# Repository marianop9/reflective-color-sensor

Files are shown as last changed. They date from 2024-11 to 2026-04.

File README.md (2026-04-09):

# Sensor de Colores por Reflexión

Este proyecto consiste en el diseño e implementación de un **sensor de color de bajo costo** capaz de estimar el color de una superficie y representarlo en formato RGB de 24 bits. El sistema utiliza una fotorresistencia (LDR) como transductor principal, compensando sus limitaciones mediante un proceso de caracterización empírica y un circuito de acondicionamiento activo.

## Características Principales
* **Hardware:** Basado en el microcontrolador **RP2040** (Raspberry Pi Pico).
* **Iluminantes:** LEDs RGB direccionables **WS2812**, controlados mediante el hardware PIO del RP2040 para máxima precisión.
* **Acondicionamiento:** Circuito de ganancia programable utilizando el switch bilateral **CD4066**, permitiendo medir un amplio rango de resistencias del LDR (1 k&Omega; a 1 M&Omega;) sin saturación.
* **Software:** Firmware desarrollado en C con **FreeRTOS** y **TinyUSB**. Aplicación de control en Python (CLI) para procesamiento de datos.



## Principio de Funcionamiento

El sensor opera utilizando la **reflexión secuencial**. El proceso se divide en los siguientes pasos:

1. **Aislamiento:** La carcasa diseñada bloquea la luz ambiente para evitar interferencias en la medición.
2. **Iluminación:** El dispositivo enciende secuencialmente los canales Rojo, Verde y Azul de los LEDs.
3. **Detección:** El LDR recibe la luz reflejada por la superficie. Su resistencia cambia según la intensidad recibida, y el circuito de acondicionamiento convierte este cambio en una tensión medible por el ADC.
4. **Procesamiento:** El microcontrolador envía los valores a una PC vía USB (CDC), donde se calcula el color final aplicando los parámetros de calibración.

## Caracterización y Calibración del LDR

Dado que los LDR presentan baja trazabilidad y una respuesta no lineal que varía según la longitud de onda , se implementó un procedimiento de **calibración por mínimos cuadrados**.

### El Modelo
Se modela la conductancia ($G$) del LDR en función de la intensidad de la luz ($c$) mediante la ecuación:
$$G = K_a c^{\gamma}$$
Donde $K_a$ y $\gamma$ son parámetros específicos para cada color y cada componente individual.

### Proceso de Calibración
1. Se realiza un **barrido logarítmico de intensidad** (de 0 a 255) para cada canal (R, G, B) sobre una superficie blanca de referencia.
2. Se recolectan las muestras de tensión y se ajusta automáticamente la ganancia ($R_f$) para mantener la señal en la zona lineal del ADC.
3. Mediante un script de Python, se aplica la técnica de **mínimos cuadrados** sobre los datos para hallar los coeficientes $K_a$ y $\gamma$ para cada color por separado.
4. Estos coeficientes se guardan en un archivo JSON que la aplicación CLI utiliza para convertir las mediciones posteriores en códigos de color precisos.

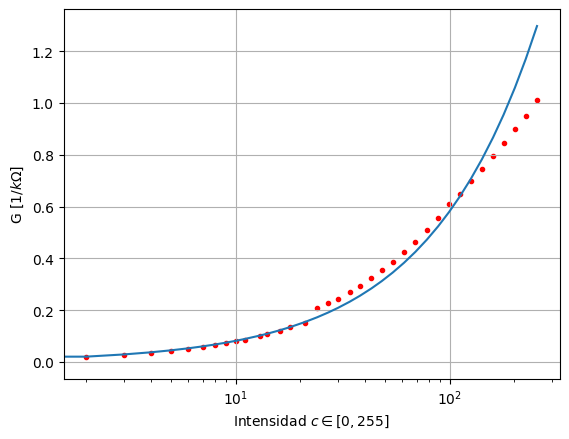
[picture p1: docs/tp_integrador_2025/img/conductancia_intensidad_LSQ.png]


## Estructura del Repositorio
* `/firmware`: Código fuente en C para el RP2040 (Pico-SDK).
* `/scripts`: Contiene la Aplicación CLI en Python y varios scripts de procesamiento de datos.
* `/hardware`: Modelado de las carcasas del dispositivo para impresión 3D.
* `/circuitos`: Esquemáticos del circuito de acondicionamiento y simulaciones en LTSpice.
* `/docs`: Informes técnicos detallados del proyecto.

## Resultados

Utilizando la siguiente hoja de prueba, se tomaron medidas de las superficies de color utilizando distintas aplicaciones móviles, bajo distintas condiciones de iluminación ambiente, y se compararon con las medidas obtenidas con el dispositivo.

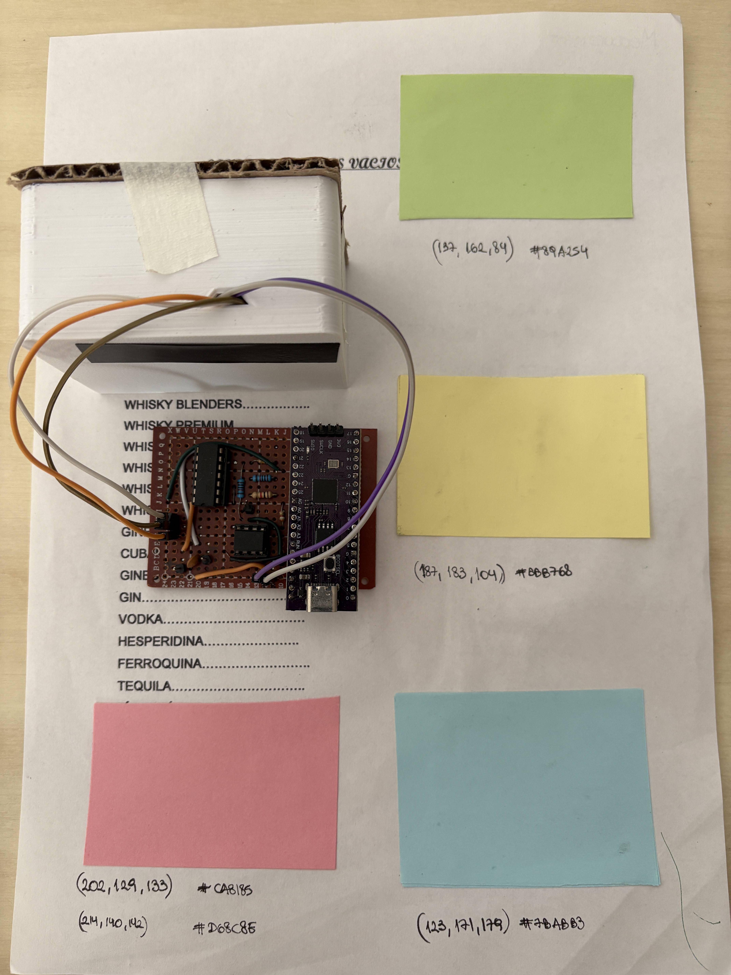
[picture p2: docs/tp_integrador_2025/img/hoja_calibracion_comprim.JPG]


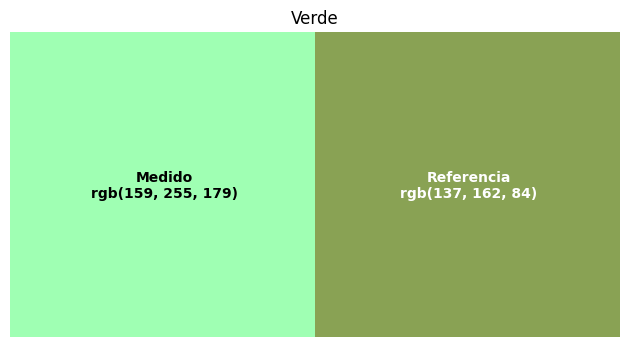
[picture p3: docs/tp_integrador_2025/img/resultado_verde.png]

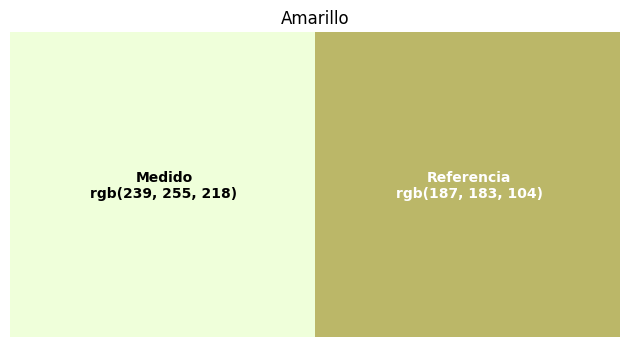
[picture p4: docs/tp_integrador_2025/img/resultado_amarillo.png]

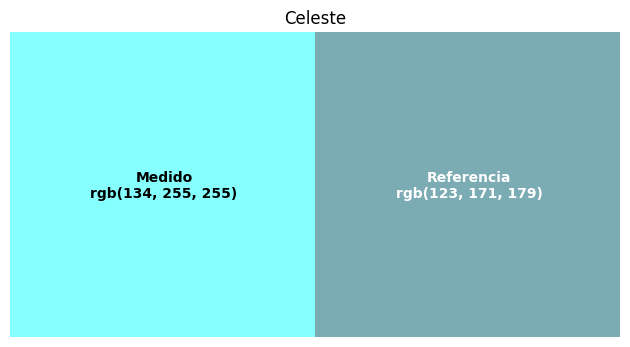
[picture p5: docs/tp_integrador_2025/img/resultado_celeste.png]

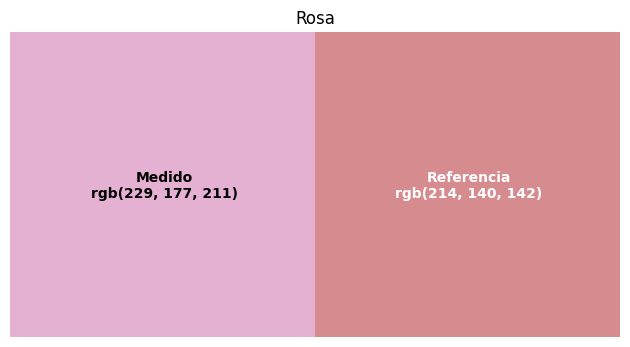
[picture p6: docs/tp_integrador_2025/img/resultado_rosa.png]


---

- **Autores:** Federico Beck & Mariano Perez 
- **Institución:** Universidad Tecnológica Nacional - Facultad Regional San Francisco.

Entregado como trabajo integrador de las materías Médidas Electrónicas II y Técnicas Digitales III.

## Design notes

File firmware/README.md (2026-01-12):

# Color Sensor Firmware

## Setup

Initialize FreeRTOS, pico-sdk submodules:

```sh
git submodule update --init
```

Configure CMake (run from root dir):

```sh
cmake -S . -B build
```

Build:

```sh
cmake --build .\build\
```

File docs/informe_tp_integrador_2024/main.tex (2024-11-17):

%Plantilla para informes desarrollados para la Universidad Tecnológica Nacional Regional San Francisco, para la carrera de Ingeniería Electrónica.

\documentclass[12pt,a4paper,twoside,fleqn]{article}
\usepackage{graphicx} % Required for inserting images
	\graphicspath{{./img}}
\usepackage{fancyhdr} % Requeried for header and footer
\usepackage{makecell} % Requeried for header image
\usepackage{indentfirst}
\usepackage[spanish]{babel} % Paquete de idioma
\usepackage[font=footnotesize]{caption}
\usepackage{subcaption}
	
\usepackage{hyperref} % Genera vínculos en referencias y citas 
\usepackage{amsmath}
\usepackage{siunitx}
	\sisetup{
		group-digits=false,
		output-complex-root=j
	}

\input{structure.tex}
    
\begin{document}
\renewcommand\refname {}
\renewcommand\headrulewidth{0pt} % no line between document and header
\fancyhead{} % clear header
\fancyfoot{} % clear footer
\pagestyle{fancy}
\setlength{\headheight}{24.0pt}

\fancyhead[L]{\footnotesize
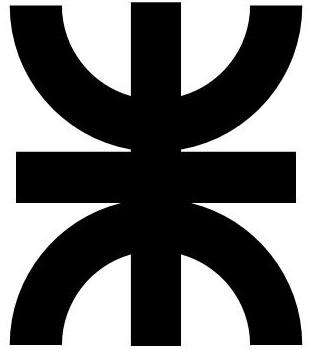
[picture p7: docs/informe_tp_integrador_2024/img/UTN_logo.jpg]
\mbox{\makecell[cl]{}}
\makecell[cl]{Universidad Tecnológica Nacional \\ 15 Noviembre Año 2024 %fecha 
}}

\fancyhead[R]{\footnotesize
\makecell[cr]{Trabajo Integrador $4^{\text{to}}$ año\\ Ing. Electrónica}}

\fancyfoot[L]{\thepage}

\vspace{\fill}
{\huge \noindent \textbf{Medición de colores por reflexión utilizando resistencias dependientes de la luz (LDR)}} % title 
\vspace{1.5cm}
\par
\noindent
\textbf{Beck, Federico (autor)}\\
Departamento de Ingeniería Electrónica,\\ Facultad Regional San Francisco, Córdoba, Argentina.\\
\href{mailto:federicobeck91@gmail.com}{federicobeck91@gmail.com}\par
\vspace{0.5cm}
\noindent
\textbf{Perez, Mariano (autor)}\\
Departamento de Ingeniería Electrónica,\\ Facultad Regional San Francisco, Córdoba, Argentina.\\
\href{mailto:perezmariano7401@gmail.com}{perezmariano7401@gmail.com}\par

\section*{RESUMEN}
Un sensor de colores por reflexión permite determinar con precisión el color de un objeto al iluminarlo con una fuente de luz y midiendo la luz reflejada en el mismo. Un sensor típico emite luz blanca hacia un objeto, y mide la reflexión de cada componente de la luz blanca utilizando un arreglo de fotodiodos con filtros RGB. 

El objetivo de este trabajo consiste en desarrollar un dispositivo que permita determinar el color de un objeto mediante la técnica de reflexión, pero utilizando resistencias dependientes de la luz (LDR) sin filtros de color. Para ello se utilizará un LED RGB y se medirá la reflexión para cada color por separado.
\par
\noindent\textbf{Palabras claves:} Medición, color, reflexión, LDR, RGB.

\section*{INTRODUCCIÓN}
El color es una percepción visual que surge debido a la detección de diferentes longitudes de onda que no son absorbidas por un objeto o superficie. El conjunto de señales de distintas frecuencias compone el color de dicho objeto. Éstas, dentro del espectro visible de la luz, abarcan una gama de colores que va desde el rojo, con frecuencias más bajas y longitudes de onda más largas, hasta el violeta, con frecuencias más altas y longitudes de onda más cortas.\cite{ARPN_RGB_COLOR_SENSING}

Uno de los métodos para medir el color es mediante un dispositivo de detección especializado. En este proyecto, se ha desarrollado dicho dispositivo junto con su procesamiento digital correspondiente.

%explicar primero como funciona un LDR
El sensor consta de dos etapas, la primera esta compuesta por el emisor, el detector y su circuito de acondicionamiento. El emisor es un LED RGB capaz de emitir luz roja, verde y azul por separado, la cual será reflejada sobre el objeto a medir e incidirá sobre el detector. El detector utilizado es una resistencia dependiente de la luz, la cual varía su resistencia dependiendo de la luz que incide sobre la misma. La variación de resistencia se debe convertir en una variación de tensión para que pueda ser procesada, para ello se utiliza una fuente de corriente constante. Luego, la caída de tensión en los terminales del LDR se inyecta en un amplificador de instrumentación con ganancia unitaria, el cual cuenta con un alto rechazo al modo común y entrega en su salida una tensión igual a la diferencia de tensión en el LDR, que será procesada por la segunda etapa.

La segunda etapa abarca la recolección de datos y su posterior procesamiento. Mediante el conversor analógico-digital (ADC) se toman muestras de la salida del amplificador de instrumentación cuando la superficie a medir se ilumina con los distintos colores del LED RGB. Las muestras recolectadas posteriormente se pasarán por un filtro digital, el cual permitirá eliminar el ruido de linea y estabilizar las muestras obtenidas por el ADC. Finalmente, los valores de tensión muestreados y filtrados se convierten en un valor entero de 8 bits, que representará la intensidad de luz reflejada de la componente roja, verde, o azul. Una vez que se obtienen los valores de 8 bits para los tres colores se muestra el resultado medido en una página web.

Cabe recalcar que todas las mediciones se deben realizar aisladas de la luz ambiente, esto se logra mediante una carcasa impresa en 3D 
% la referencia a la figura podemos dejarla para el desarrollo donde explicamos con mas detalle
(Fig. \ref{fig:vistas_carcasa}), ya que de no ser así el transductor estará percibiendo longitudes de ondas no solo del objeto al cual se desea medir su color, sino que también otras longitudes de ondas dispersas en el ambiente.

Por último, el sensor cuenta con un panel de control que permite solicitar una medición y visualizar el color medido. El mismo fue realizado en una página web, la  cual es servida por el microcontrolador encargado del muestreo y procesamiento de los datos del transductor.
% Por último los valores obtenidos son publicados en un servidor web, el cual entrega el código de color junto a un recuadro donde se puede observar que color se esta sensando. 

% explicar el principio de funcionamiento 
% mencionar que las mediciones se hacen aisladas de la luz ambiente

\section*{DESARROLLO}
\subsection*{Componentes del dispositivo}
Antes de comenzar con el desarrollo del dispositivo, se definieron las principales partes que lo componen. Diferenciando entre hardware y software se definieron los siguientes componentes:
\begin{itemize}
    \item Hardware
    \begin{itemize}
        \item LED RGB que actúa como iluminante.
        \item Transductor (LDR) con su respectivo circuito de acondicionamiento.
        \item Carcasa para aislar las mediciones de la luz ambiente.
        \item Microcontrolador Raspberry Pi Pico W para implementar las funcionalidades de software.
    \end{itemize}
    \item Software
    \begin{itemize}
        \item Lógica de control que coordine la actuación del iluminante con la medición del transductor mediante el conversor analógico-digital.
        \item Filtro digital para eliminar ruido de línea y estabilizar las mediciones del ADC.
        \item Procesamiento digital de las mediciones, transformando la tensión de entrada en el ADC a un valor de 8 bits correspondiente a cada color.
        \item Implementación de un servidor web que permita el control del sensor y visualizar los resultados.
        \item Funcionalidad adicional: transmisión de datos por puerto serie, etc.
    \end{itemize}
\end{itemize}
% componentes discretos: (hardware)
% - iluminante (led)
% - transductor - fuente de corriente - amplificación de instrumentacion
% - carcasa
% software (programado en un micro)
% - filtro digital
% - lógica de control que coordina los distintos elementos para realizar una medición
% - procesamiento de los valores obtenidos del ADC para determinar el color medido
% - funcionalidad web (servidor + página para visualizar las medidas)
% - funcionalidad extra (gráficos Python, comunicacion puerto serie)
A continuación se explicará el aporte de cada componente al dispositivo final, su funcionamiento y las consideraciones que se hicieron durante el diseño.

\subsubsection*{Carcasa, iluminante}
El módulo detector requiere de una fuente de luz capaz de emitir por separado luz roja, verde, y azul que será reflejada en la superficie objetivo y luego incidirá sobre el detector. Se utilizó un módulo LED RGB KY-016, el cuál integra resistencias de \qty{150}{\ohm}, simplificando el circuito de control y permitiendo que se pueda alimentar directamente de las salidas digitales del microcontrolador. 

Como se mencionó anteriormente, las mediciones deben realizarse aisladas de la luz ambiente. La única luz presente debe ser la reflejada en la superficie objetivo, por lo que inicialmente se realizó una carcasa prototipo en cartón. La carcasa debía contener el iluminante y el LDR, permitiendo que los mismos puedan ser conectados al resto del circuito minimizando el ingreso de luz externa que pueda afectar la respuesta del detector. Una vez determinadas las dimensiones óptimas, la carcasa se diseñó en FreeCAD y se imprimió utilizando una impresora 3D. En la Fig. \ref{fig:vistas_carcasa} se muestran vistas de la pieza final.

La carcasa es hueca en su interior, con una pared interna que la divide en dos compartimientos donde se colocan en el iluminante y el detector, tal como se observa en la Fig. \ref{fig:vista_inf_carcasa}. De esta manera se evita que el detector reciba luz directamente desde el iluminante, y asegura que la única luz que incide sobre el mismo es la que resulta de la reflexión de la luz sobre la superficie a medir.

\begin{figure}
    \centering
    \begin{subfigure}{.25\textwidth}
        \centering
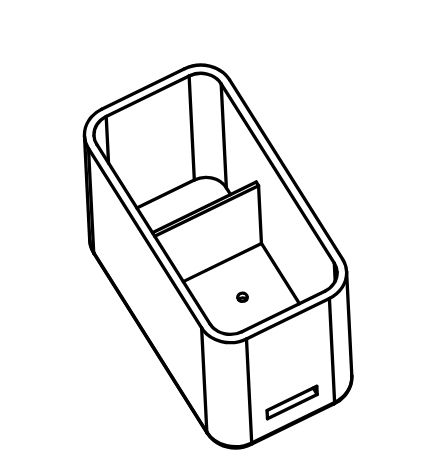
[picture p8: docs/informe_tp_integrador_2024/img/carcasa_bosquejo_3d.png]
        
        \caption{Vista en perspectiva.}
        \label{fig:bosquejo_carcasa}
    \end{subfigure}
    \begin{subfigure}{.25\textwidth}
        \centering
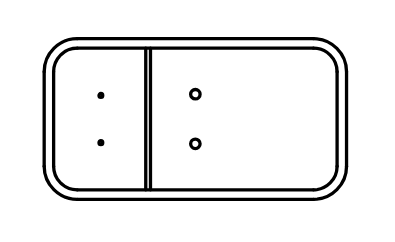
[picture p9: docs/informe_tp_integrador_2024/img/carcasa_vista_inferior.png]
        
        \caption{Vista inferior.}
        \label{fig:vista_inf_carcasa}     
    \end{subfigure}
    \caption{Vistas de la carcasa realizada.}
    \label{fig:vistas_carcasa}
\end{figure}

% ver si se puede juntar todo el circuito de acondicionamiento del LDR (LDR+fuente corriente+ampli instrumentacion) en una sola sección (salvo que quede demasiado largo)
\subsubsection*{Transductor}
El \textit{LDR} basa su funcionamiento en el principio de fotoconductividad, esto quiere decir que su resistencia variará en función de la cantidad de luz que recibe. En condiciones de poca luz presenta su máxima resistencia, esta irá disminuyendo a medida que la cantidad de luz que incida sobre el aumente.\par
En el caso especifico de la aplicación que este trabajo práctico tiene como objetivo, se tuvo que tener en cuenta algunas consideraciones en cuanto a este transductor. Una de ellas ya se ha mencionado anteriormente, la variación de la resistencia según la cantidad de luz recibida, pero otro detalle muy importante que se ha considerado es la respuesta del \textit{LDR} a las distintas longitudes de onda. Como ya sabemos, el \textit{LDR} responde a todo el espectro electromagnético tal como se ve en la Fig. \ref{fig:wave-ldr}, pero dentro de este espectro el transductor no producirá el mismo cambio de resistencia para el rojo, que para el verde o el azul. Esto se describirá de forma mas detallada dentro del apartado \textit{procesamiento digital}, donde se explicará el método de obtención y el cálculo para obtener el color que se este midiendo de la forma lo mas fiel a la realidad posible.

\begin{figure}
    \centering
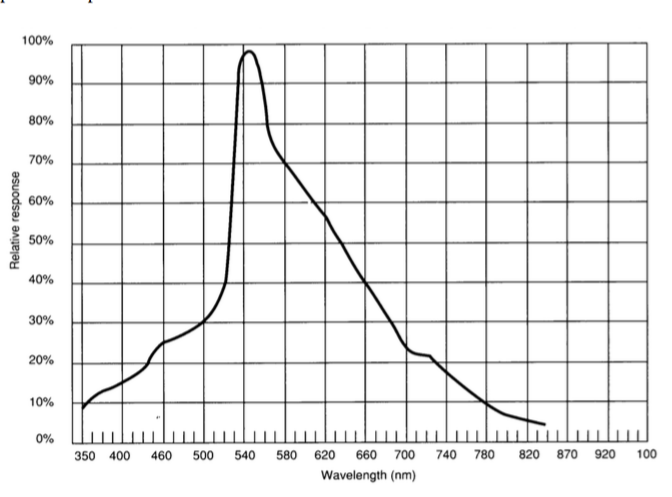
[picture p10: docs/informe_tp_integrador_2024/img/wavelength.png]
    
    \caption{Respuesta del transductor en base a la longitud de onda de la fuente de luz}
    \label{fig:wave-ldr}
\end{figure}

Se debe tener en cuenta que la luz reflejada depende no solo del color de la superficie, sino también de otras propiedades como su reflectividad\cite{avago_rgb_color_sensing}, por lo que se pueden obtener distintas mediciones para dos objetos del mismo color pero de distinta reflectividad, ya que la reflexión en el objeto menos reflectivo será menor y por lo tanto también la cantidad de luz incidente sobre el detector.
En el caso de tener una superficie rugosa, tendremos que tener en cuenta la fidelidad de la muestra, debido a que el haz de luz que incide sobre la superficie se dispersará de múltiples direcciones e incidirá menos luz en el detector, como en la Fig. \ref{fig:reflexión}.

\begin{figure}
    \centering
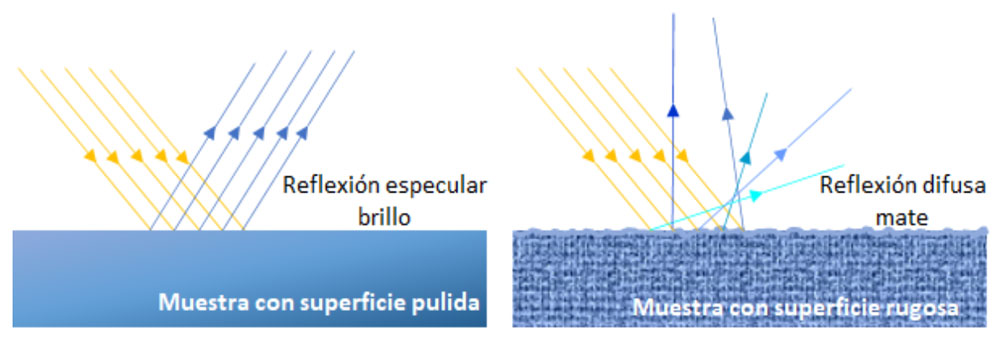
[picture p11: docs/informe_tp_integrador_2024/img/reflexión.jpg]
    
    \caption{Tipos de reflexiones}
    \label{fig:reflexión}
\end{figure}

\subsubsection*{Fuente de corriente constante}
Para poder cuantificar el valor de resistencia del transductor se ha utilizado una fuente de corriente constante, la cual cuenta con una tensión fija $V_r$ en el terminal no inversor del amplificador operacional mediante un divisor resistivo, como se puede observar en la Fig.\ref{fig:sensor}, mientras que la realimentación se hace a través del LDR al terminal inversor. La corriente a través del LDR va a depender del valor de la resistencia $R_{13}$.

Dado que el amplificador operacional se esta alimentando con $V_{CC}=\qty{5}{\V}$, utilizamos una tensión de referencia $V_r=\qty{2}{\V}$ para la fuente de corriente, de manera que la tensión en el LDR no pueda superar los \qty{3}{\V}. Esto se debe a que en la entrada del ADC del microcontrolador  no puede haber más de \qty{3.3}{\V}.
Por medio de pruebas físicas se ha asumido una resistencia máxima del LDR de \qty{1}{\Mohm}, por lo que la corriente a través del mismo será
\begin{equation*}
    I_{LDR} = \frac{V_r}{R_{max}} = \qty{3}{\uA}
\end{equation*}
Para lograr dicha corriente, el valor de la resistencia deberá ser
\begin{equation}
    R_{13} = \frac{V_r}{I_{LDR}} = \qty{667}{\kohm} \simeq \qty{680}{\kohm}
\end{equation}

Aplicando una corriente $I_{LDR}$ constante, la tensión en las terminales del LDR será siempre proporcional a la resistencia del mismo, por lo que la caída de tensión variará conforme varíe la resistencia del transductor Fig.(\ref{fig:variacion-ldr}).

La ecuación de la recta de color verde esta dada por la ecuación \ref{eq-V1}, la cual describe el aumento de la caída de tensión conforme aumenta la resistencia del LDR, es decir el mismo detecta menor cantidad de luz.

\begin{equation}
    V_1 = I_{LDR}\ R_{LDR}
    \label{eq-V1}
\end{equation}

\subsubsection*{Amplificador de instrumentación}
Para esta aplicación se ha implementado un amplificador de instrumentación con ganancia unitaria, al cual se le inyecta las tensiones de salida de la fuente de corriente constante, $V_2$ y $V_1$ Fig.(\ref{fig:sensor}).\par
Su implementación no fue estrictamente necesario, pero su uso ofrece diversas ventajas prácticas:

\begin{itemize}
    \item Aislamiento y protección de la señal.
    \item Reducción de ruido: cuenta con una alta capacidad de rechazo de modo común.
    \item Acondicionamiento del transductor junto con la fuente de corriente constante.
\end{itemize}

\begin{figure}
    \centering
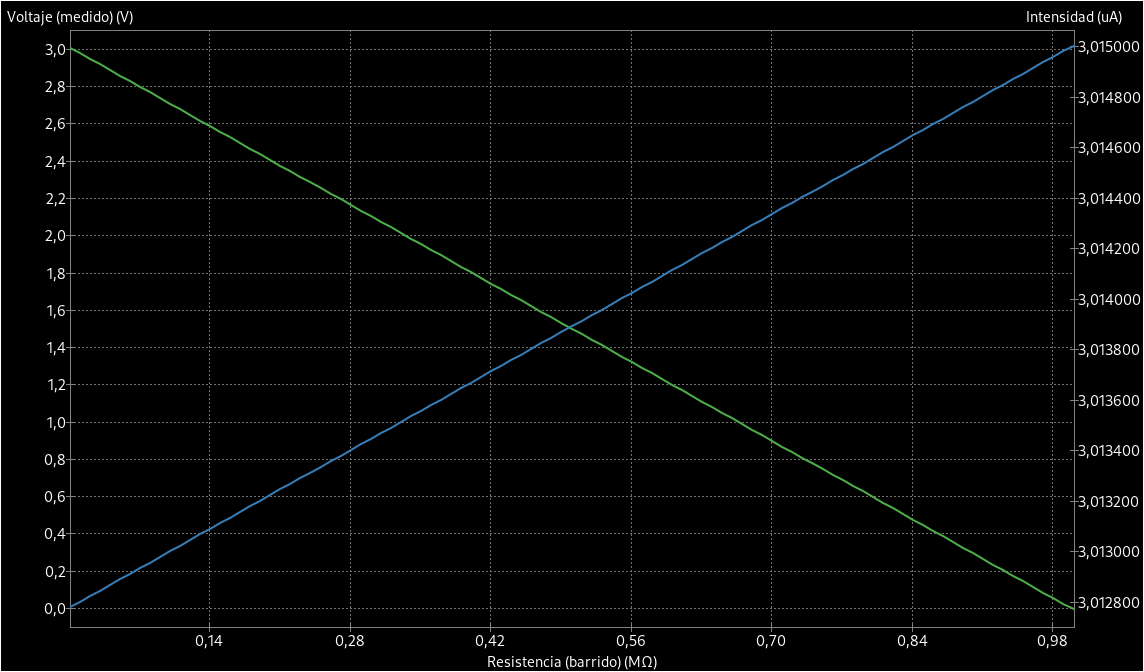
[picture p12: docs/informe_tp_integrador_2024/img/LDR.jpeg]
    
    \caption{Variación de tensión en base a la resistencia del LDR}
    \label{fig:variacion-ldr}
\end{figure}

\begin{figure}
    \centering
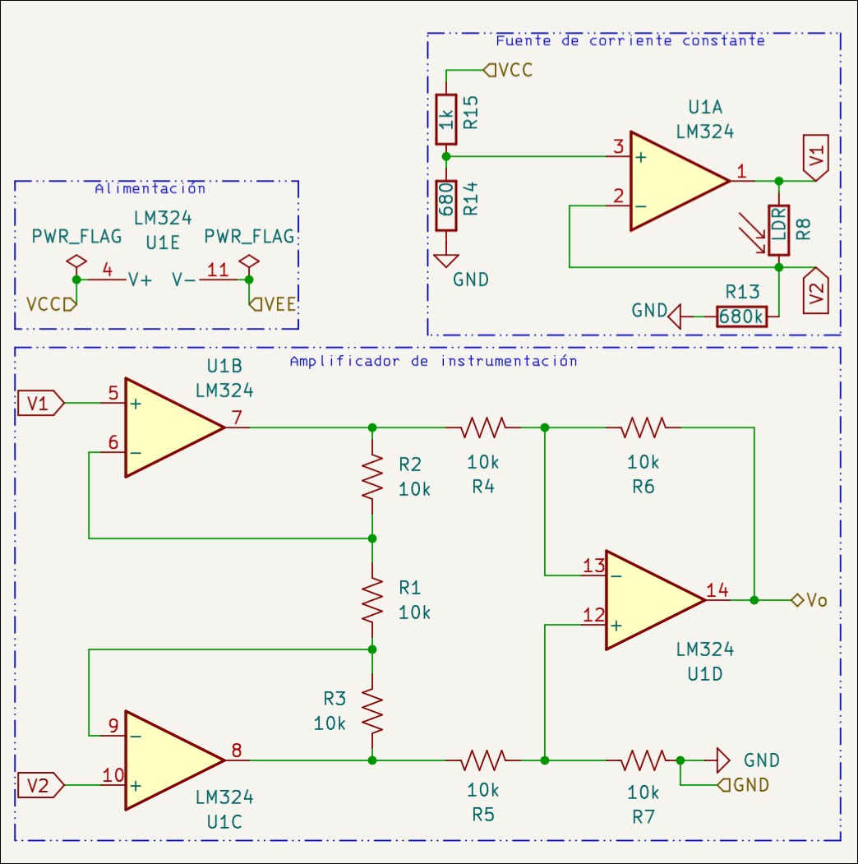
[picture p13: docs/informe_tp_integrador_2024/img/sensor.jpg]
    
    \caption{Conjunto transductor}
    \label{fig:sensor}
\end{figure}

\subsubsection*{Microcontrolador}
El microcontrolador elegido para este trabajo fue el Raspberry Pi Pico W. Entre sus principales características se destacan 3 ADC de 12 bits de aproximaciones sucesivas, 26 salidas digitales, capacidad Wi-Fi mediante una interfaz inalámbrica de \qty{2.4}{\GHz}, y un procesador de 2 núcleos Arm Cortex M0+. La capacidad de procesamiento del microcontrolador es más que suficiente para las tareas que requiere el sensor, las cuales incluyen el muestreo de la tensión resultante de iluminar el LDR, el filtrado digital y el procesamiento de los datos.

La capacidad Wi-Fi es útil ya que nos permite servir una página web mediante la cual se puede controlar el sensor e incluso mostrar los resultados de las mediciones. Aprovechando que los navegadores utilizan el estándar RGB para mostrar colores, a partir de la intensidad de luz reflejada de cada color podemos reconstruir el código RGB del color de la superficie medida y mostrarlo en la página web.

\subsubsection*{Lógica de control}
El sensor necesita coordinar múltiples componentes para realizar una medición. Una vez posicionada la carcasa sobre la superficie a medir se debe iluminar la superficie con uno de los tres colores del LED RGB, luego se espera un breve periodo de tiempo, entre \qtyrange{200}{500}{\ms}, a que el LDR se estabilice ya que estos elementos tienen una respuesta bastante lenta. 

Una vez estabilizada la respuesta del LDR, se inicia el muestreo del ADC del microcontrolador y se toman $n$ cantidad de muestras. Debido a que los valores muestreados por el ADC pasarán por un filtro, la cantidad $n$ de muestras se determina a partir de la respuesta del filtro y es la cantidad de muestras que se necesitan para que la salida del filtro se estabilice. Al alcanzar las $n$ muestras, se para el ADC, se comienzan a procesar las muestras recolectadas y en simultaneo, aprovechando las capacidades del microcontrolador se repite el mismo procedimiento para los dos colores restantes. 

Una vez terminado el muestreo y filtrado para los colores rojo, verde, y azul del LED RGB, se procede a transformar las lecturas del ADC en el valor de intensidad RGB correspondiente a cada color.

\subsubsection*{Filtro digital}
Pese a que el amplificador de instrumentación que forma parte del circuito acondicionador del LDR nos brinda un alto rechazo al modo común que es útil para eliminar en gran parte el ruido eléctrico presente en el circuito, las muestras tomadas por el conversor analógico digital del microcontrolador presentaban una leve variación. Concluimos que esta variación se debe principalmente al ruido eléctrico dentro del propio microcontrolador, que termina afectando las mediciones del ADC.

Con el fin de eliminar estas variaciones, se realizó un filtro digital pasa-bajos de respuesta al impulso infinita (IIR). El mismo se diseñó para una frecuencia de corte de \qty{10}{\Hz} y una atenuación de al menos \qty{20}{\dB} para \qty{50}{\Hz}, que debería ser más que suficiente para eliminar cualquier ruido eléctrico presente en la entrada del microcontrolador. Se eligió un filtro pasa-bajos de Butterworth de orden 2, que cumple con los requisitos de atenuación y nos brinda una respuesta plana en la banda de paso, ya que esperamos que la salida del filtro sea lo más constante posible.

La frecuencia de muestreo $f_s$ del ADC se fijó en \qty{500}{\Hz}, pese a que el ADC admite frecuencias de trabajo mucho mayores. Se eligió este valor luego de analizar la respuesta al escalón del filtro, y surge de un compromiso entre el tiempo que se necesita para tomar las muestras necesarias de cada color, y la cantidad de muestras que se deben tener en memoria al filtrar.

Antes de profundizar en la elección de la frecuencia $f_s$, es necesario considerar el momento en el que se comienza a tomar las muestras. El muestreo comienza una vez que la resistencia del LDR se estabiliza luego de que la superficie que se mide refleje más o menos luz sobre ella. Debido a que el LDR esta alimentado por una fuente de corriente constante la tensión en sus terminales, que luego pasa por el amplificador de instrumentación, es constante. Dicho esto, podemos afirmar que en la entrada del ADC tendremos una tensión constante durante todo el muestreo de un color. Dicho esto, al filtrar las muestras obtenidas estamos aplicando una señal de escalón sobre el filtro.

En la Fig. \ref{fig:step_resp} se comparan respuestas al escalón para distintas frecuencias de muestreo. Se probaron frecuencias desde \qtyrange{.1}{1}{\kHz} y se comparó el tiempo que tarda la salida en estabilizarse y la cantidad de muestras necesarias.
En la Fig. \ref{fig:step_resp_100} se observa que para $f_s=\qty{100}{\Hz}$ se necesitan apenas 20 muestras hasta que la salida se estabiliza, sin embargo, con un periodo de muestreo de \qty{.01}{\s} esto lleva un tiempo de \qty{20}{\ms}. Por otro lado, en la Fig. \ref{fig:step_resp_1000} vemos que la salida se estabiliza cerca de los \qty{.125}{\s}, pero requiere de 125 muestras. Optamos por tomar una frecuencia intermedia de \qty{500}{\Hz}, para la cual se requieren \qty{.15}{\s} y aproximadamente 75 muestras en lograr una salida estable, tal como se muestra en la Fig. \ref{fig:step_resp_500}.
\begin{figure}
    \centering
    \begin{subfigure}{.45\textwidth}
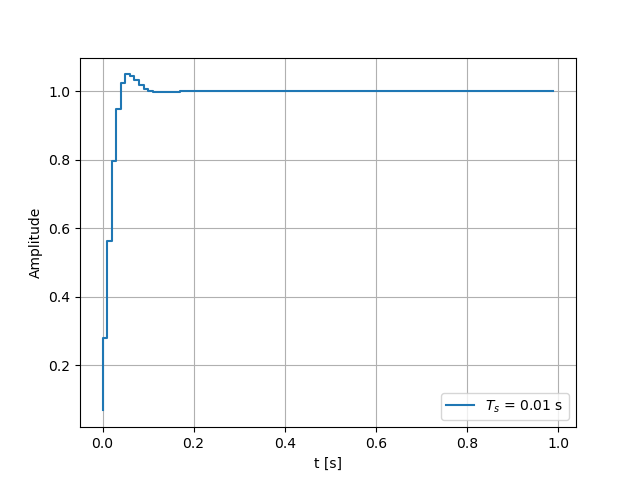
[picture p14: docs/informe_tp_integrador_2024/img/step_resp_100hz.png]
        
        \caption{Frecuencia de muestreo $f_s=\qty{100}{\Hz}$}
        \label{fig:step_resp_100}
    \end{subfigure}
    \begin{subfigure}{.45\textwidth}
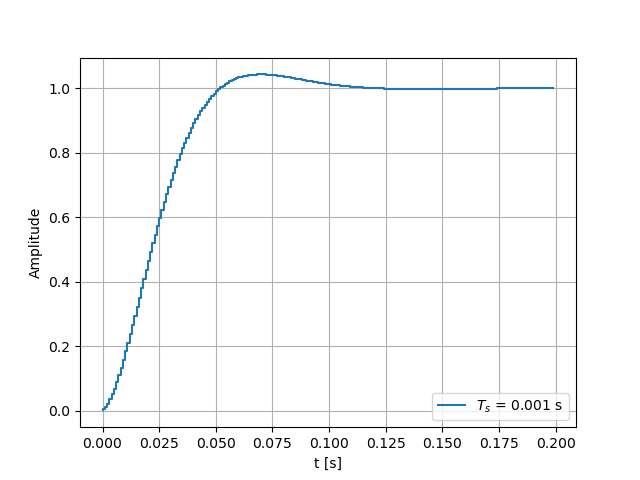
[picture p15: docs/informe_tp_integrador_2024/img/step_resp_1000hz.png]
        
        \caption{Frecuencia de muestreo $f_s=\qty{1}{\kHz}$}
        \label{fig:step_resp_1000}
    \end{subfigure}
    \begin{subfigure}{.45\textwidth}
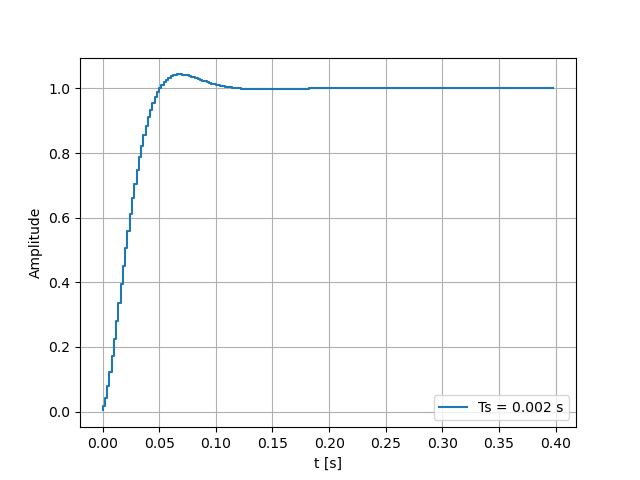
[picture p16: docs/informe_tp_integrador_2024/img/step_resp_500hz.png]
        
        \caption{Frecuencia de muestreo $f_s=\qty{500}{\Hz}$}
        \label{fig:step_resp_500}
    \end{subfigure}
    \caption{Respuestas al escalón para distintas frecuencias de muestreo.}
    \label{fig:step_resp}
\end{figure}

Una vez determinada la frecuencia de muestreo, se diseño un filtro antialiasing con el fin de suprimir cualquier componente de la señal cuya frecuencia sea mayor a la mitad de la frecuencia de muestreo $f_s$ para así evitar el efecto aliasing. El filtro es de tipo activo y analógico, con una frecuencia de corte $f_p$ menor a la frecuencia de Nyquist
\begin{equation*}
    f_p < \frac{f_s}{2} \longrightarrow f_p = \frac{f_s - \qty{10}{\Hz}}{2} = \qty{245}{\Hz}
\end{equation*}

\subsubsection*{Procesamiento digital}
La salida del amplificador de instrumentación, que es igual en magnitud a la tensión en el LDR, es inyectado en el ADC de 12 bits del microcontrolador. Con el fin de poder visualizar las mediciones, el valor de tensión presente en el ADC se debe convertir a un valor de 8 bits que represente la intensidad medida con cada color  y permita representar el color final como la combinación de las mediciones de rojo, verde y azul en formato RGB.

Sin embargo, la respuesta del LDR es inversamente proporcional a la cantidad de luz incidente: al aumentar la luz incidente sobre el mismo disminuye su resistencia, y por ende también la tensión muestreada por el ADC. Sumado a esto, se debe pasar del dato muestreado de 12 bits a un valor final de 8 bits.

Para convertir la tensión muestreada a un valor de color RGB, se realiza una transformación sobre el valor muestreado para cada color. Además, se debe tener en cuenta que el LDR no responde de igual manera a todas las longitudes de onda del espectro visible, por lo que podemos tener una respuesta distinta a las mismas intensidades pero de distintos colores. 

Para compensar la sensibilidad relativa a cada color, se midieron los valores presentes en el ADC para los tres colores del LED RGB por separado sobre superficies negras y blancas, y se tomaron estos valores como los límites del rango de posibles valores que puede haber en el ADC para cualquier medición. Esto significa que si el valor de una medición en el ADC es igual al valor calibrado para dicho color en superficies blancas, el valor para ese color es el máximo (0xFF), mientras que si el valor obtenido es igual al de superficies negras, el valor final correspondiente a ese color será el mínimo (0x00).

Una vez obtenidos los puntos límites como se visualiza en la Fig. \ref{fig:respuesta_ldr}, para cada color se determina la distancia relativa del valor medido a los límites de ese color. Luego, el resultado se multiplica por 255 para obtener el valor final de la intensidad del color. Dicho esto, la intensidad $H_{R,G,B}$ de cada color se puede obtener mediante la Ec. \eqref{eq:transformacion}, donde $ADC_K$ y $ADC_W$ son los valores límites, obtenidos para superficies negras y blancas, respectivamente.

\begin{equation}
    H_{R,G,B} = \frac{ADC_K - ADC_{R,G,B}}{ADC_K - ADC_W} \cdot 255
    \label{eq:transformacion}
\end{equation}

Para obtener los valores de $ADC_K$ y $ADC_W$ se utilizaron distintas superficies blancas y negras y se promediaron los valores muestreados y filtrados para obtener los valores límites para cada color. Sin embargo, luego fue necesario ajustar algunos valores manualmente hasta lograr mediciones aceptables. Los valores finales se muestran en la Tabla \ref{tab:calibracion_adc}.
\begin{table}
    \centering
    \begin{tabular}{c|c|c}
        Color & $ADC_W$ & $ADC_K$ \\
        \hline 
        R & 74 & 1015 \\
        G & 142 & 1067\\
        B & 94 & 807
    \end{tabular}
    \caption{Valores de ADC calibrados para cada color.}
    \label{tab:calibracion_adc}
\end{table}

La muestras recolectadas para cada color se filtran y pasan por la transformación de la Ec. \eqref{eq:transformacion}. Los valores obtenidos para cada color se combinan para formar el código del color medido por sensor, en la forma $rgb(H_R, H_G, H_B)$.

\begin{figure}
    \centering
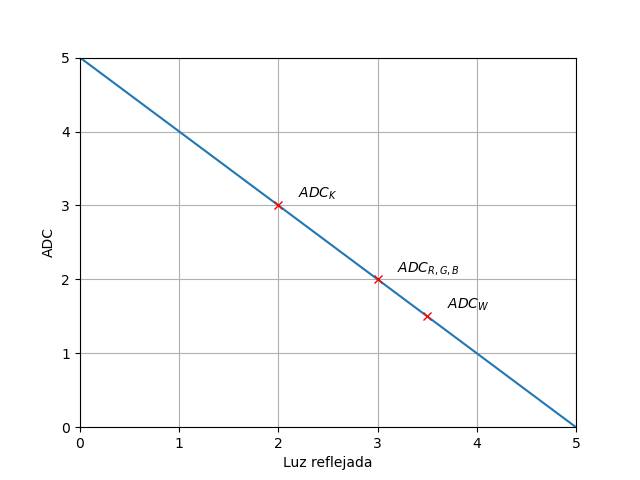
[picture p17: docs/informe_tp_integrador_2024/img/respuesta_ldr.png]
    
    \caption{Visualización de la respuesta del LDR entre sus puntos límites correspondientes a superficies blancas y negras.}
    \label{fig:respuesta_ldr}
\end{figure}

En base al procedimiento explicado, teóricamente cualquier color puede ser medido por el sensor y se puede obtener una buena aproximación, pero como se mencionó anteriormente también se debe tener en cuenta el tipo del material que se puede medir, ya que su reflectividad afectará inevitablemente a las mediciones. En cuanto a la resolución de la medición, el color medido se expresa utilizando el código de colores RGB, que es la misma que utilizan los navegadores web para mostrar colores. Este sistema utiliza tres valores de 8 bits para representar las intensidades de los colores rojo, verde y azul, los cuales conforman un color final. Si bien el muestreo y filtrado se hace utilizando datos de 12 bits para no perder información, al transformar al valor de intensidad en RGB, la medición final de cada color termina siendo un valor de 8 bits.

\subsubsection*{Servidor web}
Aprovechando las capacidades Wi-Fi del microcontrolador, se implementó un servidor web que permite acceder a una sitio web donde se puede accionar una medición y luego visualizar el color resultante. Se adjunta en el anexo una foto del circuito completo funcionando junto con la página donde se muestran las mediciones.

\section*{CONCLUSIONES}
En base a los resultados obtenidos midiendo superficies de distintos materiales y colores, concluimos que el dispositivo entrega resultados que consideramos aceptables para el alcance de este trabajo práctico. En el caso de objetos sólidos con superficie relativamente brillosa y de  color uniforme, las mediciones arrojaron colores similares al del objeto medido.

Durante el desarrollo del trabajo se notaron también las desventajas que trae el uso de la resistencia dependiente de la luz, ya que la sensibilidad de la misma varía según la longitud de onda de la luz incidente. Sumado a eso la respuesta un LDR no es constante incluso para otros LDR del mismo fabricante, por lo que los valores extremos utilizados para la linealizar la medición cambiarían al cambiar el LDR. Esto significa que cada LDR debe ser debidamente calibrado antes de ser utilizado en el sensor.

Pese a que las desventajas inherentes del LDR hacen este sensor inviable para mediciones de precisión, el sensor es capaz de identificar correctamente la intensidad relativa de cada componente del LED RGB (rojo, verde, o azul), y es capaz de determinar cual de estos colores son las principales componentes del color del objetivo. En la Fig. \ref{fig:resultados} del anexo se observa que el sensor arroja muy buenas aproximaciones del color de los objetos medidos. Dicho esto, se propone como una aplicación del sensor la identificación de colores. Para esta aplicación el sensor se podría configurar con los colores que se desea identificar, siempre y cuando haya una notable diferencia en sus componentes RGB, tal como en los objetos de la Fig. \ref{fig:resultados}, y luego el sensor podría aproximar cada medición a uno de los valores configurados. Sin embargo, el sensor siempre estará limitado por la baja velocidad de respuesta del detector LDR.

En cuanto a los objetivos prácticos, se logró diseñar un amplificador de instrumentación que se adapte a los requisitos del sensor, así como un filtro digital que elimine el ruido eléctrico y permita realizar una buena medición. Además, se analizaron cualitativamente los resultados de las mediciones y resultaron aceptables, sin embargo, no se pudo cuantificar la exactitud del sensor debido a que al momento del desarrollo no se contaba con un instrumento patrón con el cuál comparar la medición de colores.

\section*{REFERENCIAS}
\bibliographystyle{ieeetr}
\bibliography{Bibliography}

\newpage
\section*{ANEXO}
A continuación se muestran los resultados obtenidos de una serie de mediciones utilizando objetos plásticos de distintos colores.
\begin{figure}
    \centering
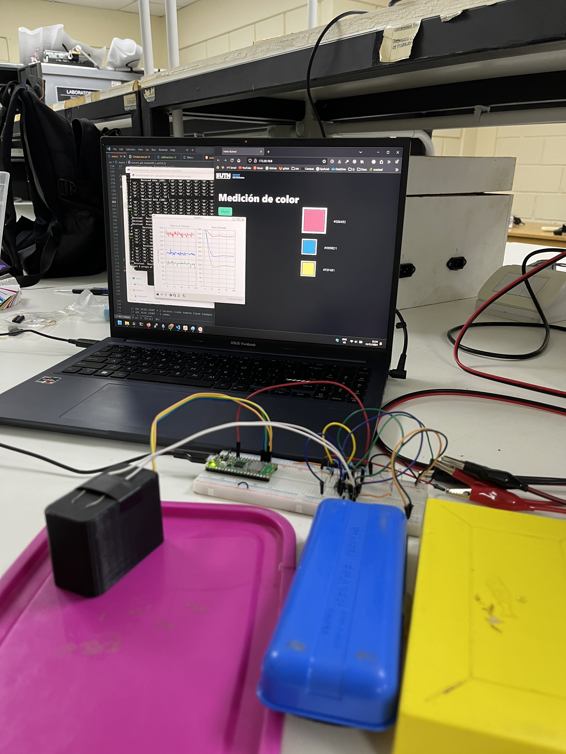
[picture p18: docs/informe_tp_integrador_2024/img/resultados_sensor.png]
    
    \caption{Mediciones del sensor.}
    \label{fig:resultados}
\end{figure}
\end{document}

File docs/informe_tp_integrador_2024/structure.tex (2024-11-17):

\usepackage{titlesec}

\DeclareCaptionFormat{label}{\fontsize{10}{10}\selectfont#1#2#3}

%\titleformat{\Comando de Estructura}[Tipo]{Formato}{Etiqueta}{Separación}{Código anterior}[Código posterior]

\titleformat{\section}[hang]
{\fontsize{14}{14}\bfseries}{\thesection.}{0.1cm}
{}

\titleformat{\subsection}[hang]
{\fontsize{12}{12}\bfseries}{\thesubsection.}{0.1cm}
{}

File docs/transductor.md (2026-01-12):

# transductor

Para un LDR:
$$R \approx k E^{-\gamma} = \frac{k}{E^\gamma}$$
donde,
- $E$ -> [[light units#Illuminance|illuminance]]
- $0.6 \le \gamma \le 0.9$ 

## desventajas

- es una aproximación en el mejor de los casos
- $\gamma$ varia mucho entre LDRs
    - requiere calibración
- la iluminancia depende de cuanta luz incide sobre el LDR, que a su vez depende de las propiedades reflectivas de la superficie que se mide
- no responde igual a todas las longitudes de onda del espectro visible

## objetivo

1. Desarrollar un sensor económico que pueda dar una buena aproximación del color de una superficie.
2. Que el mismo pueda ser calibrado contra una paleta de colores especifica y pueda determinar con precisión el color de un objeto cuyo color es uno de los calibrados.

## circuito de acondicionamiento

Amplificador operacional inversor con tensión de referencia.

![[circuito_acondicionador.png]]

Transforma la conductancia $G$ del LDR en una tensión $V_o$:

- $V_s = VCC = 5 \text{ V}$
- $V_+ = 3.3 \text{ V}$

$$
V_o = V_{+} + (V_+ - V_s) \frac{R_f}{R_{LDR}} = V_{+} + (V_+ - V_s) R_f G
$$

- $R_{LDR} \ll R_f \,:\quad V_o \to -\infty \,(0\,\text V)$  
- $R_{LDR} = R_f \,:\quad V_o =V_{+} + (V_+ - V_s) = 3.3 + (5-3.3) = 1.6\,\text V$
- $R_{LDR} \gg R_f \,:\quad V_o \to 3.3\,\text V$

Utiliza múltiples resistencias $R_f$ mediante un mux analógico para evitar la saturación debido al gran rango de resistencia del LDR.

![[acondicionamiento.png]]

La tensión de salida es:
$$
V_o = 3.3 + (3.3 - 5) R_f G
$$

$$
V_o = b + a R_f G
$$

$V_o$ es función de $G$, $V_o(G)$.
## lectura ADC

Suponiendo ADC 12 bits, a 3.3 V:
$$
D = \frac{4095}{3.3\text V} V_o(G)
$$
$$
D = \frac{4095}{3.3\text V} (a+bR_f G)
$$

La resistencia $R_f$ se elige mediante el mux, por lo que es conocida y se puede dividir para quitarla la medición. Se obtiene un valor *"normalizado"* $D^*$:

$$
D^* = D/R_f = \frac{4095}{3.3\text V} (\frac{a}{R_f}+bG)
$$

En cada medición hay que quitar el offset propio del LDR, ya que el $V_o$ medido en ausencia de iluminación (con los LEDs apagados) no necesariamente es 0. El valor *normalizado y compensado* $D'$ es:
$$
D' = D^* - D^*_{\text{dark}}
$$

$D'$ también es  función de $G$: $D'(V_o(G))$.

## interpretación

Cada medición $D'$ se transforma la conductancia $G$ equivalente.

De la ec. del LDR:
$$
G \approx {\alpha}{E^\gamma}
$$

Nos interesa $E$. La iluminancia, o la cantidad de luz que incide sobre la superficie del LDR. Esto nos dará una idea del color de la superficie.

No se conoce ni $\alpha$ ni $\gamma$, son las variables que deseamos calcular.

> En realidad, la luz que incide sobre el LDR depende también de las propiedades de la superficie que se mide. Una superficie mas brillante reflejará mas luz que una superficie opaca. Es por esto que se ajustó el ángulo al que se colocan los LEDs para minimizar la reflexión especular. En este caso se busca medir solo la *reflexión difusa*.

## parametrización del LDR

Se tomarán mediciones con el sensor sobre una superficie blanca arbitraria. Se tomaran medidas para cada canal $[R, G, B]$ por separado, a distintos niveles de intensidad $I$ (ej. $(10,20,\dots,100\%)$).

Para un WS2812, la intensidad de cada canal se codifica en un valor de 8 bits: $I \in [0-255]$

Dado que es imposible conocer la iluminancia $E$ exacta producida por los LEDs en cada nivel de intensidad $I$, lo mejor que podemos hacer es estimar la cantidad de luz que incide sobre su superficie modulando la *intensidad* $I$ (el brillo) de los LEDs. 

Al reducir la intensidad de los LEDs, disminuye la cantidad de fotones emitidos, por lo tanto disminuye la cantidad de luz que recibe el LDR, por lo tanto:

$$
E \approx I
$$

Recolectando las mediciones tenemos un mapa de conductancia-intensidad: $G \leftrightarrow I$

Dado que la lectura del ADC $D'$ es una función lineal de G, podemos expresar:

$$
D' = \frac{4095}{3.3\text V} (\frac{a}{R_f}+b \alpha I^\gamma)
$$

$$
D' = A + BI^\gamma
$$
$A$ es conocida, por lo tanto
$$
D' - A = BI^\gamma
$$
- variables: $B, \gamma$

Aplicando mínimos cuadrados podemos obtener las variables desconocidas:

$$
\ln(D'-A) = \ln(B)+\gamma \ln(I)
$$

$$
\begin{bmatrix}
1 & \ln(I_1) \\
1 & \ln(I_2) \\
\vdots &  \vdots \\
1 & \ln(I_N) & \\
\end{bmatrix}
\begin{bmatrix}
\ln B \\
\gamma 
\end{bmatrix}
\approx 
\begin{bmatrix}
\ln(D'_1-A) \\
\ln(D'_2-A) \\
\vdots \\
\ln(D'_N-A) \\
\end{bmatrix}
$$

Aplicando este proceso para cada canal, se obtienen las variables 
$$
(B_x, \gamma_x) \qquad,\, x \in [R, G, B]
$$

A esta altura, deberíamos tener una buena aproximación de la respuesta LDR para distintas cantidades de luz incidente sobre su superficie.

> Una vez conocidos todos los valores para cada canal, se puede generar una LUT entre los valores del ADC y la intensidad resultante para disminuir el procesamiento requerido en cada medición.

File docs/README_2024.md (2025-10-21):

# Sensor de Colores por Reflexión

Este proyecto fue desarrollado como parte del trabajo práctico integrador de las materias Electrónica Aplicada II, Teoría de Circuitos II y Medidas Electrónicas I. Explora el uso de un sensor LDR (Resistor Dependiente de la Luz) en combinación con fuentes de luz controladas para detectar e interpretar colores de manera experimental. Aunque los LDR no son sensores de color por sí mismos, este proyecto demuestra cómo se pueden utilizar técnicas creativas y económicas para aproximarse a esta funcionalidad.

## Descripción
El sistema utiliza un sensor LDR para medir la intensidad de la luz reflejada por un objeto bajo la iluminación de LEDs de colores (rojo, verde y azul). Al analizar las variaciones en las lecturas del LDR según el color de la luz emitida, el dispositivo realiza una estimación del color del objeto utilizando el código de colores HEX. Este enfoque es ideal para aplicaciones educativas y de bajo costo.

## Características
- Uso de un sensor LDR como alternativa económica a sensores de color dedicados.
- Implementación de un servidor web para realizar las mediciones y visualizar los resutlados.
- Utiliza un filtro digital para estabilizar las mediciones.
- Carcasa impresa en 3D para aislar las mediciones de la luz ambiente.
- Diseño modular que permite experimentar con diferentes configuraciones de iluminación.
- Código abierto y documentado para fines educativos.

funcionamiento del sensor

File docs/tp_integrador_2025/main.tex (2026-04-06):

\documentclass[12pt,a4paper,fleqn]{article}
\usepackage{graphicx}
	\graphicspath{{./img}}
\usepackage{fancyhdr}
\usepackage{makecell}
\usepackage{indentfirst}
\usepackage[spanish]{babel}
\usepackage{csquotes}
\usepackage[font=footnotesize]{caption}
\usepackage{subcaption}
\usepackage{biblatex}
\addbibresource{Bibliography.bib}

\usepackage{amsmath}
\usepackage{siunitx}
	\sisetup{
		group-digits=false,
		output-complex-root=j
	}
\usepackage{hyperref}
\usepackage[spanish,capitalise]{cleveref}

\usepackage{listings}
\renewcommand\lstlistingname{Listado}

\begin{document}
\renewcommand\refname{}
\renewcommand\headrulewidth{0pt} % no line between document and header
\fancyhead{} % clear header
\fancyfoot{} % clear footer
\pagestyle{fancy}
\setlength{\headheight}{24.0pt}

\fancyhead[L]{\footnotesize
    \mbox{\makecell[cl]{}}
    \makecell[cl]{
        Universidad Tecnológica Nacional \\
        8 Abril Año 2026
    }}

\fancyhead[R]{\footnotesize
    \makecell[cr]{
        Técnicas Digitales III, Medidas Electrónicas II \\
        Ing. Daniele, Fernando --- Ing. Bossio, Jorge
    }}

\fancyfoot[L]{\thepage}

\vspace{\fill}
{\huge \noindent \raggedright \textbf{Desarrollo de un Sensor de Colores por Reflexión} \par} % title 

\vspace{1.5cm}
\noindent
\textbf{Beck, Federico}\\
Departamento de Ingeniería Electrónica,\\ Facultad Regional San Francisco, Córdoba, Argentina.\\
\href{mailto:federicobeck91@gmail.com}{federicobeck91@gmail.com}\par
\vspace{0.5cm}
\noindent
\textbf{Perez, Mariano}\\
Departamento de Ingeniería Electrónica,\\ Facultad Regional San Francisco, Córdoba, Argentina.\\
\href{mailto:perezmariano7401@gmail.com}{perezmariano7401@gmail.com}\par

\newpage
\tableofcontents
\newpage

\section{Resumen}
Se diseñó e implementó un sensor de colores por reflexión de bajo costo, capaz de estimar el color de una superficie y expresarlo como un código de color de 24 bits en formato RGB. El dispositivo emplea una resistencia dependiente de la luz como sensor, iluminando la superficie objetivo de forma secuencial con diodos emisores de luz de cada color, y midiendo la intensidad de la luz reflejada en cada caso.

Dado que los LDR suelen tener baja trazabilidad y amplia variación en su respuesta espectral, se desarrolló un procedimiento de caracterización basado en mínimos cuadrados para modelar su comportamiento ante cada longitud de onda. Se diseñó un circuito de acondicionamiento y se utiliza un microcontrolador para comunicarse con una computadora mediante puerto serie virtual.

Se validó el funcionamiento del dispositivo y del proceso de calibración comparando los resultados obtenidos sobre superficies de distintos colores con los de una aplicación móvil de referencia. 

\noindent\textbf{Palabras clave:} Sensor de color, fotorresistencia, LDR, reflexión, calibración.

\section{Introducción}

El color es una percepción visual que surge debido a la detección de diferentes longitudes de onda que no son absorbidas por un objeto o superficie. El conjunto de señales de distintas frecuencias compone el color de dicho objeto. Éstas, dentro del espectro visible de la luz, abarcan una gama de colores que va desde el rojo, con frecuencias más bajas y longitudes de onda más largas, hasta el violeta, con frecuencias más altas y longitudes de onda más cortas.

Durante el desarrollo de este trabajo, se diseñó e implementó un dispositivo que permite obtener un estimado del color de una superficie mediante la reflexión de luz. Este utiliza una resistencia dependiente de la luz (LDR) para la detección de la luz reflejada desde la superficie objetivo.

El principio de funcionamiento consiste en colocar el dispositivo sobre la superficie que se desea medir, y los iluminantes del sensor iluminan la superficie utilizando luz roja, verde, y azul por separado. Una vez iluminada la superficie, se mide la resistencia del LDR, y se estima la intensidad de la luz reflejada. El proceso se repite para cada color, y al final se obtiene una estimación del color de la superficie mediante un código RGB de 24 bits, el cual es un formato común y ampliamente utilizado para representar color, en especial de forma digital.

Debido a la baja trazabilidad de los LDR en general y su amplio rango de respuesta (generalmente desde unos cuantos kilo-ohmios hasta el orden de los mega-ohmios), que además varía según la longitud de onda de la luz incidente, se implementó un procedimiento para caracterizar la respuesta del LDR. El objetivo es determinar la respuesta del LDR a las distintas longitudes de onda para mejorar las mediciones obtenidas.

Para tomar las mediciones se desarrolló un circuito de acondicionamiento para el LDR y la placa de desarrollo Raspberry Pi Pico, que utiliza el microcontrolador RP2040. El microcontrolador a su vez implementa un protocolo de comunicación simple mediante USB (utilizando la clase de comunicación puerto serie virtual), que le permite funcionar como dispositivo USB e intercambiar mensajes con una PC u otro host USB\@.

Por último, se desarrolló una aplicación CLI (interfaz de línea de comandos), que permite la comunicación con el dispositivo a través de USB\@. La principal motivación fue para facilitar el análisis de datos y la caracterización del LDR utilizando lenguajes de programación de alto nivel, tales como Python.

\subsection{Antecedentes}

Las opciones comerciales de este tipo de dispositivos suelen medir color al incidir sobre la superficie objetivo, rayos provenientes de una fuente de luz blanca. El color se determina mediante un arreglo de foto-detectores, que generalmente consisten de foto-diodos con filtros RGB; cada foto-diodo detecta la intensidad de luz reflejada para una longitud de onda especifica, y se determina el color de la superficie en base a las intensidades relativas de luz captadas por cada uno. Este trabajo busca explorar la posibilidad de cumplir la misma función utilizando componentes más fácilmente accesibles y económicos, compensando las desventajas evidentes del LDR mediante una secuencia de calibración que permita obtener resultados repetibles.

\subsection{Objetivos}

El objetivo de este trabajo consiste en desarrollar un dispositivo de bajo costo que permita determinar el color de un objeto con un grado de precisión aceptable mediante la reflexión de luz sobre su superficie. A su vez, se implementará un procedimiento de calibración para conocer la respuesta del LDR utilizado en el dispositivo. Para facilitar la operación y el procesamiento de las mediciones, se desarrollará además una aplicación de escritorio que permita interactuar con el dispositivo y visualizar los resultados obtenidos.

\section{Desarrollo}
A continuación se describen en detalle los distintos aspectos del dispositivo, incluyendo el hardware utilizado y el circuito de acondicionamiento del LDR, asi como la implementación del firmware del microcontrolador y la aplicación CLI\@.

Todo el contenido desarrollado en el presente informe, incluyendo el código de fuente del microcontrolador, aplicación de escritorio y esquemáticos y simulaciones de los circuitos se pueden encontrar en el repositorio de GitHub \href{https://github.com/marianop9/reflective-color-sensor}{github.com/marianop9/reflective-color-sensor}.

\subsection{Descripción del Dispositivo}
% - componentes: 
%     - carcasa ✔️
%     - uC ✔️
%     - LED ✔️
%     - LDR ✔️

El dispositivo en su forma más simple consiste de un LDR que actúa como transductor, y un iluminante que hace incidir luz de color rojo, verde y azul sobre la superficie objetivo. Dado que el LDR varía su resistencia en base a la cantidad de luz que incide sobre su superficie, es necesario convertir este cambio de resistencia en una tensión que pueda ser muestreada por un conversor analógico-digital (ADC). Para ello se diseño un circuito de adaptación, descrito en detalle en el \cref{sec:circ_acond}, que convierte la resistencia del LDR en tensión, y es capaz de funcionar sobre un amplio rango de valores de resistencia.

% carcasa
Para poder tomar mediciones es necesario aislar el dispositivo de la luz ambiente, ya que esta interferiría con los iluminantes propios del dispositivo y distorsionaría las mediciones. Por ello, se diseñó una carcasa especializada donde los iluminantes y el LDR pueden funcionar sin interferencia de la luz externa. Las vistas frontal e inferior se muestran en la \cref{fig:vistas_carcasa}.

La misma cuenta con dos compartimientos internos. El compartimiento inferior se apoya sobre la superficie objetivo y es iluminado por los LEDs; en la vista inferior de la \cref{fig:vistas_carcasa} se observa las ranuras donde van colocados los dos LEDs utilizados. El LDR se coloca en el compartimiento central, que se conecta con el compartimiento inferior mediante una pequeña apertura, lo que permite que la luz reflejada incida directamente sobre la superficie del LDR. Por último, el compartimiento superior se utiliza para las conexiones eléctricas de todos los componentes, y cuenta con una salida al exterior de la carcasa donde estos se conectan al circuito de acondicionamiento y microcontrolador.

% TODO! foto de carcasa

\begin{figure}
    \centering
    
    \caption{Vistas de la carcasa diseñada para el dispositivo.}
    \label{fig:vistas_carcasa}
\end{figure}

% micro
Como se mencionó anteriormente, el dispositivo está basado en la placa de desarrollo Raspberry Pi Pico, que utiliza el microcontrolador RP2040~\cite{RP2040_datasheet}. Este cuenta con dos núcleos ARM Cortex-M0+, ADC de 12 bits, e implementa la capa física del protocolo USB, que permite su funcionamiento como dispositivo USB. El microcontrolador cuenta con más que suficiente poder de procesamiento para esta aplicación, pero su elección se basa principalmente en su disponibilidad y bajo costo, la facilidad de programación, y la capacidad de implementar interfaces de hardware específicos, cuya utilidad se discute a continuación.

% LEDs
El sensor utiliza LEDs RGB WS2812 como emisores, ya que cuentan con un factor de forma compacto, intensidad regulable, y un protocolo de comunicación sencillo. Este protocolo se basa en una señal cuadrada, donde la longitud de los pulsos altos y bajos definen un 0 lógico o 1 lógico. De esta forma se envía un código RGB de 24 bits que define el color de luz emitido por cada LED.

Pese a la simpleza del protocolo de comunicación, este funciona a una frecuencia elevada, de alrededor de \qty{800}{\kHz}. Las implementaciones típicas de drivers para estos dispositivos suelen consistir de procedimientos de `bit-banging' altamente optimizados, normalmente escritos directamente en lenguaje ensamblador. Sin embargo, el microcontrolador RP2040 incluye hardware especializado para desarrollar interfaces de hardware especializados, denominado I/O programable (PIO)~\cite{RP2040_datasheet}.

Las capacidades PIO del RP2040 permiten crear sub-programas que no requieren tiempo de procesador y pueden controlar los puertos GPIO del microcontrolador de manera precisa y confiable, lo que lo hace ideal para la implementación de un driver para los LEDs WS2812.

% LDR
Durante el desarrollo se probaron varios LDR de sulfuro de cadmio (CdS) en distintas condiciones de iluminación y se comprobó que todos tienen respuestas distintas ante los mismos estímulos de luz. Sin embargo, se pudo establecer que toman valores de resistencia en el rango de \qtyrange{1}{1000}{\kohm}. Además, tal como lo indica la hoja de datos del LDR GL5528~\cite{LDR_datasheet} utilizada como referencia, y la \cref{fig:LDR_respuesta_espectral}, un LDR típico tiene distintas sensibilidades según la longitud de onda de la luz incidente.

Por estos motivos, se decidió desarrollar un procedimiento de calibración, que se debe realizar antes de tomar mediciones. Otros aspecto a mencionar de los LDR es que su respuesta no es lineal, sino que su resistencia disminuye exponencialmente con la luminancia, es decir, con la cantidad de luz que incide sobre la superficie sensible del LDR. La respuesta típica del LDR puede aproximar con la \cref{eq:respuesta_LDR_R}.

\begin{equation} \label{eq:respuesta_LDR_R}
    R = K_a E^{-\gamma}
\end{equation}

\begin{figure}
    \centering
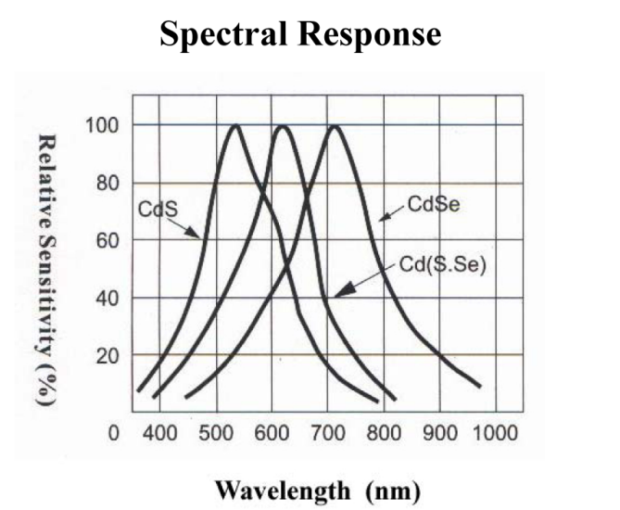
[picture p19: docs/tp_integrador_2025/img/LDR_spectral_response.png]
    
    \caption{Respuesta espectral del LDR GL5528 según su hoja de datos.}
    \label{fig:LDR_respuesta_espectral}
\end{figure}

\subsection{Circuito de Acondicionamiento}\label{sec:circ_acond}

% - op amp
% - cd4066
% - ecuacion G->Vo
% - grafico de respuesta ideal

\begin{figure}[h]
    \centering
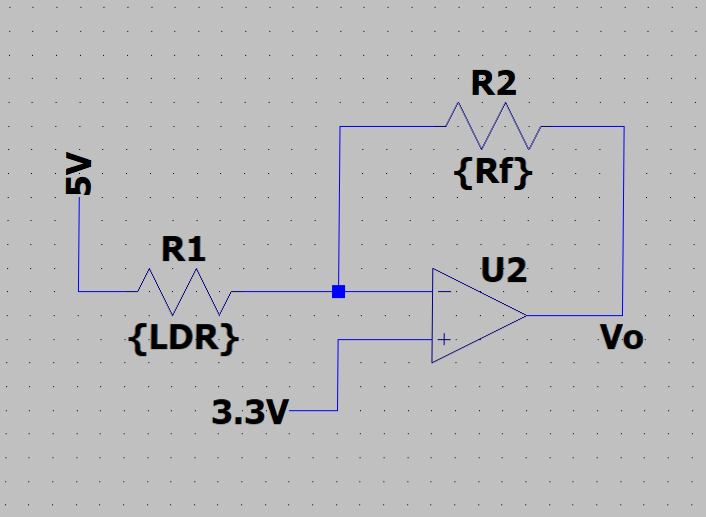
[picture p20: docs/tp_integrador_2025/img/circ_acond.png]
    
    \caption{Esquemático del circuito de acondicionamiento.}
    \label{fig:circ_acond}
\end{figure}

Un LDR disminuye su resistencia conforme aumenta la cantidad de luz que incide sobre su superficie sensible, es decir, la iluminancia. Para poder medir estos cambios de resistencia y poder determinar cuanta luz se refleja desde la superficie objetivo al LDR, se construyó el circuito de la \cref{fig:circ_acond}. Este consiste de un amplificador inversor con una tensión de offset fija en su terminal no inversor.

La tensión $V_o$ a la salida del amplificador operacional de la \cref{fig:circ_acond} se puede expresar como:

\begin{equation} \label{eq:circ_acond_R}
    V_o = V_{+} + (V_{+} - V_{s}) \frac{R_f}{R_{LDR}}
\end{equation}

, donde $V_{+}$ es la tensión de referencia en la entrada no inversora (\qty{3.3}{\V}), $V_s$ es la tensión a la que se conecta una de las terminales del LDR (\qty{5}{\V}), y $R_f$ y $R_{LDR}$ corresponden a la resistencia de realimentación y el LDR, respectivamente.

La tensión de referencia $V_+$ se eligió de manera tal que coincida con la tensión de referencia del ADC, que en el caso del RP2040 es de \qty{3.3}{\V}\cite{RP2040_datasheet}. De esta forma, se protege al ADC ya que la tensión de salida del circuito de acondicionamiento nunca superará este valor, y a la vez, permite a todo el dispositivo funcionar con una única fuente de alimentación de \qty{5}{\V}.

Además, debido al amplio rango de valores de resistencia que puede tomar el LDR, se utilizaron distintos valores de resistencia $R_f$ que permiten ajustar la ganancia del circuito de acondicionamiento. De lo contrario, utilizando una resistencia $R_f$ fija, el circuito solo funcionaría dentro de un rango limitado de la respuesta del LDR, y quedaría saturado para valores de resistencia fuera de este rango.

Por este motivo, el circuito de adaptación utiliza tres valores de resistencia $R_f$ discretos, \qtylist{1;10;100}{\kohm}, que aseguran que la respuesta del circuito no se sature en el rango de funcionamiento del LDR previamente establecido (\qtyrange{1}{1000}{\kohm}). La \cref{fig:respuesta_circuito} muestra la respuesta del circuito para los distintos valores de resistencia $R_f$.

\begin{figure}[h]
    \centering
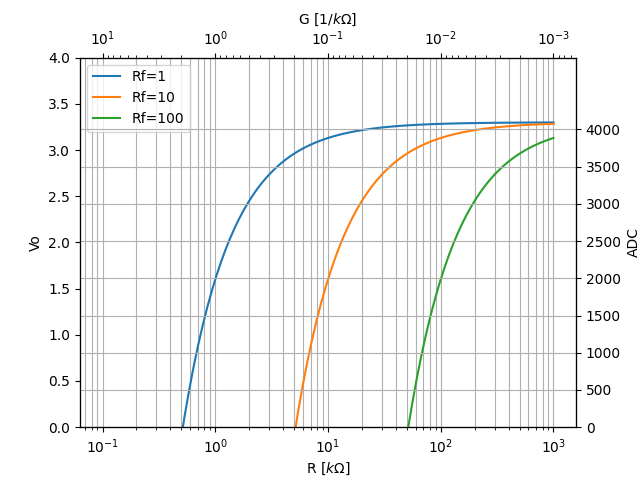
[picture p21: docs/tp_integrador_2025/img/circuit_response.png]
    
    \caption{Tensión de salida del circuito de acondicionamiento en función de la resistencia del LDR.}
    \label{fig:respuesta_circuito}
\end{figure}

Se utilizó el switch bilateral cuádruple CD4066~\cite{cd4066_datasheet} para permitir el control programable de la resistencia $R_f$. Este circuito cuenta con cuatro canales independientes y está ampliamente disponible.

\subsection{Caracterización del LDR}\label{sec:caracterizacion_LDR}

Para poder tomar mediciones confiables y repetibles utilizando un LDR, resulta necesario un proceso de calibración, ya que no todos se comportan de la misma forma. Además, de la \cref{fig:LDR_respuesta_espectral} se puede concluir que cada LDR se exhibirá respuestas distintas según la longitud de onda de la luz incidente.

Por estos motivos, en el desarrollo de este trabajo se buscó poder caracterizar el LDR del dispositivo, calculando los parámetros $K_a$ y $\gamma$ de la \cref{eq:respuesta_LDR_R} de manera empírica.

Otro detalle a mencionar es que en el presente trabajo se decidió trabajar en términos de la conductancia $G$ del LDR, en lugar de su resistencia $R$. Esto se debe principalmente a que de esta manera, la conductancia aumenta al aumentar la cantidad de luz que incide sobre el LDR. Por lo tanto, las \cref{eq:respuesta_LDR_R,eq:circ_acond_R} se pueden expresar en términos de la conductancia como:

\begin{align}
    G   & = K_a E^{\gamma} \label{eq:respuesta_LDR_G}             \\
    V_o & = V_{+} + (V_{+} - V_{s}) R_f G \label{eq:circ_acond_G}
\end{align}

De la \cref{eq:respuesta_LDR_G} se puede despejar fácilmente una ecuación para la conductancia del LDR en función de la tensión de salida del circuito de acondicionamiento:

\begin{equation} \label{eq:conductancia_Vo}
    G = \frac{V_+ - V_o}{R_f * (V_s-V_+)}
\end{equation}
% 
, donde $V_+$ es la tensión de referencia del ADC (\qty{3.3}{\V}), $V_s$ es la tensión de alimentación del circuito (\qty{5}{\V}), y $R_f$ es la resistencia de realimentación.

El procedimiento de caracterización consiste en colocar el dispositivo sobre una superficie de calibración y configurar los LED para iluminar la superficie a distintas intensidades, tomando muestras de la tensión en la salida del circuito de acondicionamiento para cada una.

Una vez que se recolectan suficientes muestras, se aplica la técnica de mínimos cuadrados para encontrar los parámetros de \cref{eq:respuesta_LDR_G} que mejor se aproximen a los resultados obtenidos.

La superficie de calibración se eligió de manera arbitraria, priorizando superficies de color blanco y opacas, tal que se minimice la reflexión especular en favor de la reflexión difusa.

Como se mencionó previamente, y en base a lo observado en la \cref{fig:LDR_respuesta_espectral}, el LDR no responde de la misma manera a todas las longitudes de onda. Por lo tanto, este barrido de intensidades de los LED se realizó una vez para cada color utilizado por el sensor: rojo, verde y azul.

Además, debido a que no se cuentan con los elementos necesarios para medir la cantidad de luz que incide sobre la superficie sensible del LDR, es decir, la iluminancia $E$, para este proceso de caracterización se aproximó la iluminancia $E$ como la intensidad $c$ configurada para los LEDs del dispositivo.

La intensidad $c$ de cada LED del dispositivo se puede configurar mediante un código RGB de \qty{24}{bits}, utilizando \qty{8}{bits} para cada canal. Esto significa que cada LED se puede configurar para estar apagado, o en uno de 255 niveles de intensidad.

Reemplazando la aproximación $E \approx c$ en la \cref{eq:respuesta_LDR_G}, se obtiene:

\begin{equation} \label{eq:respuesta_LDR_aprox}
    G = K_a c^{\gamma}
\end{equation}

Para la secuencia de barrido, se eligieron valores de intensidad desde \numrange{0}{255} con espaciado logarítmico. Se realizaron pruebas utilizando 30 y 40 valores, y se obtuvieron resultados similares. Para cada paso del barrido se registró la intensidad configurada para los LED, la tensión muestreada por el ADC \qty{400}{\ms} luego de ser configurado el valor de intensidad, y el valor de la resistencia $R_f$.

Además, se definió una región de funcionamiento donde el dispositivo no se considera saturado. Los límites de esta región se eligieron en base a un análisis de la tensión muestreada en el ADC de \qty{12}{bits} del RP2040. Se encontró que para muestras del ADC con códigos por debajo de 850, no se registraban cambios al variar la intensidad de los LED. Lo mismo ocurrió para muestras con códigos por encima de 3800. Por lo tanto, cuando una muestra se encuentra fuera de este rango, se ajusta la resistencia $R_f$ para cambiar la ganancia del circuito, aumentando o reduciendo la tensión de salida según sea necesario, y se repite la medición.

El barrido siempre comienza utilizando el valor de resistencia más grande, $R_f=\qty{100}{\kohm}$. Esto se debe a que para intensidades de luz bajas, la conductancia del LDR es muy pequeña, por lo tanto, según la \cref{eq:respuesta_LDR_G} se necesita una resistencia $R_f$ grande para obtener un valor de tensión que se encuentre dentro del rango de funcionamiento del sensor.

\begin{figure}[htbp]
    \centering
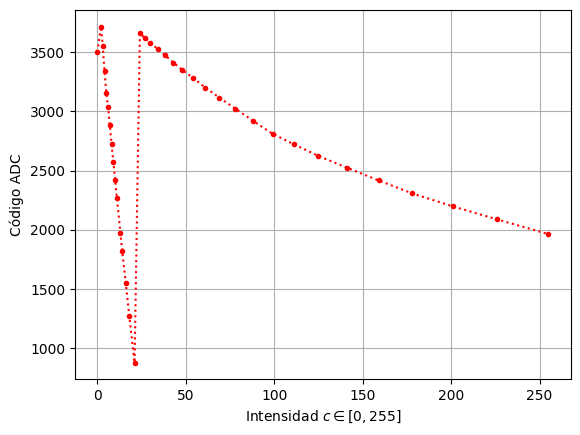
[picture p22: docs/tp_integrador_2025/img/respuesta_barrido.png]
    
    \caption{Muestras recolectadas en un barrido de 40 valores de intensidad para el canal rojo.}
    \label{fig:ADC_intensidad}
\end{figure}

En la \cref{fig:ADC_intensidad} se observa las muestras obtenidas para un barrido del canal rojo. Las discontinuidades corresponden a los cambios de la resistencia $R_f$. Se observa además que las muestras se encuentran siempre dentro de la región de funcionamiento definida anteriormente (850 a 3800 cuentas del ADC).

\begin{figure}[htbp]
    \centering
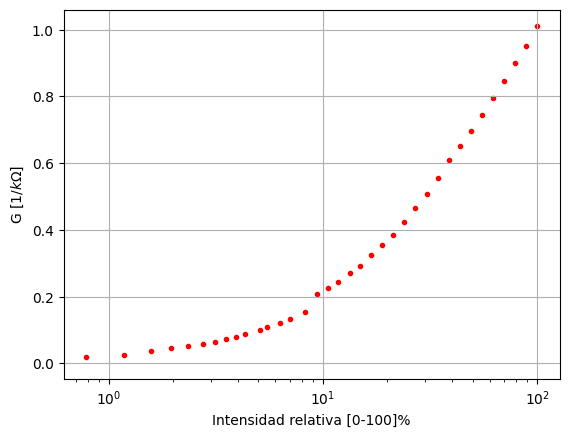
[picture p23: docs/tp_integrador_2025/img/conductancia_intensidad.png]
    
    \caption{Conductancia calculada a partir del barrido de intensidad para el canal rojo.}
    \label{fig:conductancia_intensidad}
\end{figure}

En la \cref{fig:conductancia_intensidad} se muestra el resultado de aplicar la \cref{eq:conductancia_Vo} a las muestras de la \cref{fig:ADC_intensidad}. Se utiliza una escala logarítmica para la intensidad, mostrada en el eje $x$, ya que la respuesta del LDR no es lineal, tal como lo demuestra la \cref{eq:respuesta_LDR_aprox}.

Una vez recolectadas las muestras y calculada la conductancia del LDR para cada una, se procedió aplicando la técnica de mínimos cuadrados para obtener una aproximación de la respuesta del dispositivo. La $i$-ésima muestra recolectada se expresa como:
\begin{equation*}
    G_i = K_a c_i^\gamma
\end{equation*}

Dado que se quieren encontrar los valores de $K_a$ y $\gamma$, se aplica la función logaritmo de ambos lados y se obtiene:
\begin{equation}
    \ln G_i = \ln K_a + \gamma \ln c
\end{equation}

Considerando $N$ muestras distintas, se arma un sistema de ecuaciones y se expresa en forma de matrices:

\begin{equation}
    \begin{bmatrix}
        \ln G_1    \\
        \ln G_2    \\
        \vdots \\
        \ln G_N
    \end{bmatrix}
    =
    \begin{bmatrix}
        1      & \ln c_1 \\
        1      & \ln c_2 \\
        \vdots & \vdots  \\
        1      & \ln c_N
    \end{bmatrix}
    \begin{bmatrix}
        \ln K_a \\
        \gamma
    \end{bmatrix}
\end{equation}

El valor de la matriz de las variables desconocidas se puede obtener a partir de la \cref{eq:LSQ_formula}, donde $Y$ es la matriz de las conductancias, $A$ es la matriz de los coeficientes ($1$ y $\ln c_i$), y $x$ la matriz de las variables que se quieren calcular.

\begin{equation} \label{eq:LSQ_formula}
    x = {(A^T A)}^{-1} A^T Y
\end{equation}

La aplicación de escritorio que se utilizó para interactuar con el dispositivo cuenta con funcionalidad para exportar las muestras recolectadas en formato JSON, lo cual se detalla a fondo en la \cref{sec:aplicacion_CLI}. Por lo tanto, se utilizaron las librerías de Python \textit{pandas} y \textit{numpy} para analizar los datos recolectados. 

En la \cref{fig:conductancia_intensidad_LSQ} se muestra la curva de la \cref{eq:respuesta_LDR_aprox} obtenida con los parámetros $K_a$ y $\gamma$ calculados en base a los resultados obtenidos para el color rojo. Se observa que la aproximación obtenida es muy buena para valores de intensidad bajos, pero se vuelve menos precisa para valores mas altos.

\begin{figure}[htbp]
    \centering
    
    \caption{Comparación de la conductancia calculada del barrido de intensidad para el canal rojo, y la aproximación encontrada para la \cref{eq:respuesta_LDR_aprox}.}
    \label{fig:conductancia_intensidad_LSQ}
\end{figure}

% - sensibilidad a $\lambda$
% - barrido por canal (variando intensidad)
% - no se conoce la iluminancia real -> se aproxima con intensidad de LEDs
% - se intenta rearmar la curva de respuesta del LDR para encontrar Ka y gamma

\subsection{Proceso de Medición}

% requiere los parametros del LDR
% se enciende cada canal a la max intensidad
% se mide la respuesta del LDR por separado
% se calcula la intensidad reflejada en base a los parametros del LDR
% se arma el codigo rgb

Una vez que se calibró el dispositivo y se encontraron los valores de $K_a$ y $\gamma$ para cada color, ya es posible realizar mediciones. El proceso de medición comienza colocando el dispositivo sobre la superficie que se desea medir. Luego, el dispositivo enciende sus LED a la máxima intensidad utilizando los colores rojo, verde y azul por separado. Se toman muestras de la tensión a la salida del circuito de acondicionamiento para cada color, y se calcula la conductancia $G$ del LDR que se obtuvo para cada uno.

Luego, se utilizan los parámetros obtenidos durante la calibración para determinar el color de la superficie. Debido a que la intensidad $c$ de la \cref{eq:respuesta_LDR_aprox} se mide en el rango de \numrange{0}{255}, los resultados para cada color se pueden combinar y representar directamente utilizando el código de colores RGB.

Además, al igual que durante el proceso de calibración, se evita tomar resultados saturados asegurando que el dispositivo trabaje dentro de la región de funcionamiento previamente definida. En caso de que una muestra arroje un resultado fuera de esta zona, se ajusta el valor de la resistencia $R_f$ (si es posible), y se repite la medición.

\subsection{Implementación en Microcontrolador}
% - stack USB
% - freeRTOS
% - main()
%     - inicializar perifericos: ADC, LEDs, cd4066
%     - crear primitivas de sync
%     - inicializar tusb
% - tareas
%     - usb_task: 
%         - ejecuta el stack usb (tud_task)
%         - procesar y enviar mensajes de respuesta (dev->host)
%         - los comandos se reciben mediante callback y se pasan a worker_task por queue
%     - worker_task:
%         - procesa los comandos y prepara las respuestas
%         - funciona de manera sincrona, puede procesar un solo comando a la vez
%         - bloquea la ejecución cuando ejecuta tareas asincronas como el muestreo del ADC.
%         - una vez terminado arma un mensaje de respuesta para comunicar el resultado de la operación.
%     - led_task:
%         - controla el LED del microcontrolador
%             - USB conectado ? titila : fijo
% - driver LEDs WS2812
% - ADC+DMA

El microcontrolador RP2040 es el encargado de controlar los periféricos y coordinar todas las operaciones del dispositivo, y actúa como dispositivo USB que permite al dispositivo conectarse a una PC y comunicarse mediante un protocolo de comunicación por puerto serie simple.

La implementación del firmware en el microcontrolador se realizó en el lenguaje de programación C, utilizando la capa de abstracción de hardware \textit{Pico-SDK}~\cite{pico_sdk_doc} provista por el fabricante.

Para funcionar como dispositivo USB, se utilizó la librería \textit{TinyUSB}~\cite{tinyusb_doc}, la cuál ofrece una implementación del stack USB para dispositivos embebidos. 

Además, se utilizó el sistema operativo de tiempo real \textit{FreeRTOS}. La principal motivación es que este brinda herramientas para logar la sincronización de las distintas tareas que lleva a cabo el dispositivo, lo cuál es útil debido a la naturaleza asíncrona de la comunicación serial.

El microcontrolador a su vez es el encargado de manejar todos los periféricos del dispositivo, los cuales incluyen:
\begin{itemize}
    \item Conversor analógico-digital (ADC)
    \item LED WS2812
    \item Switch bilateral cuádruple CD4066
    \item LED indicador de estado
\end{itemize}
%
Se implementó un driver para cada uno de estos, permitiendo a la aplicación principal utilizarlos sin conocer sus detalles de implementación. 

\subsubsection{Protocolo de Comunicación}

Se implementó un protocolo de comunicación simple para la comunicación dispositivo-PC. El mismo se basa en una versión modificada de la librería  \href{https://github.com/esadigov/ascii-communication-protocol}{esadigov/ascii-communication-protocol}, disponible en GitHub. 

El protocolo implementado envía mensajes de texto plano, denominados comandos, desde la PC al dispositivo. Estos comandos son interpretados por el dispositivo para ejecutar alguna de sus funciones. Todos los comandos siguen el siguiente formato:
%
\begin{verbatim}
    &<nombre-comando>,[argumento1],[argumento2]*
\end{verbatim}

Cada comando tiene un nombre único, y opcionalmente puede enviar hasta dos argumentos adicionales. Por ejemplo, el comando para encender ambos LED del dispositivo con color verde se envía como:
%
\begin{verbatim}
    &SET_LED,0,0x00ff00*
\end{verbatim}

Una vez que el dispositivo termina de ejecutar la operación, el mismo arma un mensaje de respuesta para enviar de vuelta a la PC. Debido a que la respuesta muchas veces consiste de valores numéricos, como pueden ser una serie de muestras del ADC, esta respuesta se puede enviar utilizando una combinación de texto plano y datos binarios, utilizando el siguiente formato:
%
\begin{verbatim}
    &<tipo-respuesta>,<cantidad-bytes>;<bytes-mensaje>
\end{verbatim}

A diferencia del formato de un comando, el mensaje de respuesta no puede utilizar un terminador ASCII como \verb|*|, ya que el mensaje de respuesta podría incluir este mismo carácter. Además, si la respuesta contiene datos binarios, existe la posibilidad de que alguno de los bytes de la respuesta tenga el mismo valor ASCII que el carácter terminador. Por este motivo, el formato de respuesta especifica primero el numero de bytes del mensaje enviado, permitiendo que la aplicación de PC pueda leer el mensaje completo.

\subsubsection{Conversor Analógico-Digital}

Además de un ADC de \qty{12}{bits}, el RP2040 cuenta además con un controlador DMA que puede configurarse para trabajar junto al ADC. Esto permite al microcontrolador tomar una gran cantidad de muestras y guardarlas en memoria sin requerir de la intervención del procesador. 

Pese a que el dispositivo no supone una carga importante para el procesador del RP2040, y que no se toma un número significativo de muestras del ADC, se decidió utilizarlo de todas formas ya que es muy fácil de configurar y reduce y simplifica el código al no tener que escribir lógica para tomar y guardar muestras individuales.

El ADC se configuró con una frecuencia de muestreo de \qty{500}{Hz}, ya que el transductor LDR se caracteriza por tener una respuesta lenta. Sin embargo, se probaron distintos valores de frecuencia y se obtuvieron resultados similares. 

Al iniciar el dispositivo, se inicializa el ADC por código y se conecta a un canal DMA libre. El DMA se configura para leer desde el registro de muestras del ADC (\verb|adc_hw->fifo|)~\cite{RP2040_datasheet}, y escribir cada muestra en un arreglo en memoria. El tamaño del arreglo utilizado fue de 40 muestras.

Debido a que la frecuencia de DMA es mucho mayor que la frecuencia de muestreo del ADC, se conecta la señal de solicitud de datos (\verb|DREQ|) del ADC al canal DMA, de manera que el DMA solo realice una transferencia cada vez que el ADC toma una nueva muestra.

Finalmente, dado que la toma de muestras se realiza de manera asíncrona mediante DMA, es necesario sincronizar el final de la transferencia para que el programa pueda continuar. Por lo tanto, se configuró una interrupción para indicar el final de la transferencia por parte del DMA.

\subsubsection{División de Tareas}

Las tareas que realiza el microcontrolador se pueden separar en dos partes clave: la comunicación USB por medio de la cual se reciben los comandos que debe ejecutar, y la ejecución de dichos comandos. Debido a que cada una tiene lógica especifica, ya sea la decodificación de comandos y codificación de respuestas, la lógica propia del stack USB, o la lógica individual que requiere la ejecución de cada comando, se definieron dos tareas: \verb|usb_task()| y \verb|worker_task()|.

La estructura de la tarea \verb|usb_task()| se muestra en el Listado~\ref{lst:usb_task}. La misma debe cumplir tres tareas especificas:
\begin{enumerate}
    \item Ejecutar el stack USB mediante la función \verb|tud_task()| de TinyUSB.
    \item Recibir mensajes de respuesta a enviar por USB hacia el host.
    \item Enviar las respuestas al host.
\end{enumerate}

Un aspecto crítico de la librería TinyUSB es que la misma no se ejecuta automáticamente como un proceso adicional de la aplicación, sino que se debe asegurar su ejecución llamando a la función \verb|tud_task()| de manera regular. De lo contrario, no se procesarían los eventos del stack USB y el sensor dejaría de ser detectado como dispositivo USB.

\lstset{basicstyle=\small}
\begin{lstlisting}[language=c, caption={Estructura de la tarea encargada de la comunicación por USB.}, label={lst:usb_task}]
void usb_task(void *arg) {
    while (1) {
        tud_task();

        if (!msg_in_buffer) {
            size_t n = xMessageBufferReceive(tx_msg_buffer, ...);
            ...
        }

        if (msg_in_buffer) {
            ...
            tud_cdc_write(...);
            ...
        }
    }
}
\end{lstlisting}

A su vez, la tarea \verb|usb_task()| también es la encargada de recibir los mensajes provenientes desde el host, e interpretarlos como comandos. Esto se logra utilizando la función callback provista por TinyUSB: \verb|tud_cdc_rx_cb()|, cuya lógica de decodificación se muestra en el Listado~\ref{lst:usb_callback}. Cuando se reciben datos, esta función es ejecutada por el stack USB cuando corre \verb|tud_task()|. Cada mensaje recibido se interpreta como comando y envía por medio de una cola a la tarea \verb|worker_task()|.

\begin{lstlisting}[language=c,caption={Callback para recibir e interpretar comandos recibidos desde el host.}, label={lst:usb_callback}]
void tud_cdc_rx_cb(uint8_t itf) {
    uint8_t rx_buf[ACP_CMD_MAX_SIZE + 1];

    uint32_t n = tud_cdc_read(rx_buf, ACP_CMD_MAX_SIZE);
    if (n == 0)
        return;

    acp_command_t cmd;
    bool result = acp_parse_command(&cmd, rx_buf, n);
    if (result) {
        xQueueSend(cmd_queue, &cmd, 0);
    } else {
        // error...
    }
}
\end{lstlisting}

Por otro lado, la segunda tarea \verb|worker_task()| es responsable de recibir y ejecutar los comandos, y devolver las respuestas a la tarea \verb|usb_task()| para enviarlas al host. Su estructura general se muestra en el Listado~\ref{lst:worker_task}.

Esto se logra recibiendo los comandos a través de una cola de FreeRTOS. La tarea bloquea hasta recibir un nuevo comando, y luego ejecuta su correspondiente acción según el tipo de comando recibido. Una vez terminado, cada comando arma su mensaje de respuesta, y lo envía a la \verb|usb_task()| mediante un buffer de mensajes. 

La estructura general de la tarea \verb|usb_task()| se muestra a continuación:

\begin{lstlisting}[language=c, caption={Estructura de la tarea procesadora.}, label={lst:worker_task}]
void worker_task(void *arg) {
    acp_command_t cmd;
    while (1) {
        xQueueReceive(cmd_queue, &cmd, ...);
        switch (cmd.type) {
        case CMD_XYZ:
            ...
            xMessageBufferSend(tx_msg_buffer, ...);
            break;
        }
        ...
    }
}
\end{lstlisting}

\subsection{Aplicación de Linea de Comandos} \label{sec:aplicacion_CLI}
Para facilitar la interacción con el dispositivo y el procesamiento de las mediciones se desarrolló una aplicación de línea de comandos (CLI) en Python. La aplicación se comunica con el dispositivo a través de USB utilizando la librería \textit{pyserial}, que encapsula el acceso al puerto serie. 
La misma se organiza en tres módulos principales:
\begin{itemize}
    \item \verb|serialpal.py|
    \item \verb|cli.py|
    \item \verb|json_exporter.py|
\end{itemize}

Adicionalmente, se desarrollaron scripts auxiliares para el procesamiento y visualización de datos.

\subsubsection{Módulo \texttt{serialpal.py}}
Este módulo actúa como capa de adaptación entre la interfaz de usuario y el dispositivo físico,
encapsulando toda la lógica de comunicación serial. Para acceder al puerto serie del sistema operativo, se utilizó la librería \textit{pyserial}, que provee una interfaz uniforme independientemente del sistema operativo del host.

La clase principal \verb|SerialPal| provee métodos para listar los puertos disponibles del sistema,
conectarse a uno de ellos, y enviar y recibir mensajes siguiendo el protocolo de comunicación descrito en la sección anterior.

El método \verb|send()| construye y envía un comando con el formato \\ \verb|&<cmd>,<arg1>,<arg2>*|, mientras que \verb|receive()| lee la respuesta del dispositivo
interpretando primero el encabezado para determinar el tipo y la longitud del payload, y luego
leyendo dicho payload de manera completa.
Las respuestas recibidas se encapsulan en objetos de la clase \verb|Response|, que almacena el
tipo de respuesta (\verb|TEXT| o \verb|DATA|), el payload en formato binario, y su longitud en
bytes. 

El método \verb|decode()| convierte el payload al tipo de dato correspondiente: en el caso
de respuestas de texto, se decodifica como una cadena ASCII; en el caso de datos binarios, se
desempaquetan como una tupla de enteros sin signo de 8 o 16 bits, según se indique.

\subsubsection{Módulo \texttt{cli.py}}

Este módulo implementa la interfaz interactiva con el usuario, extendiendo la clase \verb|cmd.Cmd|
de la biblioteca estándar de Python. Esto permite ofrecer un intérprete de comandos con
funcionalidades como autocompletado y un sistema de ayuda integrado.

Cada comando disponible en la interfaz se implementa como un método con el prefijo \verb|do_|.
Los comandos más relevantes son los siguientes:

\begin{itemize}
    \item \verb|ports|: lista los puertos serie disponibles en el sistema.
    \item \verb|conn <puerto>|: establece la conexión con el dispositivo en el puerto indicado.
    \item \verb|ping|: envía un comando de prueba al dispositivo para verificar la comunicación.
    \item \verb|adc|: solicita al dispositivo una serie de muestras del ADC y calcula su media y
          desviación estándar.
    \item \verb|set_led <índice> <rgb>|: configura el color de un LED del dispositivo mediante un
          código RGB de \qty{24}{bits}.
    \item \verb|sweep <canal>|: ejecuta el procedimiento de calibración para el canal de color indicado (R, G o B), descrito en la \cref{sec:caracterizacion_LDR}.
    \item \verb|measure|: realiza una medición de color completa utilizando los parámetros del
          modelo LDR previamente calculados, y muestra el resultado como código RGB.
\end{itemize}

El comando \verb|sweep| recorre un conjunto de intensidades con espaciado logarítmico en el rango
\numrange{0}{255}, configurando el LED correspondiente en cada paso y registrando la respuesta del
ADC. Durante el barrido se controla automáticamente la saturación del circuito de acondicionamiento,
ajustando el valor de $R_f$ cuando una muestra se encuentra fuera de la región de funcionamiento
definida. Al finalizar, las mediciones se exportan a un archivo JSON mediante el módulo
\verb|json_exporter.py|.

El comando \verb|measure| carga los parámetros $K_a$ y $\gamma$ del archivo \verb|LDR_params|
\verb|.json| generado durante la calibración, enciende cada canal del LED a su máxima intensidad de manera secuencial, y determina el valor de color para cada canal a partir de la \cref{eq:respuesta_LDR_aprox}. Al finalizar, se muestra el resultado como un código RGB de \qty{24}{bits}, junto con una representación visual del color obtenido en la terminal.

\subsubsection{Scripts Auxiliares}

El script \verb|fit_LDR_curves.py| implementa el procedimiento de mínimos cuadrados descripto en
la \cref{sec:caracterizacion_LDR}, utilizando las librerías \textit{pandas} y \textit{numpy}.
Para cada canal de color, lee el archivo JSON correspondiente, calcula la conductancia $G$ a partir
de las muestras del ADC mediante la \cref{eq:conductancia_Vo}, y aplica la \cref{eq:LSQ_formula}
para obtener los parámetros $K_a$ y $\gamma$ de la \cref{eq:respuesta_LDR_aprox}. Los resultados
se almacenan en el archivo \verb|LDR_params.json|, que luego es utilizado por la aplicación CLI
para realizar las mediciones.

Por su parte, el script \verb|plot_LDR_response.py| permite visualizar la respuesta teórica del
circuito de acondicionamiento para los distintos valores de $R_f$ disponibles, graficando la
tensión de salida $V_o$ en función de la resistencia del LDR. Esto resulta útil para verificar
el rango de funcionamiento del circuito antes de realizar mediciones.

% - cli.py
%     - frontend interactivo
% - serialpal.py
%     - capa de adaptación CLI/USB
%     - provee una interfaz para enviar y recibir mensajes desde/al dispositivo mediante USB/CDC
%     - codifica entrada de usuarios -> comandos
%     - decodificación de respuestas
% - pyserial
%     - libreria de Python que encapsula el acceso al puerto serie.

% - scripts/fit_LDR_curves.py
%     - calcula los parámetros K_a y gamma a partir de los resultados de la calibración.
%     - como se menciono en la sec. "Caracterización del LDR"
%     - da como resultado un archivo con los parametros resultantes para cada canal. Luego estos son utilizados para realizar las mediciones
%     - 

\section{Resultados}

Se comprobó el funcionamiento del dispositivo y del proceso de calibración. Durante las pruebas, se calibró el dispositivo sobre papel de impresora, cuya superficie blanca y opaca asegura una reflexión mayormente difusa, lo cual es ideal para el funcionamiento correcto del dispositivo. Tal como se describió en los apartados anteriores, se ejecutó el comando \verb|measure| para cada canal, y luego el script \verb|fit_LDR_curves.py| para obtener los parámetros del LDR. Los resultados obtenidos se muestran en el Listado~\ref{lst:ldr_params}.

\begin{lstlisting}[caption={Parametros obtenidos de la caracterización del LDR.}, label={lst:ldr_params}]
{
    "R": {
        "Ka": 0.011508412425650682,
        "gamma": 0.8527065806062964
    },
    "G": {
        "Ka": 0.0032507832523976554,
        "gamma": 0.8597395131749697
    },
    "B": {
        "Ka": 0.0030240133142661603,
        "gamma": 0.8283233614433873
    }
}
\end{lstlisting}

Como se puede observar, el parámetro $\gamma$ es prácticamente idéntico para los tres colores. Además, se concluye que los resultados obtenidos son coherentes con la \cref{fig:LDR_respuesta_espectral}, ya que el LDR presenta distintas sensibilidades para cada color, ya que cada canal presenta distintos valores de $K_a$.

Por último, se tomaron medidas sobre superficies de distintos colores y se compararon los resultados con los de una aplicación móvil para medir colores. La aplicación elegida fue \textit{Color Picker - Pixel Color}, disponible en el App Store de iOS. El dispositivo utilizado fue un iPhone 16.

Se utilizó la hoja de calibración mostrada en la \cref{fig:hoja_calibracion}, la cuál cuenta con parches de color verde, amarillo, celeste y rosado. Se utilizó la aplicación móvil para obtener un color de referencia, y se comparó con los resultados obtenidos con el dispositivo. Las \crefrange{fig:resultado_verde}{fig:resultado_rosa} muestran una comparación de los resultados obtenidos para cada parche de color.

En base a los resultados obtenidos se concluye que se lograron los objetivos propuestos para este trabajo. Se logró diseñar e implementar un dispositivo de bajo costo que permite estimar el color de una superficie, cuyos resultados son comparables con los obtenidos utilizando una cámara de buena calidad de un dispositivo móvil. Además, gracias al procedimiento de calibración, se logró obtener una curva de respuesta aproximada del LDR, y en teoría permitiría obtener resultados similares con otros LDR.

\begin{figure}
    \centering
    
    \caption{Hoja de calibración utilizada.}
    \label{fig:hoja_calibracion}
\end{figure}

\begin{figure}
    \centering
    
    \caption{Comparación de resultados para la superficie verde.}
    \label{fig:resultado_verde}
\end{figure}

\begin{figure}
    \centering
    
    \caption{Comparación de resultados para la superficie amarilla.}
    \label{fig:resultado_amarillo}
\end{figure}

\begin{figure}
    \centering
    
    \caption{Comparación de resultados para la superficie celeste.}
    \label{fig:resultado_celeste}
\end{figure}

\begin{figure}
    \centering
    
    \caption{Comparación de resultados para la superficie rosa.}
    \label{fig:resultado_rosa}
\end{figure}

\printbibliography[title={Referencias}]
\end{document}

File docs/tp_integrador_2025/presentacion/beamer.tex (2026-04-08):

\documentclass[10pt]{beamer}

% --- Configuración de Tema ---
\usetheme{Madrid}
\usecolortheme{default}
\setbeamertemplate{navigqation symbols}{} % Quitar iconos de navegación

% --- Paquetes ---
\usepackage[spanish]{babel}
\usepackage[utf8]{inputenc}
\usepackage{graphicx}
	\graphicspath{{../img}}
\usepackage{amsmath}
\usepackage{siunitx}
\usepackage{listings}
\usepackage{booktabs}
\usepackage{listings}

% Configuración de listings para código C
\lstset{
    language=C,
    basicstyle=\ttfamily\tiny,
    keywordstyle=\color{blue},
    commentstyle=\color{green!60!black},
    stringstyle=\color{orange},
    breaklines=true,
    frame=single
}

% --- Información del Proyecto ---
\title[Sensor de Colores]{Desarrollo de un Sensor de Colores por Reflexión}
\subtitle{Técnicas Digitales III}
\author[Beck, Perez]{Federico Beck \and Mariano Perez}
\institute[UTN FRSF]{
    Departamento de Ingeniería Electrónica\\
    Facultad Regional San Francisco --- UTN
}
\date{8 de Abril, 2026}

% Logo en la esquina (opcional)
\titlegraphic{}

\begin{document}

% --- Diapositiva de Título ---
\begin{frame}
    \titlepage{}
\end{frame}

% --- Índice ---
\begin{frame}{Contenidos}
    \tableofcontents
\end{frame}

% --- Introducción ---
\section{Introducción}
\begin{frame}{Introducción y Motivación}
    \begin{columns}
        \begin{column}{0.5\textwidth}
            \begin{itemize}
                \item \textbf{Objetivo:} Dispositivo de bajo costo para determinación de color.
                \item \textbf{Principio:} Reflexión de luz roja, verde y azul sobre una superficie.
                \item \textbf{Sensor:} Resistencia dependiente de la luz (LDR).
            \end{itemize}
        \end{column}
        \begin{column}{0.5\textwidth}
            \centering
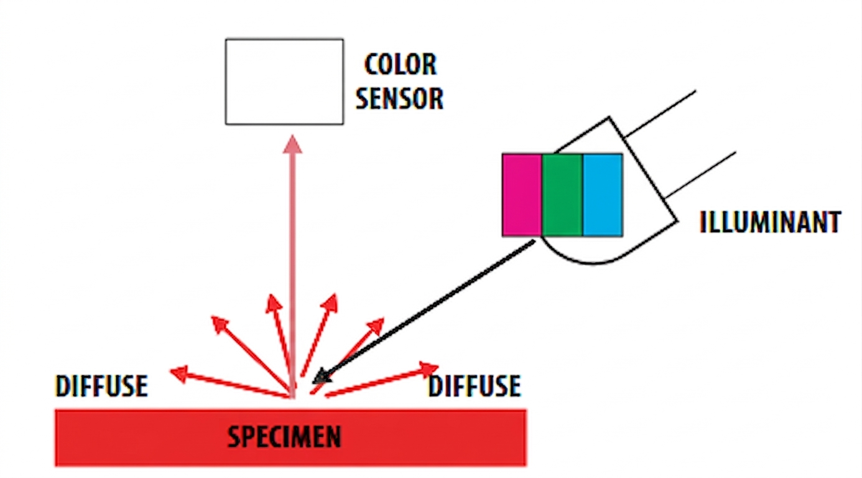
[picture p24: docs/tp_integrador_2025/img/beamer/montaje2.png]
            
            % cambiar x diagrama general
        \end{column}
    \end{columns}
\end{frame}

\begin{frame}{Opciones Comerciales}
    Sensor Adafruit TCS34725: utiliza luz blanca, filtros, y un fotodiodo.
    \vfill
    \begin{columns}
        \begin{column}{0.5\textwidth}
        \begin{figure}
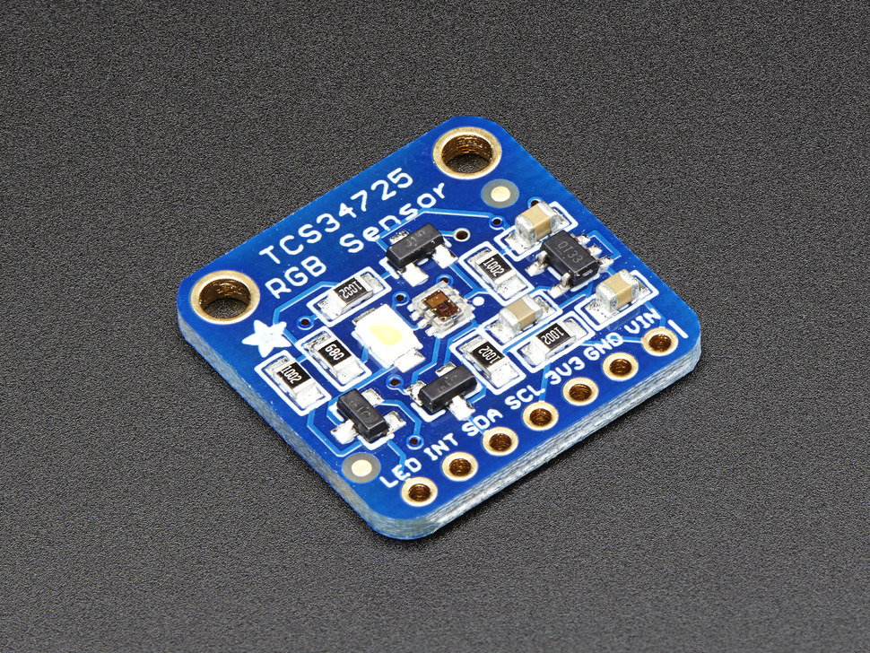
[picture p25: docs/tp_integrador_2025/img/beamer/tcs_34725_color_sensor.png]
            
            \caption{Sensor Adafruit TCS34725.}
        \end{figure}
    \end{column}
        \begin{column}{0.5\textwidth}
            \centering
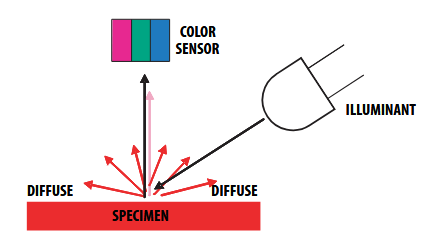
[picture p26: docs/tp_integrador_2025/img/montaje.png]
            
            % cambiar x diagrama general
        \end{column}
    \end{columns}
\end{frame}

\begin{frame}[label=arquitectura]
    \frametitle{Arquitectura del Dispositivo}
    \centering
    
\end{frame}

% --- Hardware y Diseño ---
\section{Hardware y Diseño}
\begin{frame}{Diseño Físico y Carcasa}
    \begin{itemize}
        \item Aislamiento de luz ambiente para evitar distorsión en mediciones.
        \item Compartimientos separados para LEDs, LDR y conexiones.
    \end{itemize}
    \centering
    
\end{frame}

\begin{frame}{Componentes Electrónicos: LDR}
    \begin{columns}
        \begin{column}{0.5\textwidth}
            \begin{itemize}
                \item Respuesta no lineal
                \item Distintas sensibilidades a distintas longitudes de onda.
                \item Baja trazabilidad
                \item Respuesta variable
            \end{itemize}
            La respuesta se puede aproximar como:
            \[
                R = K_a E^{-\gamma}
            \]
        \end{column}
        \begin{column}{0.5\textwidth}
            \begin{figure}
                
            \end{figure}
        \end{column}
    \end{columns}
\end{frame}

\begin{frame}{Componentes Electrónicos}
    \begin{columns}
        \begin{column}{0.6\textwidth}
            \textbf{Unidad de Control --- Raspberry Pi Pico:}
            \begin{itemize}
                \item Microcontrolador RP2040
                \item DMA para muestreo de ADC
                \item Stack USB
                \item I/O programable
            \end{itemize}
            \textbf{Iluminantes:}
            \begin{itemize}
                \item LEDs WS2812 (RGB)
                \item Múltiples LEDs conectados en cascada
            \end{itemize}
            \textbf{Circuito de Acondicionamiento:}
            \begin{itemize}
                \item Amplificador operacional LM358
                \item Switch cuádruple CD4066
                \item Resistencias de \qtylist{1;10;100}{\kohm}
            \end{itemize}
        \end{column}
        \begin{column}{0.4\textwidth}
            \centering
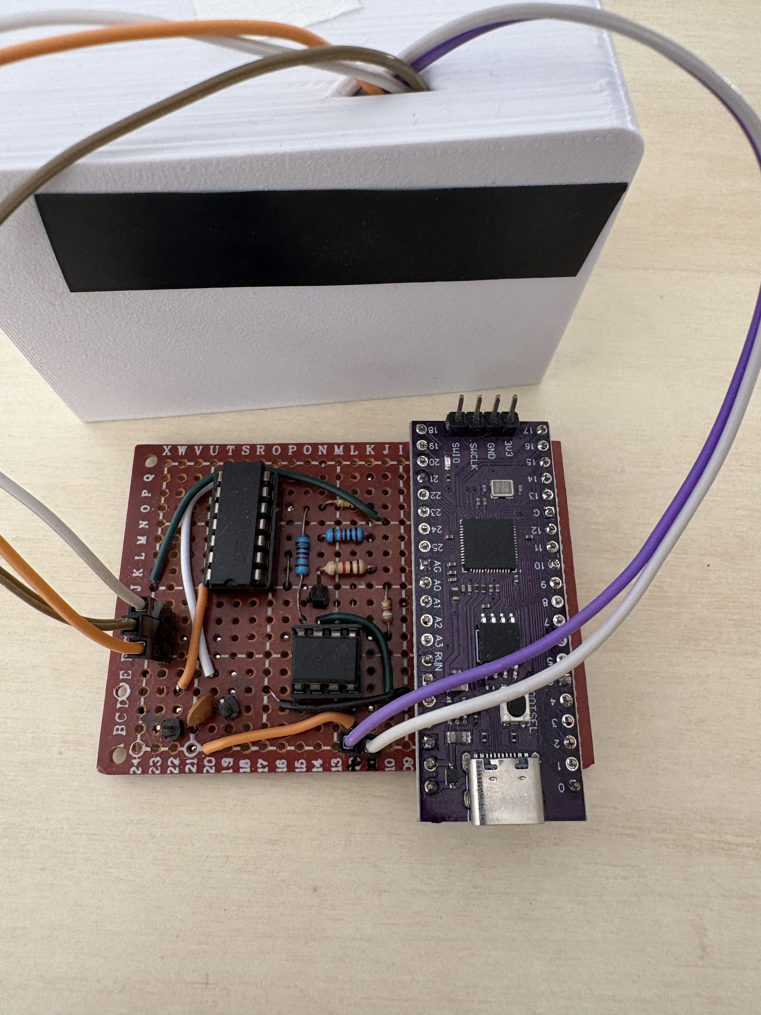
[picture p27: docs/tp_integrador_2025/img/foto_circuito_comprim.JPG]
            
        \end{column}
    \end{columns}
\end{frame}

% --- Circuito de Acondicionamiento ---
\section{Circuito de Acondicionamiento}
\begin{frame}{Acondicionamiento de Señal}
    \begin{figure}
        \centering
        
    \end{figure}
    
    \begin{align*}
        V_o &= V_{+} + (V_{+} - V_{s}) \frac{R_f}{R_{LDR}} \\
        V_o &= V_{+} + (V_{+} - V_{s}) R_f G
    \end{align*}

    Mediante el CD4066, $R_f$ puede tomar distintos valores discretos para evitar la saturación ante el amplio rango del LDR (\qtyrange{1}{1000}{\kohm}). 
\end{frame}

\begin{frame}{Respuesta del Circuito}
    \begin{equation*}
        G = \frac{V_+ - V_o}{R_f * (V_s-V_+)}
    \end{equation*}

    \begin{figure}
        
        \caption{Tensión de salida vs Resistencia del LDR para distintas $R_f$.}
    \end{figure}
\end{frame}

% --- Caracterización ---
\section{Caracterización del LDR}
\begin{frame}{Modelo Matemático del LDR}
    La respuesta del LDR no es lineal:
    \begin{equation*}
        R = K E^{-\gamma}
    \end{equation*}
    \begin{itemize}
        \item $E$: \alert{Iluminancia}
        \item $Ka, \gamma$: Parámetros desconocidos.
    \end{itemize}
    \pause
    \vfill
    Expresado en terminos de conductancia:
    \begin{equation*}
        G = K_a E^{\gamma}
    \end{equation*}
\end{frame}

\begin{frame}{Iluminancia}
    \begin{block}{Definición}
        La iluminancia es la cantidad de flujo luminoso que incide sobre una superficie por unidad de área.
        
        \begin{itemize}
            \item Define qué tan iluminada está una superficie
            \item Medida en lux ($\qty{1}{lux} = \qty{1}{\lumen\per\meter^2}$)
            \item Disminuye con el cuadrado de la distancia a la fuente
            \item Se mide con un \alert{luxómetro}
        \end{itemize}
    \end{block}
\end{frame}

\begin{frame}{Modelo Matemático Aproximado del LDR}
    \begin{columns}
        \begin{column}{0.5\textwidth}
            Es imposible determinar la \alert{iluminancia}, por lo que se utiliza una aproximación.
            
            \begin{equation*}
                E \approx c ,\quad c \in [0,255]
            \end{equation*}
            \begin{equation*}
                G = K_a c^{\gamma}
            \end{equation*}
        \end{column}
        \begin{column}{0.5\textwidth}
            \centering
            
        \end{column}
    \end{columns}
\end{frame}

\begin{frame}{Región de Funcionamiento}
    Se define una región de funcionamiento del dispositivo.

    Para muestras del ADC con códigos por debajo de \alert{850} y por encima de \alert{3800}, la respuesta del circuito no variaba al cambiar la intensidad de los LED.
    \begin{figure}
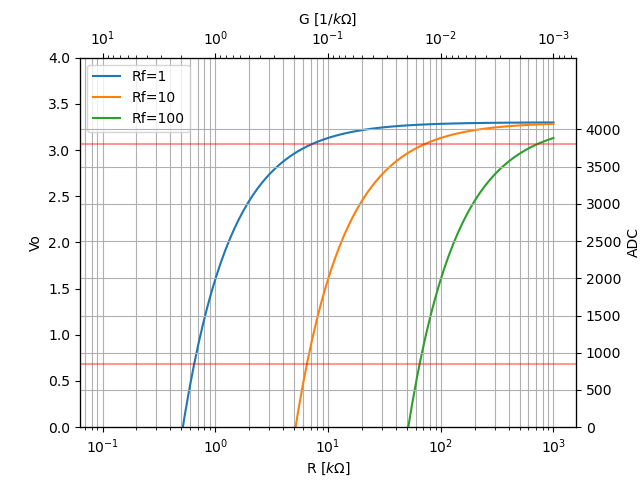
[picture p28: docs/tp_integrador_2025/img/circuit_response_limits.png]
        
    \end{figure}
\end{frame}

\begin{frame}{Proceso de Calibración}
    \begin{columns}
        \begin{column}{0.5\textwidth}
            \begin{itemize}
                \item Cada color por separado
                \item Barrido de intensidad 
                \item 40 valores de intensidad 
                \item Espaciado logarítmico
            \end{itemize}
            \vfill
            Si la medición no se encuentra dentro de la región de funcionamiento, se ajusta la resistencia de ganancia y se repite.
        \end{column}
        \begin{column}{0.5\textwidth}
            \begin{figure}
                \centering
                
            \end{figure}
        \end{column}
    \end{columns}
\end{frame}

\begin{frame}{Proceso de Calibración}
    \centering
    \includegraphics<1>[height=0.9\textheight]{beamer/resultados_barrido}
    \includegraphics<2>[width=0.7\textwidth]{conductancia_intensidad}
\end{frame}

\begin{frame}{Cálculo de los Parametros del LDR}
Una vez recolectadas las muestras para cada color, se aplica la técnica de mínimos cuadrados (LSQ) para aproximar la respuesta.

La $i$-ésima muestra recolectada se expresa como:
\begin{equation*}
    G_i = K_a c_i^\gamma
\end{equation*}

\pause
\begin{equation}    
    \ln G_i = \ln K_a + \gamma \ln c
\end{equation}

\pause
Considerando $N$ muestras distintas, se arma un sistema de ecuaciones y se expresa en forma de matrices:

\begin{equation}
    \begin{bmatrix}
        \ln G_1    \\
        \ln G_2    \\
        \vdots \\
        \ln G_N
    \end{bmatrix}
    =
    \begin{bmatrix}
        1      & \ln c_1 \\
        1      & \ln c_2 \\
        \vdots & \vdots  \\
        1      & \ln c_N
    \end{bmatrix}
    \begin{bmatrix}
        \ln K_a \\
        \gamma
    \end{bmatrix}
\end{equation}

\end{frame}

\begin{frame}{Cálculo de los Parámetros del LDR}
Considerando $N$ muestras distintas, se arma un sistema de ecuaciones y se expresa en forma de matrices:

\begin{align*}
    \begin{bmatrix}
        \ln G_1    \\
        \ln G_2    \\
        \vdots \\
        \ln G_N
    \end{bmatrix}
    &=
    \begin{bmatrix}
        1      & \ln c_1 \\
        1      & \ln c_2 \\
        \vdots & \vdots  \\
        1      & \ln c_N
    \end{bmatrix}
    \begin{bmatrix}
        \ln K_a \\
        \gamma
    \end{bmatrix}
    \\
    Y &= A x
\end{align*}

Los valores de la matriz $x$ que mejor se ajustan a las muestras obtenidas se puede calcular como:
\begin{equation} \label{eq:LSQ_formula}
    x = {(A^T A)}^{-1} A^T Y
\end{equation}

\end{frame}

\begin{frame}[fragile]{Parámetros del LDR}
\begin{lstlisting}
{
    "R": {
        "Ka": 0.011508412425650682,
        "gamma": 0.8527065806062964
    },
    "G": {
        "Ka": 0.0032507832523976554,
        "gamma": 0.8597395131749697
    },
    "B": {
        "Ka": 0.0030240133142661603,
        "gamma": 0.8283233614433873
    }
}
\end{lstlisting}
\end{frame}

\section{Proceso de Medición}
\begin{frame}{Proceso de Medición}
    Una vez determinados los parámetros del LDR, se pueden tomar mediciones.

    Para cada color R-G-B:
    \begin{enumerate}
        \item Se coloca el dispositivo sobre la superficie a medir.
        \item Iluminación a máxima intensidad.
        \item Muestreo de tensión y cálculo de $G$.
    \end{enumerate}
    
    \[
        G \approx K_a c^\gamma
    \]

    \begin{itemize}
        \item $G$ se mide
        \item $K_a ,\, \gamma$ se conocen de la calibración
    \end{itemize}
\end{frame}

\section{Resultados}
\begin{frame}{Resultados}
    \begin{columns}
        \begin{column}{0.5\textwidth}
            \begin{figure}
                \centering
                
            \end{figure}
        \end{column}
        \begin{column}{0.5\textwidth}
            \begin{figure}
                \centering
                
            \end{figure}
        \end{column}
    \end{columns}
\end{frame}

\begin{frame}{Resultados}
    \begin{columns}
        \begin{column}{0.5\textwidth}
            \begin{figure}
                \centering
                
            \end{figure}
        \end{column}
        \begin{column}{0.5\textwidth}
            \begin{figure}
                \centering
                
            \end{figure}
        \end{column}
    \end{columns}
\end{frame}

% --- Firmware ---
\section{Firmware}

\begin{frame}
    \frametitle{Implementación en Firmware}

    \begin{figure}
        \centering
        
    \end{figure}    

\end{frame}

\begin{frame}{Arquitectura del Firmware}
    \begin{itemize}
        \item Implementación en C
        \item Abstracción de hardware: \textbf{Pico-SDK}
        \item Implementación del stack USB: \textbf{TinyUSB}
        \item SO de tiempo real: \textbf{FreeRTOS}
    \end{itemize}
\end{frame}

\begin{frame}{Arquitectura del Firmware}
    \begin{itemize}
        \item \texttt{usb\_task()} 
            \begin{itemize}
                \item Ejecuta del stack USB 
                \item Recibe/envía de mensajes desde/hacía el host
            \end{itemize}
        \item \texttt{worker\_task()} 
            \begin{itemize}
                \item Ejecuta de comandos
                \item Interactúa con periféricos a través de \textbf{drivers}
                \item Arma de mensajes de respuesta
            \end{itemize} 
        \item Librería \texttt{ascii-communication-protocol} (ACP) 
            \begin{itemize}
                \item Interpreta mensajes recibidos como comandos
                \item Codifica mensajes a enviar en el formato de respuesta
            \end{itemize}          
    \end{itemize}
\end{frame}

\begin{frame}
    \frametitle{Arquitectura del Firmware}

    \begin{columns}
        \begin{column}{0.3\textwidth}
            \begin{itemize}
                \item \texttt{usb\_task()} 
                \item \texttt{worker\_task()} 
                \item Librería ACP 
            \end{itemize}
        \end{column}
        \begin{column}{0.7\textwidth}
            \begin{figure}
                \centering
                        
            \end{figure}
        \end{column}
    \end{columns}

\end{frame}

\begin{frame}{Aplicación CLI}
    \begin{figure}
        \centering
        
    \end{figure}
\end{frame}

\begin{frame}{Compración con la Versión Inicial}
    \begin{figure}
        \centering
        
    \end{figure}
\end{frame}

\begin{frame}{Compración con la Versión Inicial}
    \begin{columns}
        \begin{column}{0.5\textwidth}
            \begin{figure}
                \centering
                
                \caption{Versión 2024}
            \end{figure}            
        \end{column}
        \begin{column}{0.5\textwidth}
            \begin{figure}
                \centering
                
                \caption{Versión 2025}
            \end{figure}
        \end{column}
    \end{columns}
\end{frame}

% --- Conclusión ---
\section{Comparación y Conclusiones}
\begin{frame}
    \begin{block}{Conclusión}
        Se logró un dispositivo económico capaz de distinguir y medir de colores de forma aceptable mediante la caracterización empírica del sensor LDR.
    \end{block}
    
    \begin{figure}
        \centering
                
    \end{figure}
\end{frame}

\end{document}

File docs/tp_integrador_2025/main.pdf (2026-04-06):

Universidad Tecnológica Nacional 8 Abril Año 2026

Técnicas Digitales III, Medidas Electrónicas II Ing. Daniele, Fernando — Ing. Bossio, Jorge

# Desarrollo de un Sensor de Colores por Reflexión

Beck, Federico
Departamento de Ingeniería Electrónica,
Facultad Regional San Francisco, Córdoba, Argentina. federicobeck91@gmail.com

Perez, Mariano
Departamento de Ingeniería Electrónica,
Facultad Regional San Francisco, Córdoba, Argentina. perezmariano7401@gmail.com

1

Universidad Tecnológica Nacional 8 Abril Año 2026

Técnicas Digitales III, Medidas Electrónicas II Ing. Daniele, Fernando — Ing. Bossio, Jorge

## Índice

1. Resumen | 3
2. Introducción | 3
3. Desarrollo | 5
4. Resultados | 21

2

Universidad Tecnológica Nacional 8 Abril Año 2026

Técnicas Digitales III, Medidas Electrónicas II Ing. Daniele, Fernando — Ing. Bossio, Jorge

## 1. Resumen

Se diseñó e implementó un sensor de colores por reflexión de bajo costo, capaz de estimar el color de una superficie y expresarlo como un código de color de 24 bits en formato RGB. El dispositivo emplea una resistencia dependiente de la luz como sensor, iluminando la superficie objetivo de forma secuencial con diodos emisores de luz de cada color, y midiendo la intensidad de la luz reflejada en cada caso.
Dado que los LDR suelen tener baja trazabilidad y amplia variación en su respuesta espectral, se desarrolló un procedimiento de caracterización basado en mínimos cuadrados para modelar su comportamiento ante cada longitud de onda. Se diseñó un circuito de acondicionamiento y se utiliza un microcontrolador para comunicarse con una computadora mediante puerto serie virtual.
Se validó el funcionamiento del dispositivo y del proceso de calibración comparando los resultados obtenidos sobre superficies de distintos colores con los de una aplicación móvil de referencia.
Palabras clave: Sensor de color, fotorresistencia, LDR, reflexión, calibración.

## 2. Introducción

El color es una percepción visual que surge debido a la detección de diferentes longitudes de onda que no son absorbidas por un objeto o superficie. El conjunto de señales de distintas frecuencias compone el color de dicho objeto. Estas, dentro del espectro visible de la luz, abarcan una gama de ´ colores que va desde el rojo, con frecuencias más bajas y longitudes de onda más largas, hasta el violeta, con frecuencias más altas y longitudes de onda más cortas.
Durante el desarrollo de este trabajo, se diseñó e implementó un dispositivo que permite obtener un estimado del color de una superficie mediante la reflexión de luz. Este utiliza una resistencia dependiente de la luz (LDR) para la detección de la luz reflejada desde la superficie objetivo.
El principio de funcionamiento consiste en colocar el dispositivo sobre la superficie que se desea medir, y los iluminantes del sensor iluminan la superficie utilizando luz roja, verde, y azul por separado. Una vez iluminada la superficie, se mide la resistencia del LDR, y se estima la intensidad de la luz reflejada. El proceso se repite para cada color, y al final se obtiene una estimación del color de la superficie mediante un código RGB de 24 bits, el cual es un formato común y ampliamente utilizado para representar color,

3

Universidad Tecnológica Nacional 8 Abril Año 2026

Técnicas Digitales III, Medidas Electrónicas II Ing. Daniele, Fernando — Ing. Bossio, Jorge

en especial de forma digital.
Debido a la baja trazabilidad de los LDR en general y su amplio rango de respuesta (generalmente desde unos cuantos kilo-ohmios hasta el orden de los mega-ohmios), que además varía según la longitud de onda de la luz incidente, se implementó un procedimiento para caracterizar la respuesta del LDR. El objetivo es determinar la respuesta del LDR a las distintas longitudes de onda para mejorar las mediciones obtenidas.
Para tomar las mediciones se desarrolló un circuito de acondicionamiento para el LDR y la placa de desarrollo Raspberry Pi Pico, que utiliza el microcontrolador RP2040. El microcontrolador a su vez implementa un protocolo de comunicación simple mediante USB (utilizando la clase de comunicación puerto serie virtual), que le permite funcionar como dispositivo USB e intercambiar mensajes con una PC u otro host USB.
Por último, se desarrolló una aplicación CLI (interfaz de línea de comandos), que permite la comunicación con el dispositivo a través de USB. La principal motivación fue para facilitar el análisis de datos y la caracterización del LDR utilizando lenguajes de programación de alto nivel, tales como Python.

### 2.1. Antecedentes

Las opciones comerciales de este tipo de dispositivos suelen medir color al incidir sobre la superficie objetivo, rayos provenientes de una fuente de luz blanca. El color se determina mediante un arreglo de foto-detectores, que generalmente consisten de foto-diodos con filtros RGB; cada foto-diodo detecta la intensidad de luz reflejada para una longitud de onda especifica, y se determina el color de la superficie en base a las intensidades relativas de luz captadas por cada uno. Este trabajo busca explorar la posibilidad de cumplir la misma función utilizando componentes más fácilmente accesibles y económicos, compensando las desventajas evidentes del LDR mediante una secuencia de calibración que permita obtener resultados repetibles.

### 2.2. Objetivos

El objetivo de este trabajo consiste en desarrollar un dispositivo de bajo costo que permita determinar el color de un objeto con un grado de precisión aceptable mediante la reflexión de luz sobre su superficie. A su vez, se implementará un procedimiento de calibración para conocer la respuesta del LDR utilizado en el dispositivo. Para facilitar la operación y el procesamiento de las mediciones, se desarrollará además una aplicación de escritorio que permita interactuar con el dispositivo y visualizar los resultados obtenidos.

4

Universidad Tecnológica Nacional 8 Abril Año 2026

Técnicas Digitales III, Medidas Electrónicas II Ing. Daniele, Fernando — Ing. Bossio, Jorge
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

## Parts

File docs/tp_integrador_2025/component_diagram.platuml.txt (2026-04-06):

@startuml
interface "USB/CDC" as usb

package "Host" {
  [pyserial] as pyserial
  [CLI] <-> [Serialpal]
  [Serialpal] <-> pyserial
}

package "Device" {
  component "ACP protocol" as acp {
  }

  frame "USB Task" {
    component "TinyUSB" as tusb {
      [rx_fifo] <-> [tud_task]
      [tud_task] <--> [tx_fifo]
      
    }
    [Message Buffer] -> [tx_fifo]
    [rx_fifo] --> [RX Callback]
    
  }

  frame "Worker Task" {
    [Command Queue] -> [Action]
  }

  [Action] --> acp : msg_out
  [Command Queue] <-- acp : cmd_in

  [RX Callback] --> acp : msg_in
  [Message Buffer] <-- acp : resp_out

}

pyserial <--> usb
usb <--> [tud_task]

@enduml

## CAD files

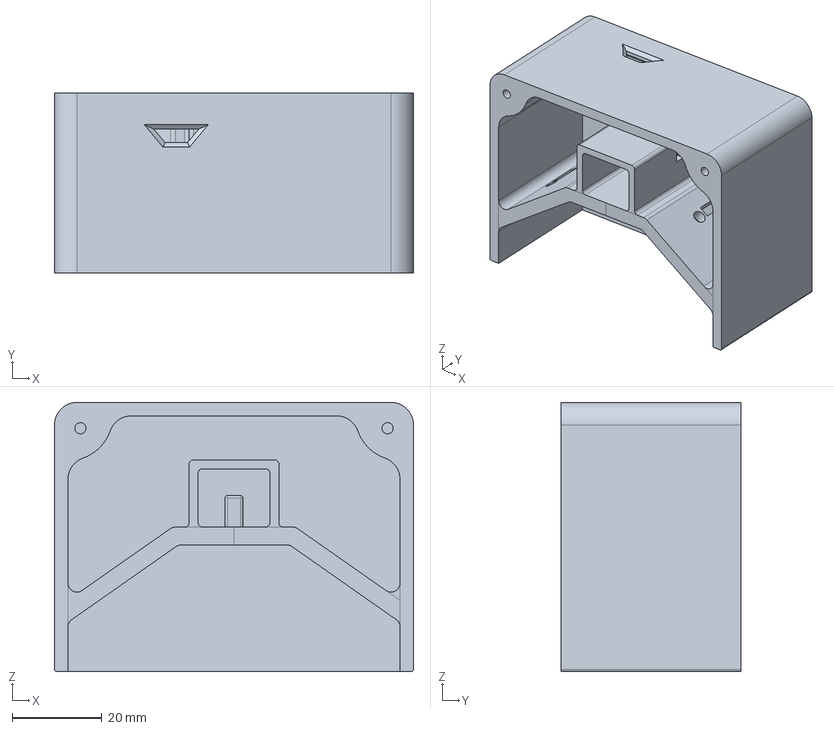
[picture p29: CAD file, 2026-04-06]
hardware/enclosure_v1.FCStd
80.0 x 40.0 x 60.0 mm

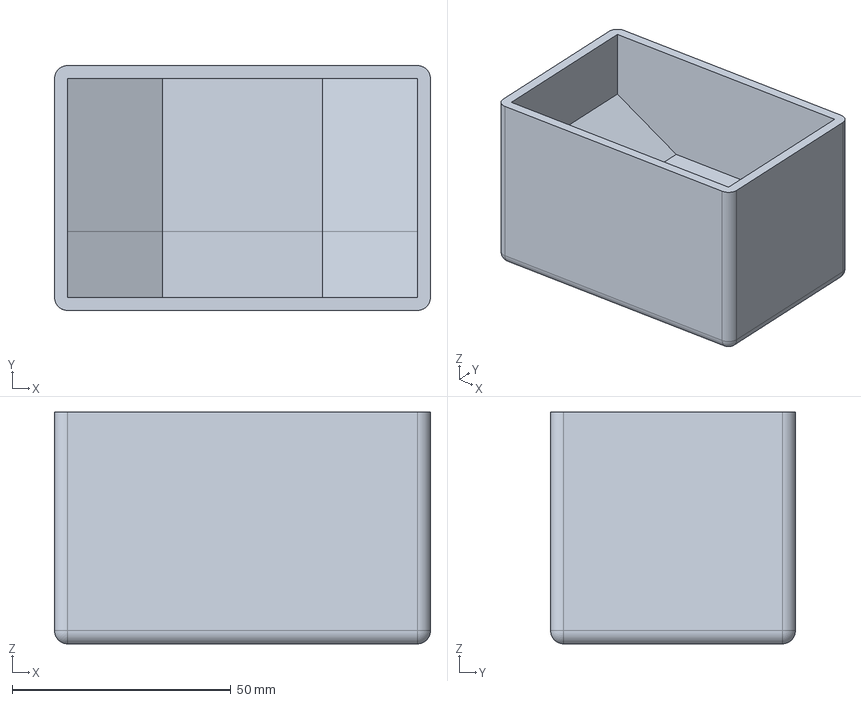
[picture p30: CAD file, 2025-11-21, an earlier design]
hardware/enclosure_v0.FCStd
86.0 x 56.0 x 53.0 mm

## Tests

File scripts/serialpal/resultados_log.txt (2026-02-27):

(serialpal) measure
b'&SET_RES,,*'
OK (11)
b'&SET_LED,0,0xff0000*'
OK (20)
b'&SET_RES,+,*'
OK (12)
b'&SET_RES,+,*'
OK (12)
b'&ADC,,*'
OK (7)
chan R: adc=124.125
b'&SET_RES,-,*'
OK (12)
b'&ADC,,*'
OK (7)
chan R: adc=810.925
b'&SET_RES,-,*'
OK (12)
b'&ADC,,*'
OK (7)
chan R: adc=2259.725
chan R: color=159
b'&SET_LED,0,0xff00*'
OK (18)
b'&SET_RES,+,*'
OK (12)
b'&SET_RES,+,*'
OK (12)
b'&ADC,,*'
OK (7)
chan G: adc=121.9
b'&SET_RES,-,*'
OK (12)
b'&ADC,,*'
OK (7)
chan G: adc=803.825
b'&SET_RES,-,*'
OK (12)
b'&ADC,,*'
OK (7)
chan G: adc=3246.325
chan G: color=271
b'&SET_LED,0,0xff*'
OK (16)
b'&SET_RES,+,*'
OK (12)
b'&SET_RES,+,*'
OK (12)
b'&ADC,,*'
OK (7)
chan B: adc=118.25
b'&SET_RES,-,*'
OK (12)
b'&ADC,,*'
OK (7)
chan B: adc=795.0
b'&SET_RES,-,*'
OK (12)
b'&ADC,,*'
OK (7)
chan B: adc=3614.1
chan B: color=184
b'&SET_LED,0,0x0*'
OK (15)
rgb(159, 255, 184)

(serialpal) measure
b'&SET_RES,,*'
OK (11)
b'&SET_LED,0,0xff0000*'
OK (20)
b'&SET_RES,+,*'
OK (12)
b'&SET_RES,+,*'
OK (12)
b'&ADC,,*'
OK (7)
chan R: adc=123.925
b'&SET_RES,-,*'
OK (12)
b'&ADC,,*'
OK (7)
chan R: adc=810.875
b'&SET_RES,-,*'
OK (12)
b'&ADC,,*'
OK (7)
chan R: adc=2258.175
chan R: color=159
b'&SET_LED,0,0xff00*'
OK (18)
b'&SET_RES,+,*'
OK (12)
b'&SET_RES,+,*'
OK (12)
b'&ADC,,*'
OK (7)
chan G: adc=122.0
b'&SET_RES,-,*'
OK (12)
b'&ADC,,*'
OK (7)
chan G: adc=804.2
b'&SET_RES,-,*'
OK (12)
b'&ADC,,*'
OK (7)
chan G: adc=3261.7
chan G: color=265
b'&SET_LED,0,0xff*'
OK (16)
b'&SET_RES,+,*'
OK (12)
b'&SET_RES,+,*'
OK (12)
b'&ADC,,*'
OK (7)
chan B: adc=118.5
b'&SET_RES,-,*'
OK (12)
b'&ADC,,*'
OK (7)
chan B: adc=794.85
b'&SET_RES,-,*'
OK (12)
b'&ADC,,*'
OK (7)
chan B: adc=3624.55
chan B: color=179
b'&SET_LED,0,0x0*'
OK (15)
rgb(159, 255, 179)

(serialpal) measure
b'&SET_RES,,*'
OK (11)
b'&SET_LED,0,0xff0000*'
OK (20)
b'&SET_RES,+,*'
OK (12)
b'&SET_RES,+,*'
OK (12)
b'&ADC,,*'
OK (7)
chan R: adc=124.3
b'&SET_RES,-,*'
OK (12)
b'&ADC,,*'
OK (7)
chan R: adc=812.35
b'&SET_RES,-,*'
OK (12)
b'&ADC,,*'
OK (7)
chan R: adc=1487.725
chan R: color=240
b'&SET_LED,0,0xff00*'
OK (18)
b'&SET_RES,+,*'
OK (12)
b'&SET_RES,+,*'
OK (12)
b'&ADC,,*'
OK (7)
chan G: adc=122.325
b'&SET_RES,-,*'
OK (12)
b'&ADC,,*'
OK (7)
chan G: adc=804.95
b'&SET_RES,-,*'
OK (12)
b'&ADC,,*'
OK (7)
chan G: adc=3146.45
chan G: color=309
b'&SET_LED,0,0xff*'
OK (16)
b'&SET_RES,+,*'
OK (12)
b'&SET_RES,+,*'
OK (12)
b'&ADC,,*'
OK (7)
chan B: adc=119.7
b'&SET_RES,-,*'
OK (12)
b'&ADC,,*'
OK (7)
chan B: adc=797.6
b'&SET_RES,-,*'
OK (12)
b'&ADC,,*'
OK (7)
chan B: adc=3534.925
chan B: color=221
b'&SET_LED,0,0x0*'
OK (15)
rgb(240, 255, 221)

(serialpal) measure
b'&SET_RES,,*'
OK (11)
b'&SET_LED,0,0xff0000*'
OK (20)
b'&SET_RES,+,*'
OK (12)
b'&SET_RES,+,*'
OK (12)
b'&ADC,,*'
OK (7)
chan R: adc=124.625
b'&SET_RES,-,*'
OK (12)
b'&ADC,,*'
OK (7)
chan R: adc=812.775
b'&SET_RES,-,*'
OK (12)
b'&ADC,,*'
OK (7)
chan R: adc=1502.6
chan R: color=239
b'&SET_LED,0,0xff00*'
OK (18)
b'&SET_RES,+,*'
OK (12)
b'&SET_RES,+,*'
OK (12)
b'&ADC,,*'
OK (7)
chan G: adc=122.25
b'&SET_RES,-,*'
OK (12)
b'&ADC,,*'
OK (7)
chan G: adc=805.175
b'&SET_RES,-,*'
OK (12)
b'&ADC,,*'
OK (7)
chan G: adc=3156.3
chan G: color=305
b'&SET_LED,0,0xff*'
OK (16)
b'&SET_RES,+,*'
OK (12)
b'&SET_RES,+,*'
OK (12)
b'&ADC,,*'
OK (7)
chan B: adc=119.775
b'&SET_RES,-,*'
OK (12)
b'&ADC,,*'
OK (7)
chan B: adc=797.35
b'&SET_RES,-,*'
OK (12)
b'&ADC,,*'
OK (7)
chan B: adc=3541.8
chan B: color=218
b'&SET_LED,0,0x0*'
OK (15)
rgb(239, 255, 218)

(serialpal) measure
b'&SET_RES,,*'
OK (11)
b'&SET_LED,0,0xff0000*'
OK (20)
b'&SET_RES,+,*'
OK (12)
b'&SET_RES,+,*'
OK (12)
b'&ADC,,*'
OK (7)
chan R: adc=123.85
b'&SET_RES,-,*'
OK (12)
b'&ADC,,*'
OK (7)
chan R: adc=809.75
b'&SET_RES,-,*'
OK (12)
b'&ADC,,*'
OK (7)
chan R: adc=2509.325
chan R: color=134
b'&SET_LED,0,0xff00*'
OK (18)
b'&SET_RES,+,*'
OK (12)
b'&SET_RES,+,*'
OK (12)
b'&ADC,,*'
OK (7)
chan G: adc=121.85
b'&SET_RES,-,*'
OK (12)
b'&ADC,,*'
OK (7)
chan G: adc=803.3
b'&SET_RES,-,*'
OK (12)
b'&ADC,,*'
OK (7)
chan G: adc=3285.925
chan G: color=256
b'&SET_LED,0,0xff*'
OK (16)
b'&SET_RES,+,*'
OK (12)
b'&SET_RES,+,*'
OK (12)
b'&ADC,,*'
OK (7)
chan B: adc=121.05
b'&SET_RES,-,*'
OK (12)
b'&ADC,,*'
OK (7)
chan B: adc=801.1
b'&SET_RES,-,*'
OK (12)
b'&ADC,,*'
OK (7)
chan B: adc=3404.95
chan B: color=285
b'&SET_LED,0,0x0*'
OK (15)
rgb(134, 255, 255)

(serialpal) measure
b'&SET_RES,,*'
OK (11)
b'&SET_LED,0,0xff0000*'
OK (20)
b'&SET_RES,+,*'
OK (12)
b'&SET_RES,+,*'
OK (12)
b'&ADC,,*'
OK (7)
chan R: adc=123.625
b'&SET_RES,-,*'
OK (12)
b'&ADC,,*'
OK (7)
chan R: adc=809.85
b'&SET_RES,-,*'
OK (12)
b'&ADC,,*'
OK (7)
chan R: adc=2499.725
chan R: color=135
b'&SET_LED,0,0xff00*'
OK (18)
b'&SET_RES,+,*'
OK (12)
b'&SET_RES,+,*'
OK (12)
b'&ADC,,*'
OK (7)
chan G: adc=122.0
b'&SET_RES,-,*'
OK (12)
b'&ADC,,*'
OK (7)
chan G: adc=803.15
b'&SET_RES,-,*'
OK (12)
b'&ADC,,*'
OK (7)
chan G: adc=3285.725
chan G: color=257
b'&SET_LED,0,0xff*'
OK (16)
b'&SET_RES,+,*'
OK (12)
b'&SET_RES,+,*'
OK (12)
b'&ADC,,*'
OK (7)
chan B: adc=121.075
b'&SET_RES,-,*'
OK (12)
b'&ADC,,*'
OK (7)
chan B: adc=800.85
b'&SET_RES,-,*'
OK (12)
b'&ADC,,*'
OK (7)
chan B: adc=3405.35
chan B: color=285
b'&SET_LED,0,0x0*'
OK (15)
rgb(135, 255, 255)

(serialpal) measure
b'&SET_RES,,*'
OK (11)
b'&SET_LED,0,0xff0000*'
OK (20)
b'&SET_RES,+,*'
OK (12)
b'&SET_RES,+,*'
OK (12)
b'&ADC,,*'
OK (7)
chan R: adc=124.675
b'&SET_RES,-,*'
OK (12)
b'&ADC,,*'
OK (7)
chan R: adc=812.6
b'&SET_RES,-,*'
OK (12)
b'&ADC,,*'
OK (7)
chan R: adc=1593.7
chan R: color=229
b'&SET_LED,0,0xff00*'
OK (18)
b'&SET_RES,+,*'
OK (12)
b'&SET_RES,+,*'
OK (12)
b'&ADC,,*'
OK (7)
chan G: adc=120.65
b'&SET_RES,-,*'
OK (12)
b'&ADC,,*'
OK (7)
chan G: adc=798.925
b'&SET_RES,-,*'
OK (12)
b'&ADC,,*'
OK (7)
chan G: adc=3505.275
chan G: color=177
b'&SET_LED,0,0xff*'
OK (16)
b'&SET_RES,+,*'
OK (12)
b'&SET_RES,+,*'
OK (12)
b'&ADC,,*'
OK (7)
chan B: adc=119.7
b'&SET_RES,-,*'
OK (12)
b'&ADC,,*'
OK (7)
chan B: adc=797.1
b'&SET_RES,-,*'
OK (12)
b'&ADC,,*'
OK (7)
chan B: adc=3556.3
chan B: color=211
b'&SET_LED,0,0x0*'
OK (15)
rgb(229, 177, 211)

(serialpal) measure
b'&SET_RES,,*'
OK (11)
b'&SET_LED,0,0xff0000*'
OK (20)
b'&SET_RES,+,*'
OK (12)
b'&SET_RES,+,*'
OK (12)
b'&ADC,,*'
OK (7)
chan R: adc=124.45
b'&SET_RES,-,*'
OK (12)
b'&ADC,,*'
OK (7)
chan R: adc=812.6
b'&SET_RES,-,*'
OK (12)
b'&ADC,,*'
OK (7)
chan R: adc=1596.1
chan R: color=229
b'&SET_LED,0,0xff00*'
OK (18)
b'&SET_RES,+,*'
OK (12)
b'&SET_RES,+,*'
OK (12)
b'&ADC,,*'
OK (7)
chan G: adc=120.325
b'&SET_RES,-,*'
OK (12)
b'&ADC,,*'
OK (7)
chan G: adc=798.9
b'&SET_RES,-,*'
OK (12)
b'&ADC,,*'
OK (7)
chan G: adc=3507.325
chan G: color=177
b'&SET_LED,0,0xff*'
OK (16)
b'&SET_RES,+,*'
OK (12)
b'&SET_RES,+,*'
OK (12)
b'&ADC,,*'
OK (7)
chan B: adc=119.875
b'&SET_RES,-,*'
OK (12)
b'&ADC,,*'
OK (7)
chan B: adc=797.525
b'&SET_RES,-,*'
OK (12)
b'&ADC,,*'
OK (7)
chan B: adc=3557.775
chan B: color=211
b'&SET_LED,0,0x0*'
OK (15)
rgb(229, 177, 211)

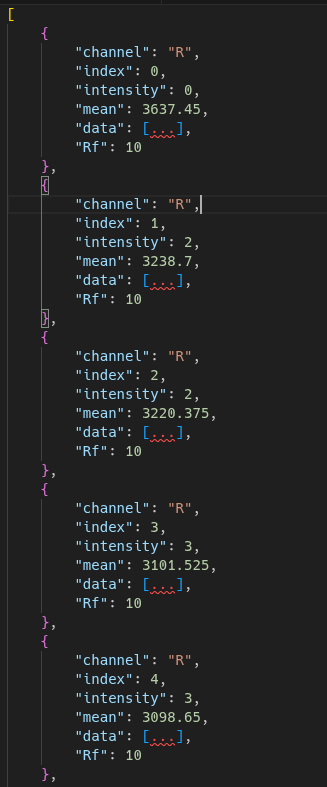
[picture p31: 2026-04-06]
docs/tp_integrador_2025/img/beamer/resultados_barrido.png

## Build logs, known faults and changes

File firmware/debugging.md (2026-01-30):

# Blackmagic + STLinkv2 for RP2040

- https://black-magic.org/index.html
- https://github.com/blackmagic-debug/blackmagic
- https://github.com/blackmagic-debug/blackmagic/tree/main/src/platforms
- https://github.com/blackmagic-debug/stlink-tool

Se necesita:
- Blackmagic firmware p/ STLink
- BMDA (la app que se comunica con el STLink)

En teoría no se necesita BMDA; una vez que se carga el firmware en el STLink ya se muestran los dos puertos serie, pero en Windows no se puede conectar directamente con GDB. (e.g., `tar ext \\.\COM11` no functiona). 

Al ejecutar BMDA con el STLink conectado, se forwardea el puerto serie a localhost, y este si se puede acceder desde GDB.
## 1. build Blackmagic stuff

```sh
git clone https://github.com/blackmagic-debug/blackmagic.git
```

Compilar con `meson`. Se compila el firmware para el STLink y la app de Blackmagic (BMDA).

Normalmente se especificaría un "cross-file", que es uno de varios archivos de configuración disponibles en la carpeta `cross-file` del repo. Este especifica detalles como la toolchain, CPU, endianness, y otras cositas. Las mas importantes son `probe` y `targets`:
- `probe` define el debugger que estamos usando 
- `targets` define los distintos MCU que se quieren debuggear

> Todas las opciones de config. se pueden ver en el archivo `meson-options.txt` del repo de Blackmagic.

Como el cross-file predefinido para STLink (`cross-file/stlink.ini`) no incluye el target para la RP2040 (`rp`), se podría editar el archivo y agregarlo manualmente. Como en este caso mi `probe`y `target` son fijos, los especifico manualmente, y uso la cross-file `cross-file/arm-none-eabi.ini`, que solo define las opciones básicas (toolchain, CPU, endianness).

```sh
meson setup build --cross-file cross-file/arm-none-eabi.ini -Dbmd_bootloader=false -Dprobe=stlink -Dtargets=rp
```

Otro detalle importante es que NO se incluye el bootloader de Blackmagic. Ellos ofrecen su propio debugger y su código parece incluir el bootloader especifico para su dispositivo por defecto.

Las instrucciones en https://github.com/blackmagic-debug/blackmagic/tree/main/src/platforms/stlink especifican compilar con `-Dbmd_bootloader=false` para no sobrescribir el bootloader propio del STLink.

Luego se compila:

```sh
meson compile -C build
```

Se deberian obtener dos binarios:
- `blackmagic_stlink_firmware.bin` es el firmware para el STLink
- `blackmagic.exe` es la app de escritorio que expone el puerto localhost al que se accede desde GDB
## 2. load STLink firmware

El STLink chinardo necesita una herramienta adicional para flashear el firmware de Blackmagic.

### 2a. build STLink flashing tool

Compilar la herramienta del siguiente repo: https://github.com/blackmagic-debug/stlink-tool

```sh
git clone https://github.com/jeanthom/stlink-tool
cd stlink-tool
git submodule update --init --depth 1
make
```

En caso de compilar desde Windows, se usa el fork de [sakana280](https://github.com/sakana280/stlink-tool)

```sh
git clone https://github.com/sakana280/stlink-tool
cd stlink-tool
git submodule update --init --depth 1
mingw32-make.exe
```

### 2b. load firmware w/ tool

```
stlink-tool /path/to/blackmagic_stlink_firmware.bin
```

Salida:
```
Firmware version : V2J46S7
Loader version : 14152
ST-Link ID : 4100070002000059534B524E
Firmware encryption key : 2BD5C9391507CCB9D0A10CECC8041617
Current mode : 1
Loaded firmware : .\blackmagic_stlink_firmware.bin, size : 63608 bytes
...............................................................
```

> Aparentemente hay que volver a correr el comando cada vez que se desconecta el STLink (es porque se conservo el bootloader original???).

Una vez que se carga el firmware, se deberían detectar dos puertos serie, tal como se explica en https://black-magic.org/getting-started.html.
## 3. run BMDA

Con el STLink conectado (con el firmware de Blackmagic), se ejecuta la BDMA (e.g., `blackmagic.exe`).

Salida:
```
Found AUX Serial at COM11
Using BMP at COM13
Listening on TCP port: 2000
```

## 4. debug

Se ejecuta GDB, se conecta al remoto, se hace un scan para detectar el micro, se conecta al micro, y se carga el programa y/o se debuggea:

```sh
arm-none-eabi-gdb firmware.elf
```

```
tar ext :2000
```

```
monitor auto_scan
...
Available Targets:
No. Att Driver
 1      RP2040 M0+
 2      RP2040 M0+
 3      RP2040 Rescue (Attach to reset)
...
```

```
attach 1
```

```
load
```

El primer `load` siempre me da un error como:

```
Loading section .boot2, size 0x100 lma 0x10000000
Loading section .text, size 0x915c lma 0x10000100
Error writing data to flash
```

Pero al reintentar el comando funciona.

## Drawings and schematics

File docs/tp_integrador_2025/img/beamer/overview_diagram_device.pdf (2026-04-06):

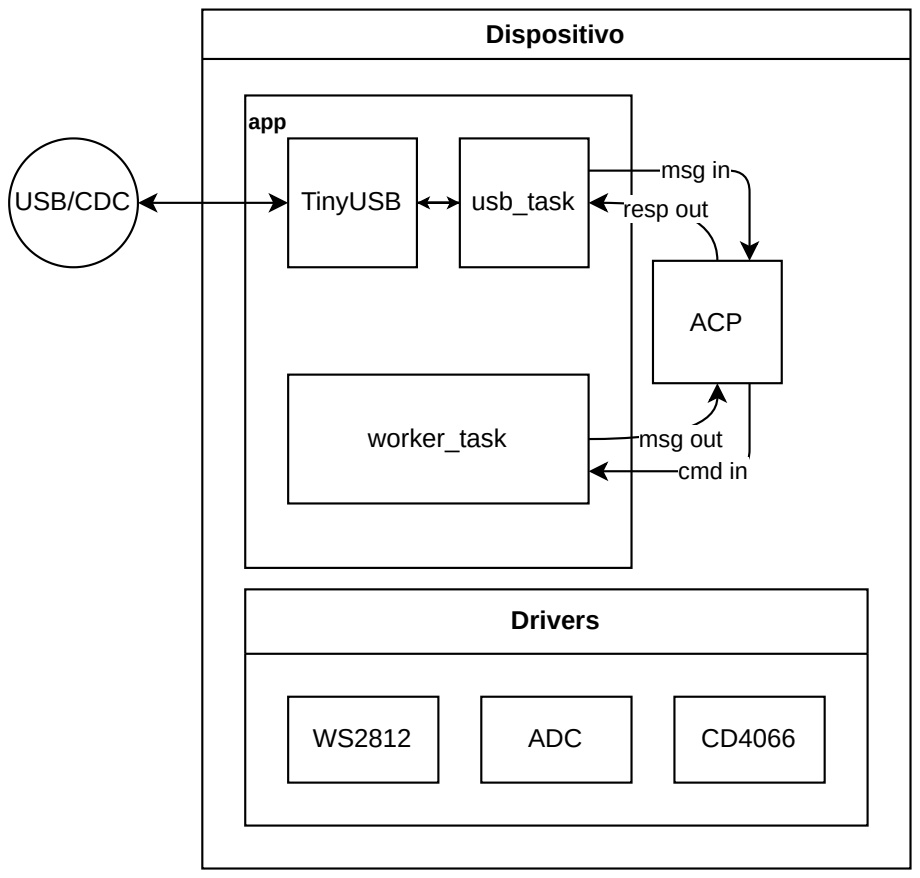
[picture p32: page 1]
Dispositivo; app; msg in; usb_task; worker_task; msg out; cmd in; ACP; Drivers; ADC; resp out USB/CDC; inyUSB

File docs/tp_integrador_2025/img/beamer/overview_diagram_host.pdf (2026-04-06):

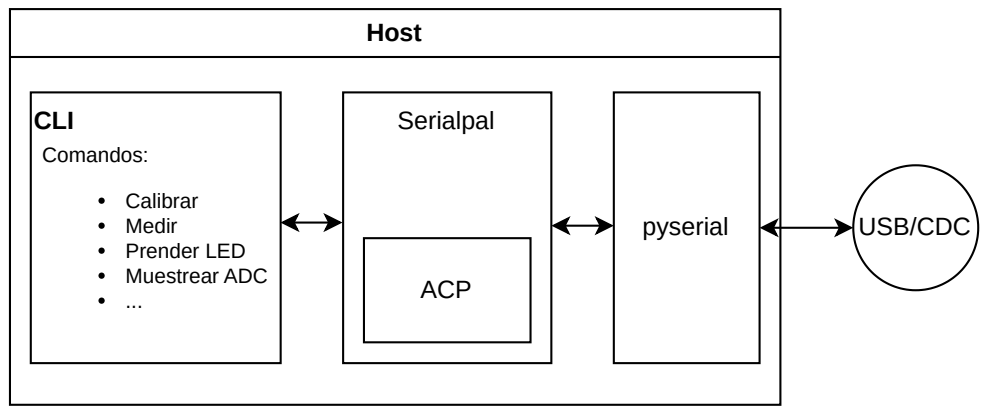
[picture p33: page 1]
Host; pyserial; CLI; Serialpal; Comandos:; Calibrar Medir Prender LED Muestrear ADC; ACP; USB/CDC

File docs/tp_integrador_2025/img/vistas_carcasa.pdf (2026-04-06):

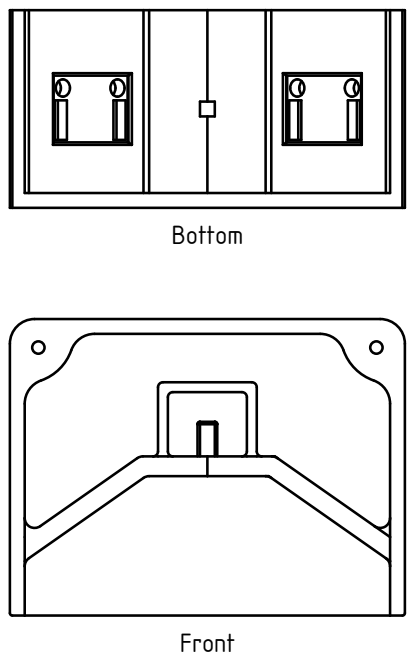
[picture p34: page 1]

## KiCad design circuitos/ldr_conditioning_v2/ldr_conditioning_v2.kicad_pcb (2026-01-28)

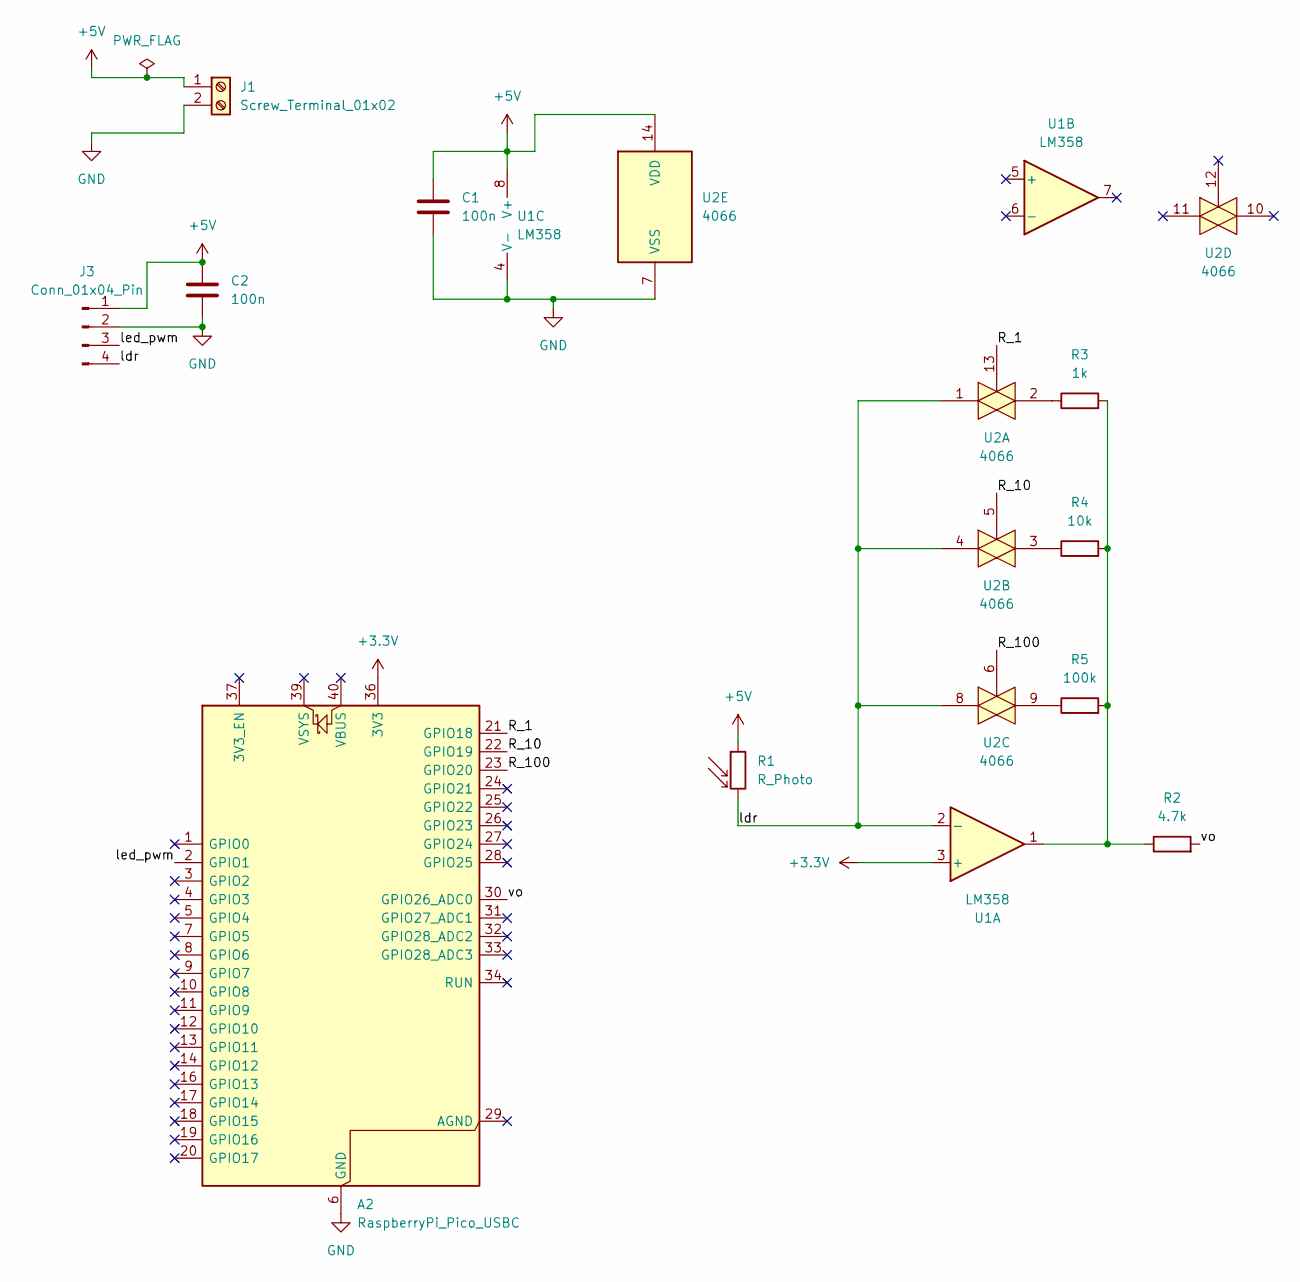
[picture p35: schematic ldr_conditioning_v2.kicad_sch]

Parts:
A2: RaspberryPi_Pico_USBC; RaspberryPi_Pico_Common_Unspecified
C1, C2: 100n; C_Disc_D5.0mm_W2.5mm_P2.50mm
J1: Screw_Terminal_01x02; TerminalBlock_Altech_AK300-2_P5.00mm
J3: Conn_01x04_Pin; PinHeader_1x04_P2.54mm_Vertical
R1: R_Photo; R_Axial_DIN0207_L6.3mm_D2.5mm_P10.16mm_Horizontal
R2: 4.7k; R_Axial_DIN0207_L6.3mm_D2.5mm_P10.16mm_Horizontal
R3: 1k; R_Axial_DIN0207_L6.3mm_D2.5mm_P10.16mm_Horizontal
R4: 10k; R_Axial_DIN0207_L6.3mm_D2.5mm_P10.16mm_Horizontal
R5: 100k; R_Axial_DIN0207_L6.3mm_D2.5mm_P10.16mm_Horizontal
U1: LM358; DIP-8_W7.62mm_Socket
U2: 4066; DIP-14_W7.62mm_Socket

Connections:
+3.3V: A2.36 (3V3), U1.3 (+)
+5V: C1.1, C2.1, J1.1, J3.1, R1.1, U1.8 (V+), U2.14 (VDD)
/R_1: A2.21 (GPIO18), U2.13
/R_10: A2.22 (GPIO19), U2.5
/R_100: A2.23 (GPIO20), U2.6
/ldr: J3.4, R1.2, U1.2 (-), U2.1, U2.4, U2.8
/led_pwm: A2.2 (GPIO1), J3.3
/vo: A2.30 (GPIO26_ADC0), R2.2
GND: A2.6 (GND), A2.15 (GND), A2.35 (GND), A2.38 (GND), C1.2, C2.2, J1.2, J3.2, U1.4 (V-), U2.7 (VSS)
unnamed: R2.1, R3.2, R4.2, R5.2, U1.1
unnamed: R3.1, U2.2
unnamed: R4.1, U2.3
unnamed: R5.1, U2.9

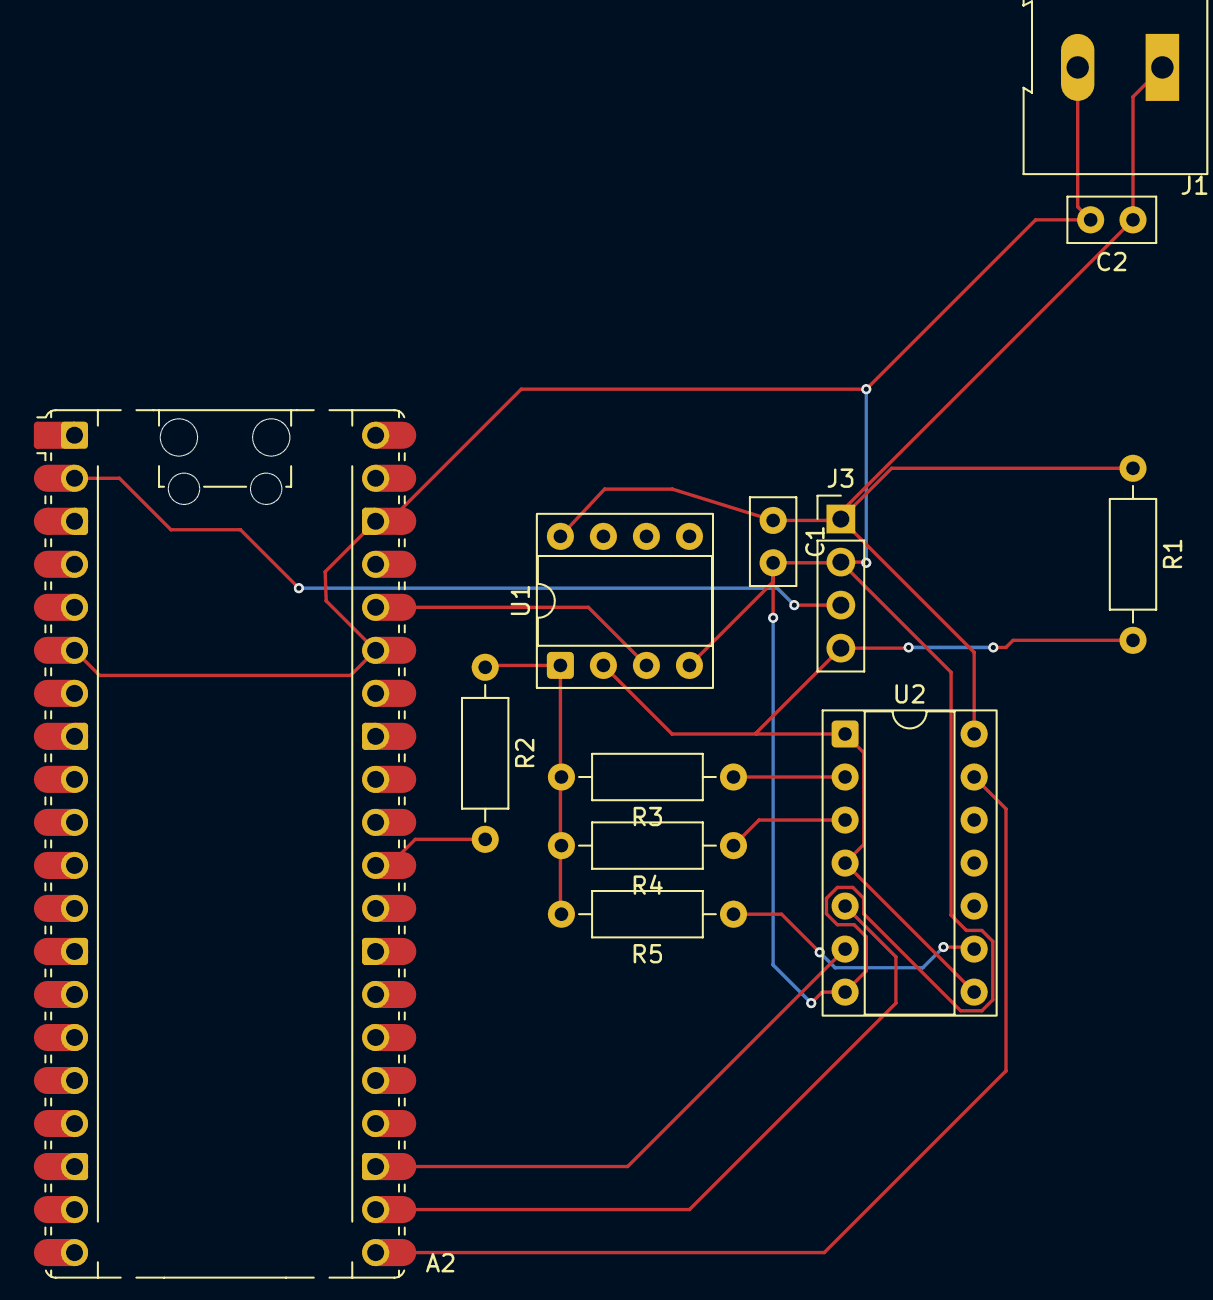
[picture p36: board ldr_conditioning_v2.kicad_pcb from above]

Board: 2 copper layers, 12 parts (0 on the bottom side), 13 nets.

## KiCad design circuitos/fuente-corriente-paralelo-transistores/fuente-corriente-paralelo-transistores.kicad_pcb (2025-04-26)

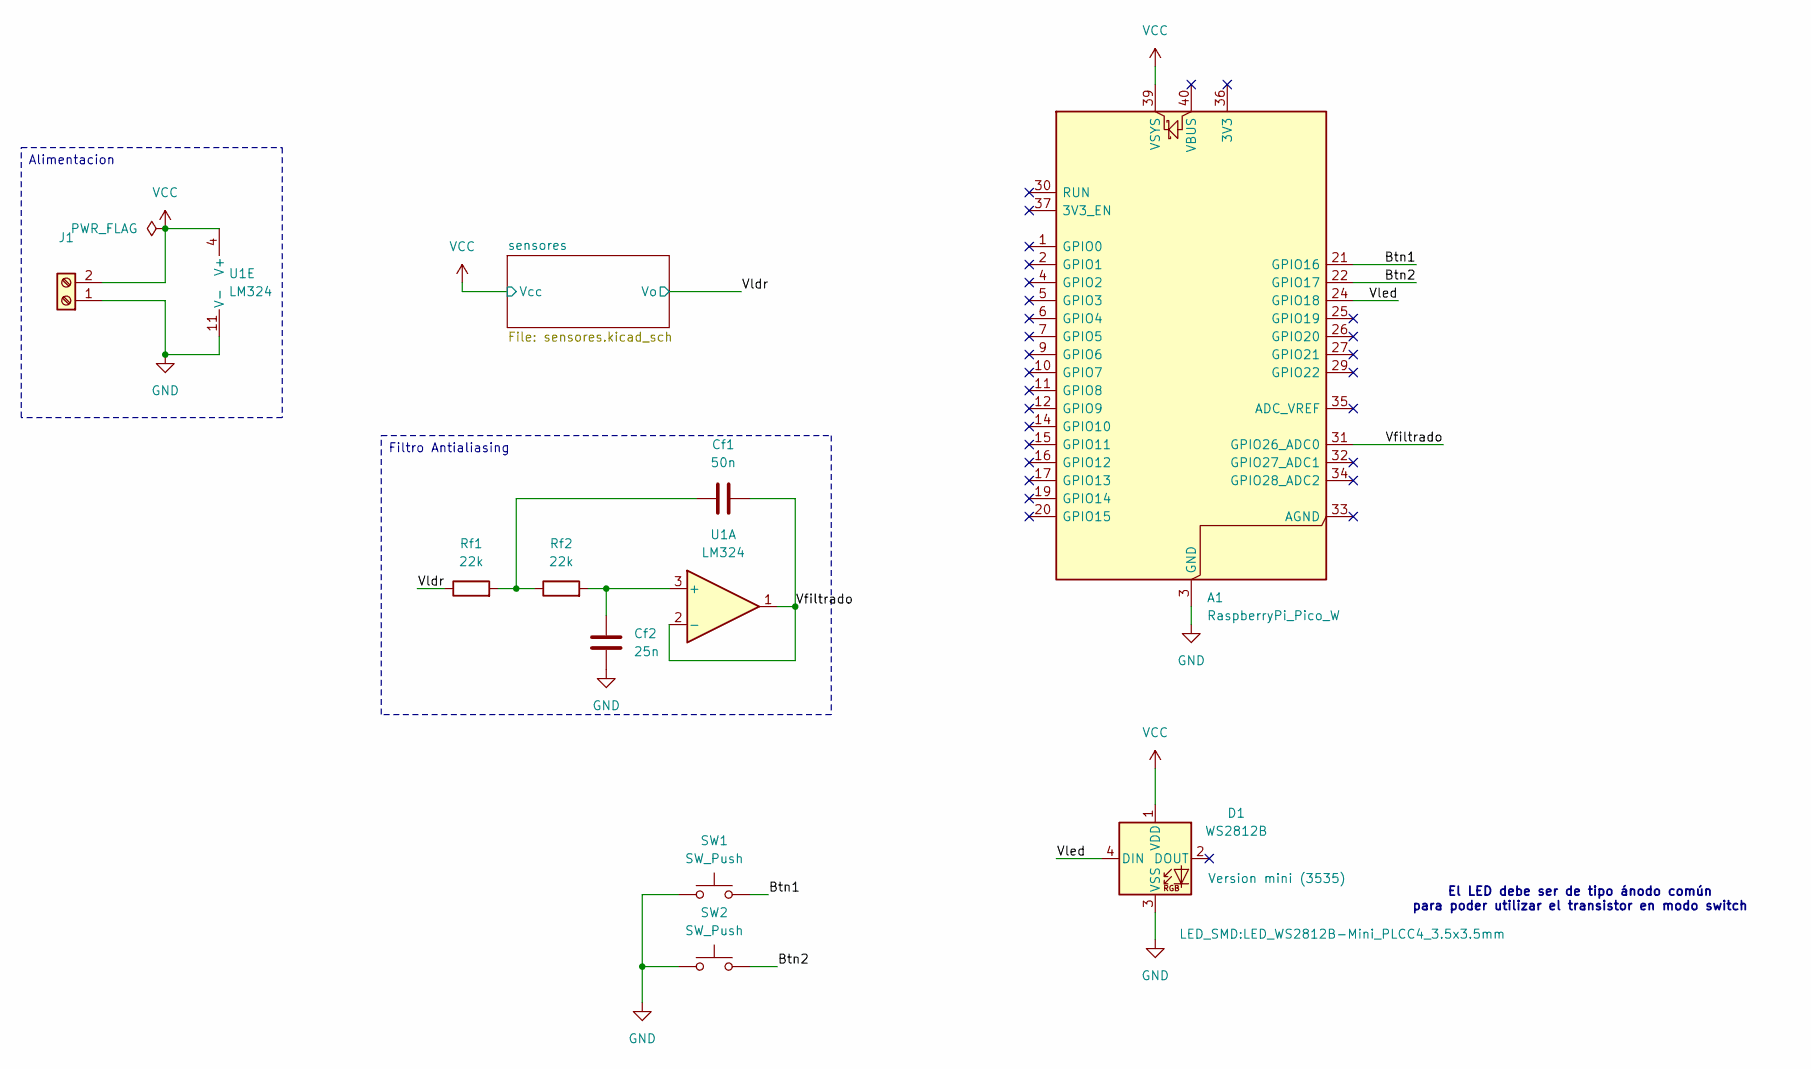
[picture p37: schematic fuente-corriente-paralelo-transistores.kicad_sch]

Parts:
A1: RaspberryPi_Pico_W; RaspberryPi_Pico_Common_THT
Cf1: 50n; C_Disc_D5.0mm_W2.5mm_P5.00mm
Cf2: 25n; C_Disc_D5.0mm_W2.5mm_P5.00mm
D1: WS2812B; LED_WS2812B-Mini_PLCC4_3.5x3.5mm
J1: TerminalBlock_bornier-2_P5.08mm
Rf1, Rf2: 22k; R_Axial_DIN0207_L6.3mm_D2.5mm_P7.62mm_Horizontal
SW1, SW2: SW_Push; SW_PUSH-12mm
U1: LM324; DIP-14_W7.62mm_Socket

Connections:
/Btn1: A1.21 (GPIO16), SW1.2
/Btn2: A1.22 (GPIO17), SW2.2
/Vfiltrado: A1.31 (GPIO26_ADC0), Cf1.1, U1.1, U1.2 (-)
/Vldr: Rf1.1; also elsewhere on the board
/Vled: A1.24 (GPIO18), D1.4 (DIN)
GND: A1.3 (GND), A1.8 (GND), A1.13 (GND), A1.18 (GND), A1.23 (GND), A1.28 (GND), A1.38 (GND), Cf2.2, D1.3 (VSS), J1.1, SW1.1, SW2.1, U1.11 (V-); also elsewhere on the board
unnamed: Cf1.2, Rf1.2, Rf2.1
unnamed: Cf2.1, Rf2.2, U1.3 (+)
VCC: A1.39 (VSYS), D1.1 (VDD), J1.2, U1.4 (V+); also elsewhere on the board

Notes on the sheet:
El LED debe ser de tipo ánodo común para poder utilizar el transistor en modo switch
Filtro Antialiasing
Alimentacion

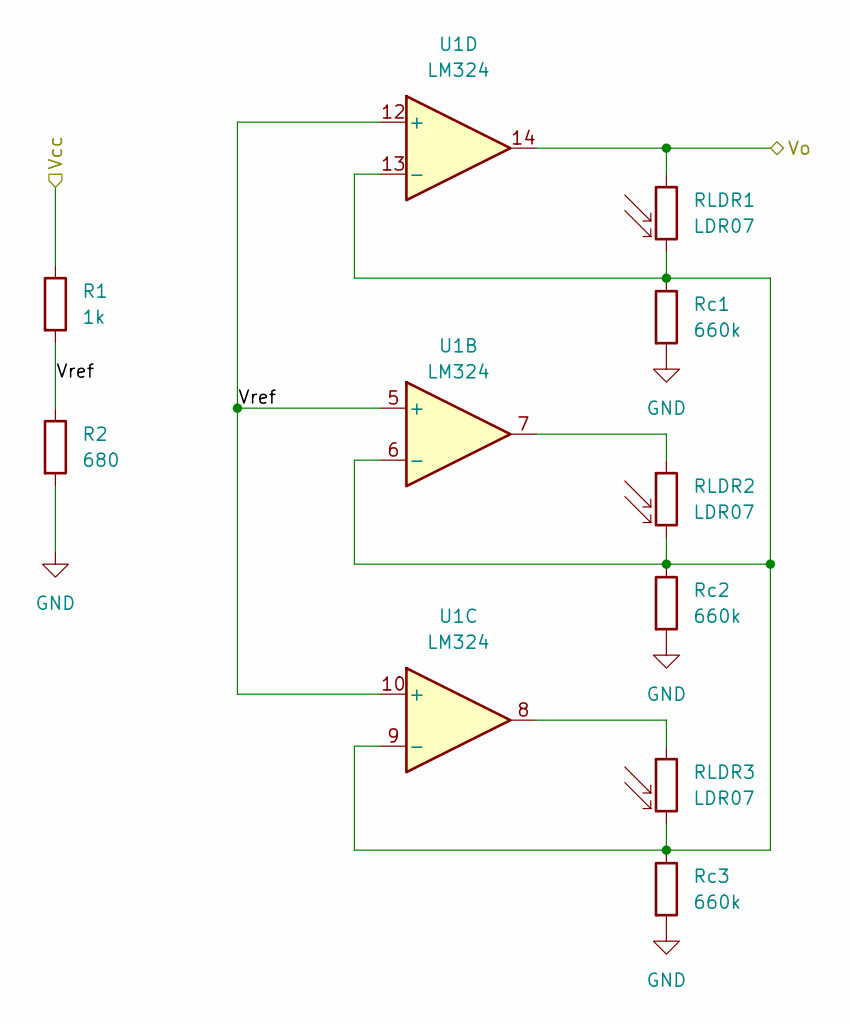
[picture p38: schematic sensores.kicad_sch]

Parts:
R1: 1k; R_Axial_DIN0207_L6.3mm_D2.5mm_P7.62mm_Horizontal
R2: 680; R_Axial_DIN0207_L6.3mm_D2.5mm_P7.62mm_Horizontal
RLDR1, RLDR2, RLDR3: LDR07; R_LDR_5.1x4.3mm_P3.4mm_Vertical
Rc1, Rc2, Rc3: 660k; R_Axial_DIN0207_L6.3mm_D2.5mm_P7.62mm_Horizontal
U1: LM324; DIP-14_W7.62mm_Socket

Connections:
/Vldr: RLDR1.1, U1.14; also elsewhere on the board
/sensores/Vref: R1.2, R2.1, U1.5 (+), U1.10 (+), U1.12 (+)
GND: R2.2, Rc1.2, Rc2.2, Rc3.2; also elsewhere on the board
unnamed: RLDR2.1, U1.7
unnamed: RLDR3.1, U1.8
unnamed: RLDR1.2, RLDR2.2, RLDR3.2, Rc1.1, Rc2.1, Rc3.1, U1.6 (-), U1.9 (-), U1.13 (-)
VCC: R1.1; also elsewhere on the board

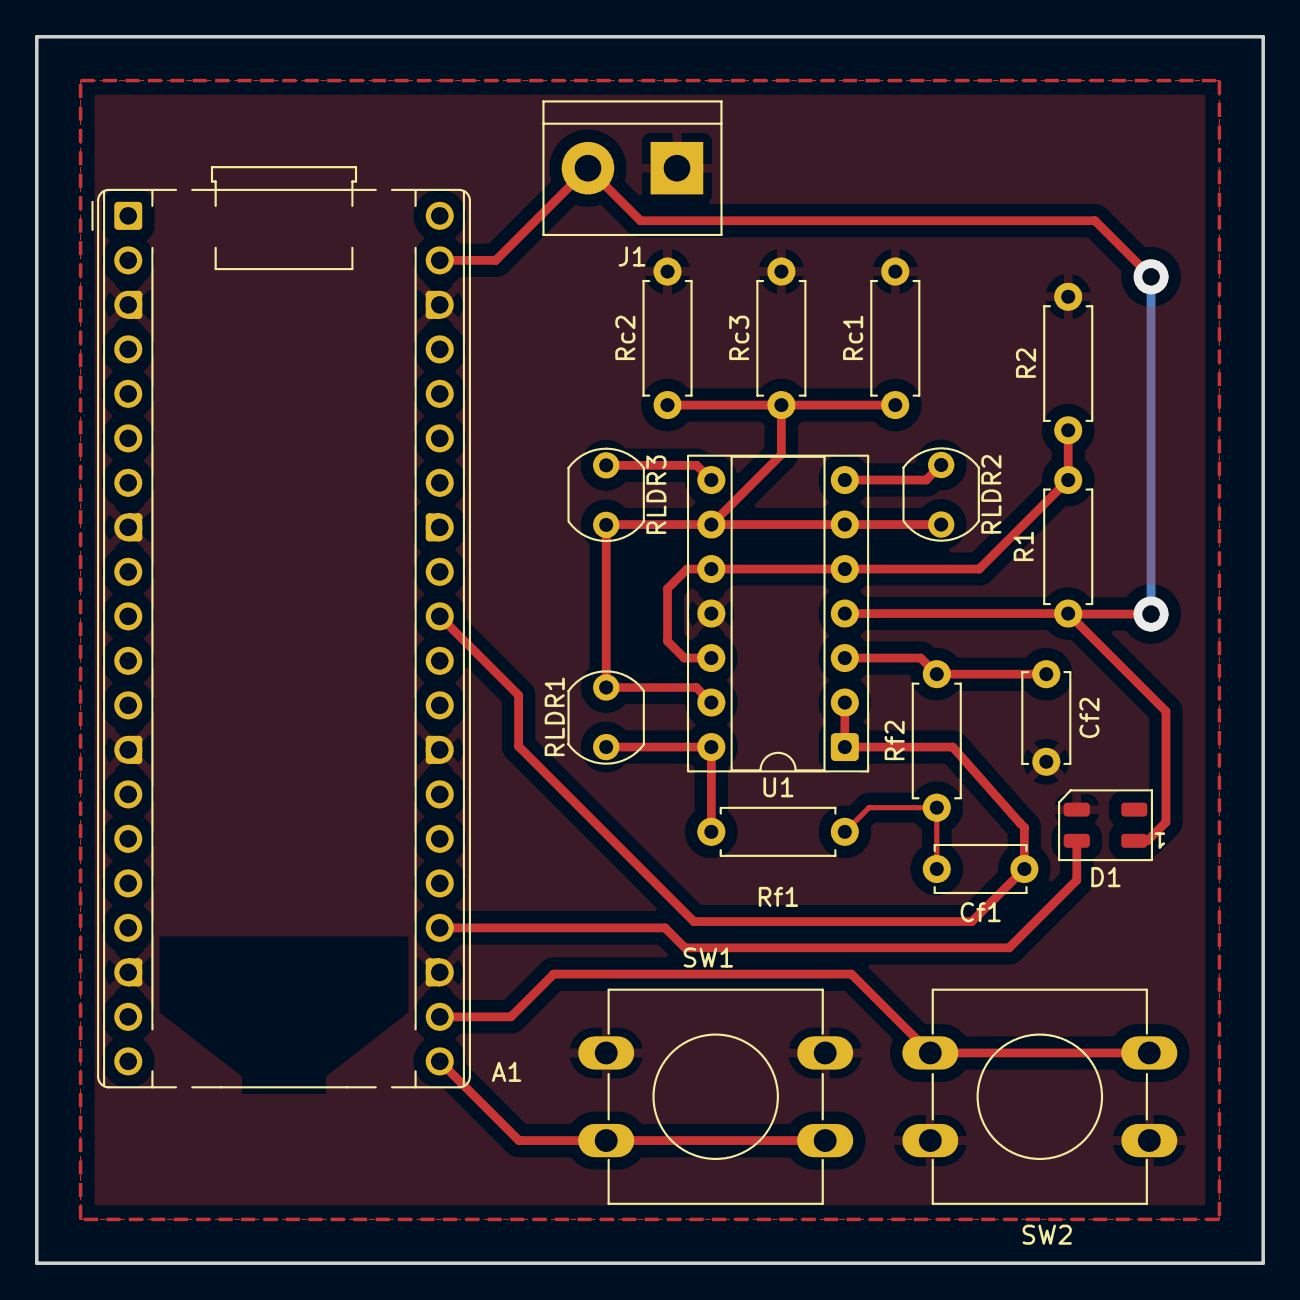
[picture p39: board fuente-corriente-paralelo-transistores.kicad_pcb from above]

Board: 2 copper layers, 70.0 x 70.0 mm, 18 parts (0 on the bottom side), 13 nets.

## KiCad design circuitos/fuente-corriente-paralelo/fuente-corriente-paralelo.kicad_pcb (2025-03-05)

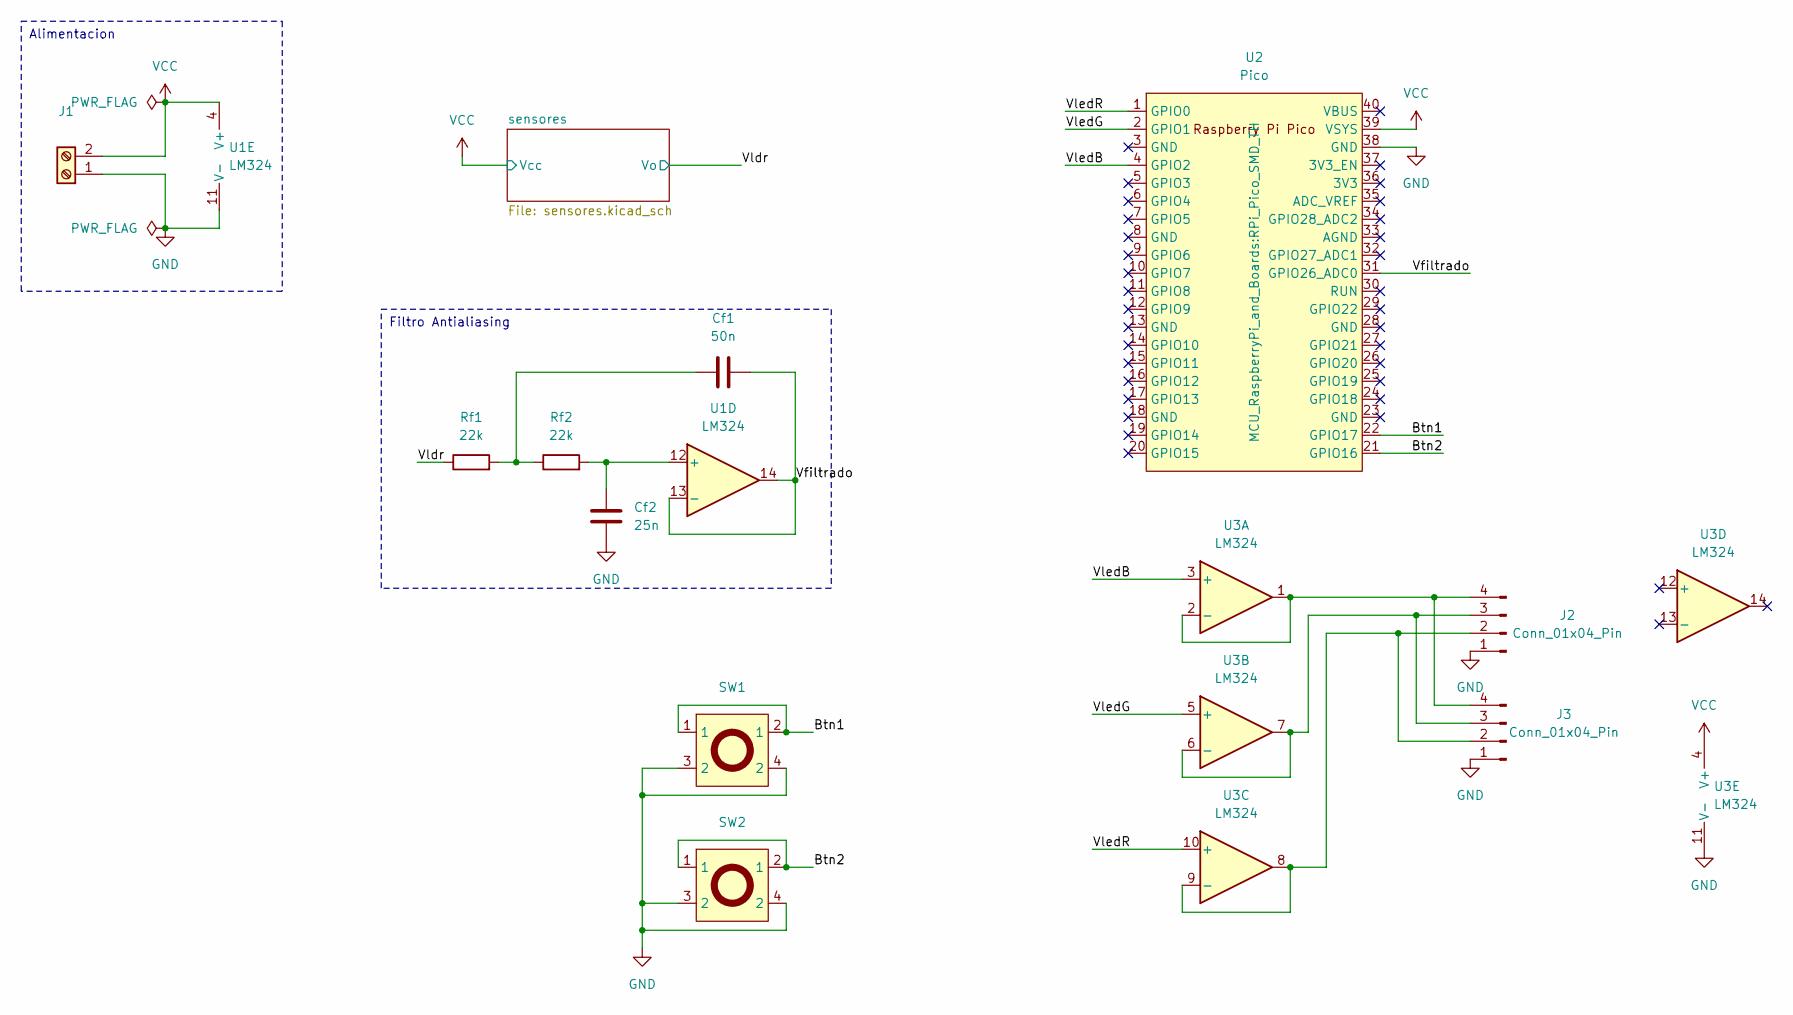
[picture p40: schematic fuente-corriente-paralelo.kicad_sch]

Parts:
Cf1: 50n; C_Disc_D5.0mm_W2.5mm_P5.00mm
Cf2: 25n; C_Disc_D5.0mm_W2.5mm_P5.00mm
J1: TerminalBlock_bornier-2_P5.08mm
J2, J3: Conn_01x04_Pin; PinHeader_1x04_P2.54mm_Vertical
Rf1, Rf2: 22k; R_Axial_DIN0207_L6.3mm_D2.5mm_P7.62mm_Horizontal
SW1, SW2: SW_PUSH-12mm
U1, U3: LM324; DIP-14_W7.62mm_Socket
U2: Pico; RPi_Pico_SMD_TH

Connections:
/Btn1: SW1.1, SW1.2 (1), U2.22 (GPIO17)
/Btn2: SW2.1, SW2.2 (1), U2.21 (GPIO16)
/Vfiltrado: Cf1.1, U1.13 (-), U1.14, U2.31 (GPIO26_ADC0)
/Vldr: Rf1.1; also elsewhere on the board
/VledB: U2.4 (GPIO2), U3.3 (+)
/VledG: U2.2 (GPIO1), U3.5 (+)
/VledR: U2.1 (GPIO0), U3.10 (+)
GND: Cf2.2, J1.1, J2.1, J3.1, SW1.3 (2), SW1.4 (2), SW2.3 (2), SW2.4 (2), U1.11 (V-), U2.38 (GND), U3.11 (V-); also elsewhere on the board
unnamed: Cf1.2, Rf1.2, Rf2.1
unnamed: J2.2, J3.2, U3.8, U3.9 (-)
unnamed: J2.3, J3.3, U3.6 (-), U3.7
unnamed: J2.4, J3.4, U3.1, U3.2 (-)
unnamed: Cf2.1, Rf2.2, U1.12 (+)
VCC: J1.2, U1.4 (V+), U2.39 (VSYS), U3.4 (V+); also elsewhere on the board

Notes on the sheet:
Filtro Antialiasing
Alimentacion

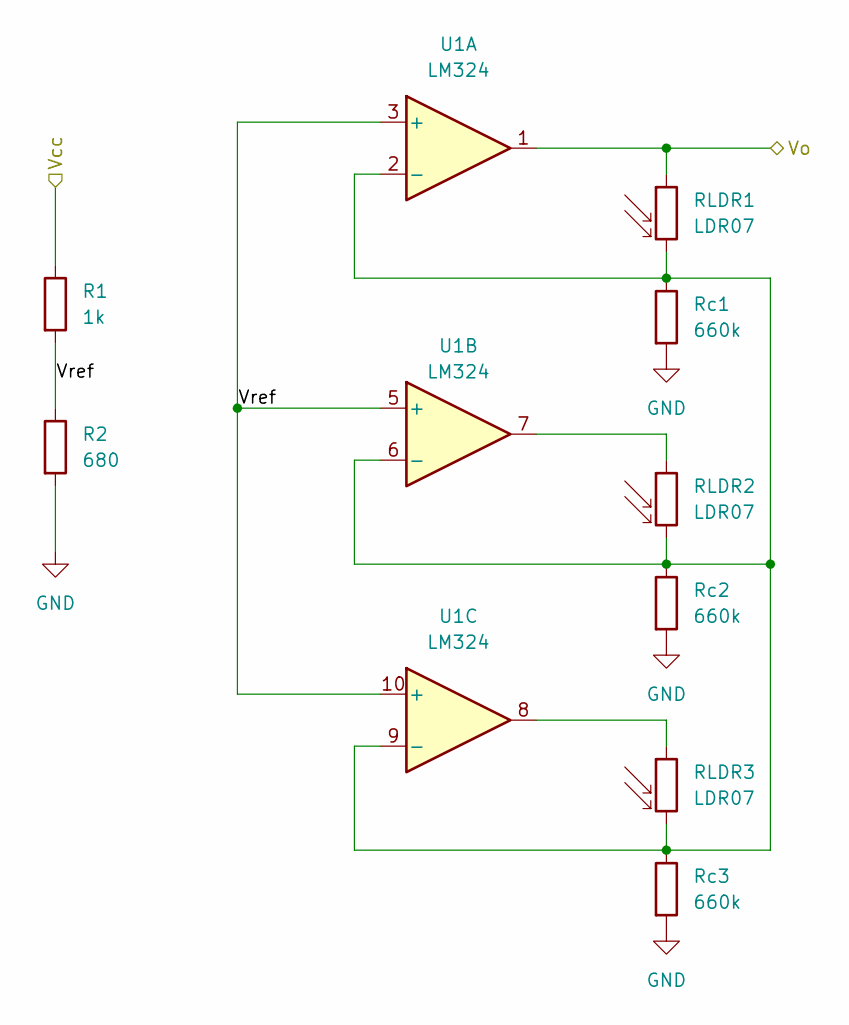
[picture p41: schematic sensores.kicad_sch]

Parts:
R1: 1k; R_Axial_DIN0207_L6.3mm_D2.5mm_P7.62mm_Horizontal
R2: 680; R_Axial_DIN0207_L6.3mm_D2.5mm_P7.62mm_Horizontal
RLDR1, RLDR2, RLDR3: LDR07; R_LDR_5.1x4.3mm_P3.4mm_Vertical
Rc1, Rc2, Rc3: 660k; R_Axial_DIN0207_L6.3mm_D2.5mm_P7.62mm_Horizontal
U1: LM324; DIP-14_W7.62mm_Socket

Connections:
/Vldr: RLDR1.1, U1.1; also elsewhere on the board
/sensores/Vref: R1.2, R2.1, U1.3 (+), U1.5 (+), U1.10 (+)
GND: R2.2, Rc1.2, Rc2.2, Rc3.2; also elsewhere on the board
unnamed: RLDR2.1, U1.7
unnamed: RLDR3.1, U1.8
unnamed: RLDR1.2, RLDR2.2, RLDR3.2, Rc1.1, Rc2.1, Rc3.1, U1.2 (-), U1.6 (-), U1.9 (-)
VCC: R1.1; also elsewhere on the board

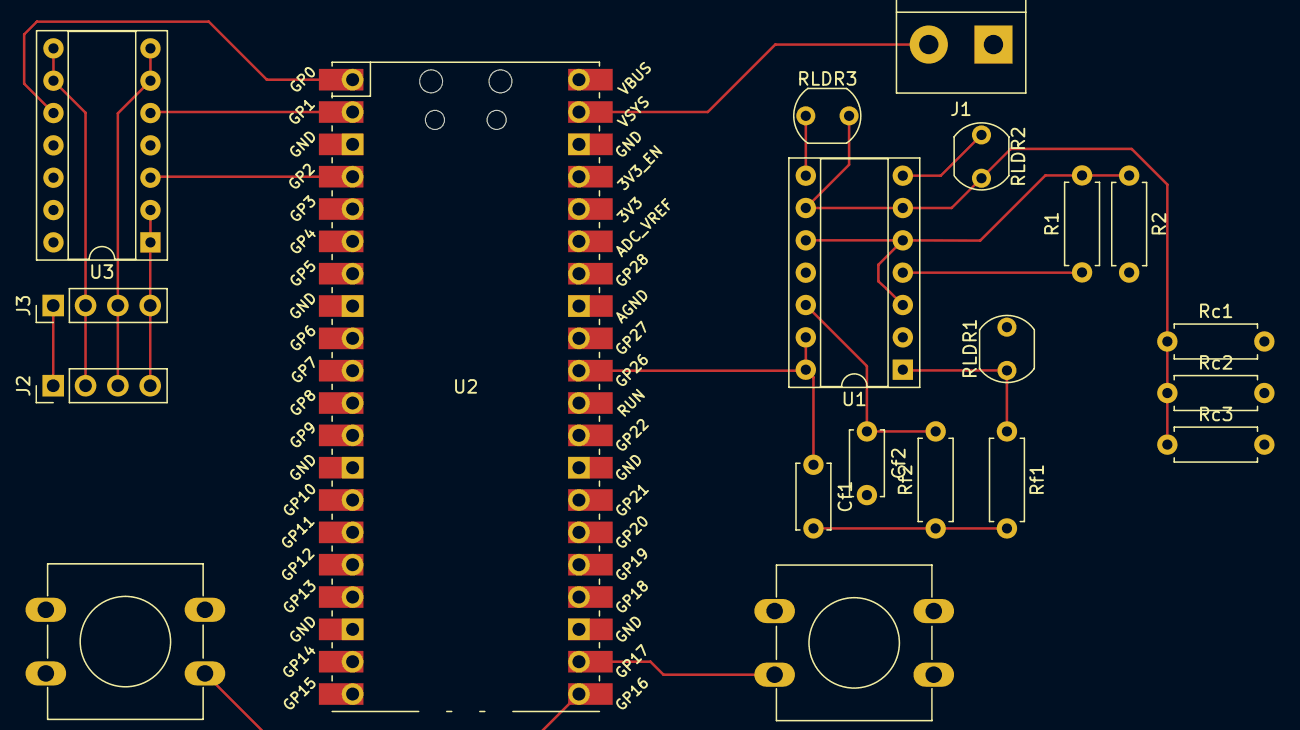
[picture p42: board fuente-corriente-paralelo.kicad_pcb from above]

Board: 2 copper layers, 20 parts (0 on the bottom side), 18 nets.

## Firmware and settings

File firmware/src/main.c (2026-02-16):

#include <stdlib.h>

#include "FreeRTOS.h"
#include "message_buffer.h"
#include "queue.h"
#include "task.h"

#include "tusb.h"

#include "hardware/gpio.h"
#include "pico/stdlib.h"

#include "board.h"
#include "drivers/adc.h"
#include "drivers/cd4066_resistor_picker.h"
#include "drivers/ws2812.h"
#include "serial_com.h"

#define TASK_DEFAULT_PRIORITY 10

#define TEST_MSG                                                               \
    ("\0\0\0\0\0\0\0\0\0aaaa\x22\xf1xxxxa\0\0\0\x22aaa\xf1xxxx\x22a"           \
     "aaa\xf1xxxx\x22aaaax"                                                    \
     "\xf1xxx\x22aaaa\xf1xxxxaaaaaaaaaa\xf1\0\0xxxxaaaaaaaaaa\xf1xx"           \
     "xxaa"                                                                    \
     "aaaaaaaa\xf1xxxx")

#define TEST_DATA                                                              \
    ((uint16_t[]){0xff22, 0xff22, 0xff22, 0xff22, 0xff22, 0x0011, 0x0011,      \
                  0x0011, 0x0011, 0x0011})

#define ADC_NUM_SAMPLES 40
uint16_t adc_buffer[ADC_NUM_SAMPLES] = {0};

/* Blink pattern
 * - 250 ms  : device not mounted
 * - 1000 ms : device mounted
 * - 2500 ms : device is suspended
 */
enum {
    BLINK_NOT_MOUNTED = 250,
    BLINK_MOUNTED = 1000,
    BLINK_SUSPENDED = 2500,
};

static bool blink_enable = false;
static uint32_t blink_interval_ms = BLINK_NOT_MOUNTED;

TaskHandle_t usb_task_handle = NULL;
TaskHandle_t worker_task_handle = NULL;
MessageBufferHandle_t tx_msg_buffer;
QueueHandle_t cmd_queue;

void status_led_init() {
    gpio_init(PICO_DEFAULT_LED_PIN);
    gpio_set_dir(PICO_DEFAULT_LED_PIN, GPIO_OUT);
    gpio_put(PICO_DEFAULT_LED_PIN, 0);
}

void status_led_set(bool state) { gpio_put(PICO_DEFAULT_LED_PIN, state); }

void led_task(void *arg) {
    bool led_state = false;

    while (1) {
        vTaskDelay(blink_interval_ms / portTICK_PERIOD_MS);

        if (blink_enable) {
            status_led_set(led_state);
            led_state = 1 - led_state; // toggle
        }
    }
}

/** Arrange a u16 value using little-endian format */
static inline void format_u16_le(uint8_t *dst, uint16_t v) {
    dst[0] = (uint8_t)(v & 0xFF);
    dst[1] = (uint8_t)(v >> 8);
}

/** `out_buf` should be able to hold the resulting formatted message */
size_t format_error_response(uint8_t *out_buf, const char *msg, size_t len) {
    acp_response_t resp;
    if (!acp_build_response(&resp, ACP_RESP_ERR, (uint8_t *)msg, len)) {
        return 0;
    }

    return acp_format_response(out_buf, &resp);
}

/** `out_buf` should be able to hold the resulting formatted message */
size_t format_text_response(uint8_t *out_buf, const char *msg, size_t len) {
    acp_response_t resp;
    if (!acp_build_response(&resp, ACP_RESP_TEXT, (uint8_t *)msg, len)) {
        return 0;
    }

    return acp_format_response(out_buf, &resp);
}

size_t format_u16_data_response(uint8_t *out_buf, const uint16_t *data,
                                size_t len) {
    size_t len_bytes = len * 2;
    // ensure data fits in buffer
    if (len_bytes > ACP_RESP_PAYLOAD_SIZE) {
        return 0;
    }

    acp_response_t resp = {.type = ACP_RESP_DATA,
                           .payload_len_bytes = (uint8_t)len_bytes};

    for (size_t i = 0; i < len; i++) {
        format_u16_le(&resp.payload[i * 2], data[i]);
    }

    return acp_format_response(out_buf, &resp);
}

size_t format_u8_data_response(uint8_t *out_buf, const uint8_t *data,
                               size_t len) {
    acp_response_t resp;
    if (!acp_build_response(&resp, ACP_RESP_DATA, (uint8_t *)data, len)) {
        return 0;
    }
    return acp_format_response(out_buf, &resp);
}

void usb_task(void *arg) {
    // avoid using up the task's stack
    static uint8_t tx_buf[ACP_RESP_MAX_SIZE];
    size_t tx_buf_len = 0;
    size_t tx_buf_idx = 0;

    while (1) {
        // tud_task();
        tud_task_ext(1000, false);

        if (tx_buf_len == 0) {
            // if no message is currently in buffer, attempt to get a new one
            size_t n = xMessageBufferReceive(tx_msg_buffer, tx_buf,
                                             sizeof(tx_buf), pdMS_TO_TICKS(5));

            if (n > 0) {
                tx_buf_len = n;
                tx_buf_idx = 0;
            }
        }

        if (tx_buf_len > 0 && tud_cdc_connected()) {
            // if a message is currently in buffer, ensure it's completely sent
            size_t available = tud_cdc_write_available();
            if (available == 0)
                continue;

            size_t remaining = tx_buf_len - tx_buf_idx;
            size_t chunk = remaining > available ? available : remaining;

            tx_buf_idx += tud_cdc_write(tx_buf + tx_buf_idx, chunk);
            if (tx_buf_idx >= tx_buf_len) {
                // the whole buffer was sent, flush and reset state
                tx_buf_idx = 0;
                tx_buf_len = 0;
                tud_cdc_write_flush();
            }
        }
    }
}

void worker_task(void *arg) {
    // assume each response is sent synchronously, so the buffer has at most 1
    // user at a time
    static uint8_t out_buf[ACP_RESP_MAX_SIZE];
    size_t n = 0;

    acp_command_t cmd;
    while (1) {
        xQueueReceive(cmd_queue, &cmd, portMAX_DELAY);

        switch (cmd.type) {
        case ACP_CMD_PING: {
            n = format_text_response(out_buf, "PONG", 4);
            xMessageBufferSend(tx_msg_buffer, out_buf, n, portMAX_DELAY);
            break;
        }
        case ACP_CMD_MEM: {
            // UBaseType_t receiver_stack_free_words =
            //     uxTaskGetStackHighWaterMark(NULL);
            // UBaseType_t sender_stack_free_words =
            //     uxTaskGetStackHighWaterMark(task_handle_usb_sender);

            // char buf[32] = {0};
            // snprintf(buf, sizeof(buf), "Rcvr:%3lu, Sndr:%3lu\n",
            //          receiver_stack_free_words, sender_stack_free_words);
            // cs_build_text_response(&resp, buf);
            // break;
            n = format_u16_data_response(out_buf, TEST_DATA,
                                         sizeof(TEST_DATA) / 2);
            xMessageBufferSend(tx_msg_buffer, out_buf, n, portMAX_DELAY);
            break;
        }
        case ACP_CMD_SET_RES: {
            if (cmd.payload1[0] == '+') {
                if (!cd4066_next()) {
                    cd4066_reset();
                }
            } else if (cmd.payload1[0] == '-') {
                cd4066_prev();
            }

            uint32_t current_value = cd4066_get_current_resistor_ohms();

            // return value in kohms
            n = format_u16_data_response(out_buf,
                                         (uint16_t[]){current_value / 1000}, 1);
            xMessageBufferSend(tx_msg_buffer, out_buf, n, portMAX_DELAY);
            break;
        }
        case ACP_CMD_ADC:
            // start ADC+DMA
            start_adc_dma();
            // block until it finishes
            ulTaskNotifyTake(pdTRUE, portMAX_DELAY);

            n = format_u16_data_response(out_buf, adc_buffer, ADC_NUM_SAMPLES);
            xMessageBufferSend(tx_msg_buffer, out_buf, n, portMAX_DELAY);
            break;
        case ACP_CMD_SET_LED: {
            char *end = NULL;
            // // arg1: led index
            uint32_t index = strtoul(cmd.payload1, &end, 10);
            // // arg2: 24-bit RGB code
            uint32_t rgb = strtoul(cmd.payload2, &end, 16);

            // if (led_ctrl_set_buffer2(index, rgb) == 0) {
            //     HAL_TIM_PWM_Start_DMA(&htim3, TIM_CHANNEL_1,
            //                           (uint32_t *)led_ctrl_get_buffer(),
            //                           led_ct`rl_get_buffer_len());
            //     // block until it finishes
            //     ulTaskNotifyTake(pdTRUE, portMAX_DELAY);
            //     cs_build_text_response(&resp, "OK\n");
            // } else {
            //     cs_build_text_response(&resp, "failed to set LEDs\n");
            // }

            bool ok = ws2812_set_pixel(index, rgb);
            if (ok) {
                ws2812_sync_pixels();
            }

            // devolvemos los valores tal como se interpretaron (idx, r, g, b)
            uint8_t resp[4] = {(uint8_t)index, (uint8_t)(rgb >> 16),
                               (uint8_t)(rgb >> 8), (uint8_t)rgb};

            n = format_u8_data_response(out_buf, resp, 4);
            xMessageBufferSend(tx_msg_buffer, out_buf, n, portMAX_DELAY);
            break;
        }
        case ACP_CMD_INVALID:
        default:
            n = format_error_response(out_buf, "unknown cmd", 11);
            xMessageBufferSend(tx_msg_buffer, out_buf, n, portMAX_DELAY);
            break;
        }
    }
}

void adc_finished_cb() {
    // runs in IRQ context
    stop_adc(true);

    BaseType_t xHigherPrioTaskWoken = pdFALSE;
    vTaskNotifyGiveFromISR(worker_task_handle, &xHigherPrioTaskWoken);

    portYIELD_FROM_ISR(xHigherPrioTaskWoken);
}

void cd4066_make_before_break_delay() { vTaskDelay(pdMS_TO_TICKS(3)); }

int main() {
    /** Peripheral init */
    status_led_init();
    init_adc(BOARD_ADC_CHAN, adc_buffer, ADC_NUM_SAMPLES, adc_finished_cb);
    cd4066_init((uint32_t[]){1000, 10000, 100000},
                (uint32_t[]){BOARD_R1_ENABLE_PIN, BOARD_R10_ENABLE_PIN,
                             BOARD_R100_ENABLE_PIN},
                3, cd4066_make_before_break_delay);
    ws2812_init(BOARD_WS2812_PIN);

    /** Sync primitives init */
    tx_msg_buffer = xMessageBufferCreate(ACP_RESP_MAX_SIZE + sizeof(size_t));
    cmd_queue = xQueueCreate(2, sizeof(acp_command_t));

    // tusb_rhport_init_t dev_init = {
    //     .role = TUSB_ROLE_DEVICE,
    //     .speed = TUSB_SPEED_FULL,
    // };
    tusb_init();

    /** RTOS tasks */
    BaseType_t created =
        xTaskCreate(led_task, "led_task", configMINIMAL_STACK_SIZE, NULL,
                    TASK_DEFAULT_PRIORITY - 1, NULL);
    assert(created == pdPASS);

    created = xTaskCreate(worker_task, "worker_task", configMINIMAL_STACK_SIZE,
                          NULL, TASK_DEFAULT_PRIORITY, &worker_task_handle);
    assert(created == pdPASS);

    created = xTaskCreate(usb_task, "usb_task", configMINIMAL_STACK_SIZE, NULL,
                          TASK_DEFAULT_PRIORITY, &usb_task_handle);
    assert(created == pdPASS);

    blink_enable = true;

    vTaskStartScheduler();
    return 1;
}

// Invoked when cdc when line state changed e.g connected/disconnected
void tud_cdc_line_state_cb(uint8_t itf, bool dtr, bool rts) {
    (void)itf;
    (void)rts;

    // TODO set some indicator
    if (dtr) {
        // Terminal connected
        blink_enable = true;
    } else {
        // Terminal disconnected
        blink_enable = false;
    }
}

// Invoked when device is mounted
void tud_mount_cb(void) { blink_interval_ms = BLINK_MOUNTED; }

// Invoked when device is unmounted
void tud_umount_cb(void) { blink_interval_ms = BLINK_NOT_MOUNTED; }

// Invoked when usb bus is suspended
// remote_wakeup_en : if host allow us  to perform remote wakeup
// Within 7ms, device must draw an average of current less than 2.5 mA from
// bus
void tud_suspend_cb(bool remote_wakeup_en) {
    (void)remote_wakeup_en;
    blink_interval_ms = BLINK_SUSPENDED;
}

// Invoked when usb bus is resumed
void tud_resume_cb(void) {
    blink_interval_ms = tud_mounted() ? BLINK_MOUNTED : BLINK_NOT_MOUNTED;
}

void tud_cdc_rx_cb(uint8_t itf) {
    uint8_t rx_buf[ACP_CMD_MAX_SIZE + 1];

    // for now we expect to receive the whole command at once
    uint32_t n = tud_cdc_read(rx_buf, ACP_CMD_MAX_SIZE);

    if (n == 0)
        return;

    acp_command_t cmd;
    bool result = acp_parse_command(&cmd, rx_buf, n);

    if (result) {
        // notify worker
        xQueueSend(cmd_queue, &cmd, 0);
    } else {
        const char error_msg[] = "comando invalido";
        uint8_t out_buf[12 + sizeof(error_msg)];
        size_t n = format_error_response(out_buf, error_msg, strlen(error_msg));
        // shouldn't be any reason for buffer to be full, so don't block
        xMessageBufferSend(tx_msg_buffer, out_buf, n, 0);
    }
}

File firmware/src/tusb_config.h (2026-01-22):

/*
 * The MIT License (MIT)
 *
 * Copyright (c) 2019 Ha Thach (tinyusb.org)
 *
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
 */

#ifndef _TUSB_CONFIG_H_
#define _TUSB_CONFIG_H_

#ifdef __cplusplus
extern "C" {
#endif

//--------------------------------------------------------------------+
// Board Specific Configuration
//--------------------------------------------------------------------+

// RHPort number used for device can be defined by board.mk, default to port 0
#ifndef BOARD_TUD_RHPORT
#define BOARD_TUD_RHPORT 0
#endif

// RHPort max operational speed can defined by board.mk
#ifndef BOARD_TUD_MAX_SPEED
#define BOARD_TUD_MAX_SPEED OPT_MODE_DEFAULT_SPEED
#endif

//--------------------------------------------------------------------
// COMMON CONFIGURATION
//--------------------------------------------------------------------

// defined by board.mk
#define CFG_TUSB_RHPORT0_MODE OPT_MODE_DEVICE

#ifndef CFG_TUSB_MCU
#define CFG_TUSB_MCU OPT_MCU_RP2040
#endif

#ifndef CFG_TUSB_OS
#define CFG_TUSB_OS OPT_OS_FREERTOS
#endif

#ifndef CFG_TUSB_DEBUG
#define CFG_TUSB_DEBUG 0
#endif

// Enable Device stack
#define CFG_TUD_ENABLED 1

// Default is max speed that hardware controller could support with on-chip PHY
#define CFG_TUD_MAX_SPEED BOARD_TUD_MAX_SPEED

/* USB DMA on some MCUs can only access a specific SRAM region with restriction
 * on alignment. Tinyusb use follows macros to declare transferring memory so
 * that they can be put into those specific section. e.g
 * - CFG_TUSB_MEM SECTION : __attribute__ (( section(".usb_ram") ))
 * - CFG_TUSB_MEM_ALIGN   : __attribute__ ((aligned(4)))
 */
#ifndef CFG_TUSB_MEM_SECTION
#define CFG_TUSB_MEM_SECTION
#endif

#ifndef CFG_TUSB_MEM_ALIGN
#define CFG_TUSB_MEM_ALIGN __attribute__((aligned(4)))
#endif

//--------------------------------------------------------------------
// DEVICE CONFIGURATION
//--------------------------------------------------------------------

#ifndef CFG_TUD_ENDPOINT0_SIZE
#define CFG_TUD_ENDPOINT0_SIZE 64
#endif

//------------- CLASS -------------//
#define CFG_TUD_CDC 1 // Number of CDC to enable
#define CFG_TUD_MSC 0
#define CFG_TUD_HID 0
#define CFG_TUD_MIDI 0
#define CFG_TUD_VENDOR 0

// CDC FIFO size of TX and RX
#define CFG_TUD_CDC_RX_BUFSIZE (TUD_OPT_HIGH_SPEED ? 512 : 64)
#define CFG_TUD_CDC_TX_BUFSIZE (TUD_OPT_HIGH_SPEED ? 512 : 64)

// CDC Endpoint transfer buffer size, more is faster
#define CFG_TUD_CDC_EP_BUFSIZE (TUD_OPT_HIGH_SPEED ? 512 : 64)

#ifdef __cplusplus
}
#endif

#endif /* _TUSB_CONFIG_H_ */

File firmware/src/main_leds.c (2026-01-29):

#include "hardware/gpio.h"
#include "pico/stdlib.h"
#include <stdio.h>

#include "FreeRTOS.h"
#include "task.h"

#include "board.h"
#include "ws2812.h"

TaskHandle_t main_handle;

void error_blink() {
    for (;;) {
        gpio_put(PICO_DEFAULT_LED_PIN, 1);
        vTaskDelay(pdMS_TO_TICKS(2000));
        gpio_put(PICO_DEFAULT_LED_PIN, 0);
        vTaskDelay(pdMS_TO_TICKS(2000));
    }
}

void main_task(void *arg) {
    vTaskDelay(pdMS_TO_TICKS(4000));

    int index = 0;
    uint32_t color;
    while (1) {
        color = 0xff << (4 * index);
        bool result = ws2812_set_pixel(0, color);
        if (!result)
            error_blink();

        printf("set %06x\n", color);
        ws2812_sync_pixels();

        vTaskDelay(pdMS_TO_TICKS(2000));
        ws2812_pixels_off();

        vTaskDelay(pdMS_TO_TICKS(2000));
        index += 1;
        if (index == 6)
            index = 0;
    }
}

int main() {
    stdio_init_all();

    gpio_init(PICO_DEFAULT_LED_PIN);
    gpio_set_dir(PICO_DEFAULT_LED_PIN, GPIO_OUT);
    gpio_put(PICO_DEFAULT_LED_PIN, 0);

    ws2812_init(BOARD_WS2812_PIN);

    BaseType_t created =
        xTaskCreate(main_task, "main_task", configMINIMAL_STACK_SIZE, NULL, 10,
                    &main_handle);
    if (created != pdPASS) {
        gpio_put(PICO_DEFAULT_LED_PIN, 1);
    }

    vTaskStartScheduler();
    return 1;
}

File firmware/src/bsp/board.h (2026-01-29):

#ifndef _BOARD_H_
#define _BOARD_H_

#define BOARD_WS2812_PIN 22

#define BOARD_ADC_CHAN 0

#define BOARD_R1_ENABLE_PIN 18
#define BOARD_R10_ENABLE_PIN 20
#define BOARD_R100_ENABLE_PIN 19

#endif // _BOARD_H_

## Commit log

2024-10-16 init repo, add pico-sdk submodulo
2024-10-24 pico adc test
2024-10-31 test pico adc+dma
2024-11-02 rbg adc + pasa-bajos
2024-11-06 aplicación ejemplo de servidor web
2024-11-07 calibracion sensor
2024-11-09 agrego script para recibir datos por puerto serie y graficar
2024-11-10 se agrega el filtro digital
2024-11-12 programa de calibracion
    lee y filtra los valores muestreados por el ADC y los imprime directamente, sin la conversion a hex RGB.
    Se utilizó para determinar los valores de calibración para superficies negras y blancas. Entre estos dos puntos se linealizan las medidas del sensor.
2024-11-12 se ajustan los valores de calibración. Entrega mediciones aceptables
2024-11-17 titulo de la pagina web
2025-03-05 agrego posibles circuitos
    [fuente-corriente-paralelo-transistores.kicad_pcb, fuente-corriente-paralelo-transistores.kicad_sch, fuente-corriente-paralelo.kicad_pcb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]
2025-03-07 kicad update v9.0
    [fuente-corriente-paralelo-transistores.kicad_sch, fuente-corriente-paralelo.kicad_sch, sensores.kicad_sch]
2025-04-26 pcb con LDRs y led ws2812b-mini
    [fuente-corriente-paralelo-transistores.kicad_pcb, fuente-corriente-paralelo-transistores.kicad_sch, sensores.kicad_sch]
2025-04-26 agrego pico-sdk v2.1.1
2025-05-01 actualización del README y organización de los scripts de python
    [filtro_antialiasing.kicad_pcb, filtro_antialiasing.kicad_sch]
2025-10-21 update pico-sdk
2025-11-21 diseño de carcasa - v1
    incluyo archivos de paleta de colores p/ calibracion y diagrama
    [enclosure_v0.FCStd, enclosure_v1.FCStd]
2025-12-01 circuito acondicionamiento + hoja calibracion
2025-12-02 cambios pre-impresion
    [enclosure_v1.FCStd]
2025-12-02 fix configuracion CMake
    - permite configurar el proyecto sin WiFi SSID/pwd
    - si no hay SSID/pwd, el error se tira al compilar, no al correr cmake
2026-01-09 esquematico circuito acondicionamiento
    [ldr_conditioning_v2.kicad_pcb, ldr_conditioning_v2.kicad_sch]
2026-01-12 doc - proceso de medicion
2026-01-13 comunicacion serial - mensaje de respuesta
2026-01-14 including Unity test framework
    succesfully failed a test!
2026-01-16 ws2812 driver + demo
2026-01-19 Resolución de conflictos de fusión CMakelists
2026-01-19 :hammer: programa para enviar y recibir datos por puerto serie
2026-01-22 parser de comandos y comunicación serial por python
2026-01-23 comando para recibir los datos del adc.
    Por alguna razon, la respuesta del ADC no se envia hasta que el host manda un segundo comando. Hay que debugear
2026-01-28 esquematico actualizado + pico usb-c sym
    [ldr_conditioning_v2.kicad_pcb, ldr_conditioning_v2.kicad_sch]
2026-01-29 programa de prueba p/ leds
2026-01-29 fix respuesta comando ADC
    El problema es que la tarea `usb_task()` recibe las respuestas a traves de un MessageBuffer. No se puede bloquear leyendo este MessageBuffer porque la tarea es responsable de ejecutar todo el stack USB a traves de `tud_task()`, por lo tanto solo se puso un timeout corto de 3ms.
    Como `tud_task()` bloquea indefinidamente cuando procesa todos los eventos del stack, puede que la respuesta no se llegue a leer del MessageBuffer antes de que pasen los 3ms. Esto solo pasaba con el comando ADC, que debia esperar a que el ADC tome las muestras (tarda mas de 3ms), y luego armar la respuesta, por lo tanto `usb_task()` no llegaba a recibir la respuesta a traves del buffer antes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
    [cli.py, main.c, serialpal.py]
2026-01-30 cd4066 resistor picker
2026-01-31 cambios driver cd4066
2026-02-03 integro driver ws2812 + visualizacion de mediciones
2026-02-11 mover logica de decodificacion a clase Response
2026-02-16 respuesta especifica para errores
    [main.c]
2026-02-19 informe desde entrega de avance
2026-02-21 avance informe 21/2 - descripción general - circuito
    [enclosure_v1.FCStd]
2026-04-01 informe-2025 linea de comandos
